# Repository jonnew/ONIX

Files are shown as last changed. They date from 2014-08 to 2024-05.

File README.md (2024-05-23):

# NOTE: This repository has been split into individual `onix-<project>` repos that are hosted on the [open-ephys github account](https://github.com/open-ephys). This repo has been archived.

[ONIX](https://open-ephys.github.io/onix-docs/index.html) is a collection
of [ONI](https://github.com/jonnew/ONI)-compatible hardware and API
for serialized, very-high channel count, closed-loop electrophysiology. It is
an evolution of the first-generation hardware and software introduced in [Open
Ephys project](http://www.open-ephys.org/) and involves many of the same
developers.  The firmware and API are general purpose -- they can be used to
acquire from and control custom headstages with arbitrary arrangements of
sensors and actuators (e.g. cameras, bioamplifier chips, LED drivers, etc.) and
are not limited to the hardware in this repository.

__Documentation__ : https://open-ephys.github.io/onix-docs/index.html

__Citing this work__: 

1. Citing the paper

  - TODO

2. Citing the repository itself

  - 

## Features
- Follows the [ONI](https://github.com/jonnew/ONI)-specification for serialization protocols, host communication
  protocols, device drivers, and host API
- Firmware and API permit acquisition and control of arbitrary arrangements of
  sensors and actuators:

    - Headstages
    - Miniscopes
    - Photometry systems
    - Etc.

- Submillisecond round-trip communication from brain, through host PC's main
  memory, and back again.
- Headstages:

    - 64-, 128-, 256-channels of electrophysiology
    - Optogenetic stimulation
    - Electrical stimulation
    - 3D-pose measurement
    - Data, user control, and power via a tiny coaxial cable
    - Wireless communication

- Low-level API implementation
- High-level API language bindings and existing integration with [Open Ephys
  GUI](http://www.open-ephys.org/gui/) and [Bonsai](http://bonsai-rx.org/).
- Quality documentation and easy routes to purchasing assembled devices.

## Software

1. API: https://github.com/jonnew/liboni
2. Bonsai package: coming soon
3. Open Ephys GUI plugin: coming soon

## Hardware

### [eib-64](eib-64/README.md)
64 Channel electrode interface board. Designed for small rodent tetrode
electrophysiology. Works with [headstage-64](./headstage-64/README.md).

### [eib-128](eib-128/README.md)
128 Channel electrode interface board. Designed for large rodent tetrode
electrophysiology. Works with [headstage-256](./headstage-256/README.md).

### [eib-256](eib-256/README.md)
256 Channel electrode interface board. Designed for large rodent tetrode
electrophysiology. Works with [headstage-256](./headstage-256/README.md).

### [headstage-64](headstage-64/README.md)
Serialized, multifunction headstage for small rodents. Supports 64 channels.
Designed to interface with [eib-64](./eib-64/README.md).

### [headstage-256](headstage-256/README.md)
Serialized, multifunction headstage for large rodents. Supports both 128 or 256
channels. Designed to interface with [eib-128](./eib-128/README.md) or
[eib-256](./eib-256/README.md)

### [fmc-host](fmc-host/README.md)
Base board for facilitating PCIe communication, via FMC compatiable and
PCIe-capable FPGA based board (e.g. [Numato Lab
Nereid](https://numato.com/product/nereid-kintex-7-pci-express-fpga-development-board).
This board plugs into the FMC connector on the base board. It provides
communication with one headstage and lots of other analog and digital IO.

### [analog-io-breakout](analog-io-breakout/README.md)
Passive breakout board for acquiring and generating analog signals through BNC,
SMA, ribbon, or straight wire connections. Plugs into fmc-host using a 26-pin
shrunk delta ribbon cable.

### [nanoz-adapter-64](./nanoz-adapter-64/README.md)
Adapter to interface eib-64 with the popular
[nanoZ](http://www.white-matter.com/nanoz/) electrode impedance tester and
plating device.

### [nanoz-adapter-128-256](./nanoz-adapter-128-256/README.md)
Multiplexed adapter to interface eib-128 and eib-256 with the popular
[nanoZ](http://www.white-matter.com/nanoz/) electrode impedance tester and
plating device.

### [test-board-64](./test-board-64)
Test board for headstage-64. Allows injecting simulated biopotentials into
headstage modules via a selectable passive attenuator. Provides LEDs and
simulated electrical loads for optical and electrical stimulation.

### [test-board-128-256](./test-board-128-256)
Test board for headstage, and headstage-256 modules. Allows injecting simulated
biopotentials into headstage modules via a selectable passive attenuator.
Provides LEDs and simulated electrical loads for optical and electrical
stimulation.

### [headstage-programmer](headstage-programmer/README.md)
JTAG breakout for the [Intel USB Blaster 2](https://www.digikey.com/short/qqw7hm)
used to program the headstages' MAX10 FPGA.

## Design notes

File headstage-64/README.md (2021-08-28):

:warning: This project has moved to a dedicated repository: https://github.com/open-ephys/onix-headstage-64
This folder should be considered archived.

# headstage-64
Serialized, multifunction headstage for small rodents. Designed to function
with [eib-64](../eib-64/README.md).

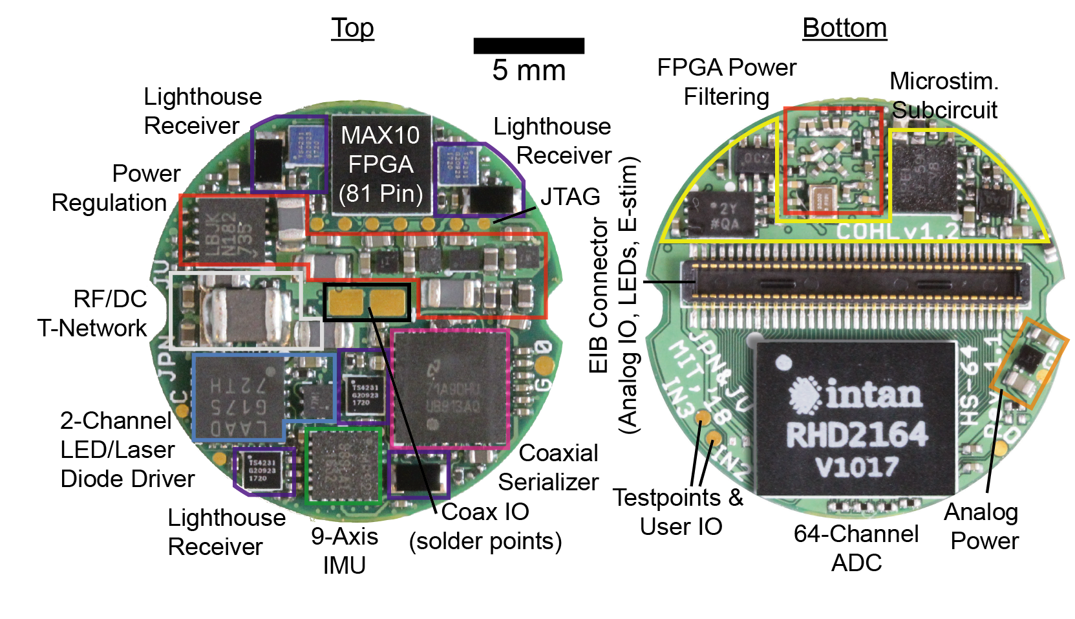
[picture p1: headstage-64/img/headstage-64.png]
headstage-64


## Electrophysiology
This heastage uses an [Intan RHD2164]() bioamplifier chip. This chip provides:
- 64 channels of ephys are pinned out through the large mezzanine connector on the
  bottom of the headstage
- 3 auxiliary channels
    - AUX 1 and 2 are pinned out on the bottom of the headstage to an unpopulated
      mezzanine connector
    - Channel 3 is tied to the electrical stimulator's current measurement circuit

## 3D Position Tracking
Headstage-64 featurs 4 TS4231 Vive lighthouse receivers for 3D position
tracking. They work with V2 lighthouses. To set up tracking,

1. Serial into each of the basestations using the USB connection on the back
   and set up a terminal conneciton using `screen /dev/ttyACM0 115200` or
   similar

2. Once connected you can hit Tab to see commands

3. Set the mode of one base staiton to 1 (mode 1) and the other to 2 (mode 2).

## 3D Orientation Tracking
TODO

## Neural Stimulators
Headstage-64 provides onboard electrical and optical stimulation. Stimulus
trains can be parameterized in a similar way to the master-8 or pulse pal.
Electical and optical stimulus trains cannot be delivered simultaneously.
If there is a conflict, electical stimuluation will take priority and optical
stimulus triggers will be ignored.

To acheive the shortest latency, electrical and optical stimulation can be triggered
using the GPIO1 serializer output. Because both stimulators share this trigger line,
it is important to only enable one of the devices (using its ENABLE register) prioir
to toggling this pin.

### Optical Stimulation

Q. Can i parallel the Cathode connections to increase max current
A. Yes.

### Electical Stimulation
The electrical stimulation cicuit is an improved Howland current pump followed by
an precision current measurement circuit. The current pump is supplied by +/-15V
rails and can supply up to +/- 2.5 mA. The output c

ISTIM = (VDAC  - 2.5)/1000.
e.g.
VDAC = 2.5   -> ISTIM = 0
VDAC = 5.0   -> ISTIM = 2.5 mA
VDAC = 0.0   -> ISTIM = -2.5mA

and

Imeas = 400 * ISTIM + 1.25V
e.g.
ISTIM = 0      -> IMEAS = 1.25V
ISTIM = 2.5mA  -> IMEAS = 2.25V
ISTIM = -2.5mA -> IMEAS = 0.25V

## Schematic
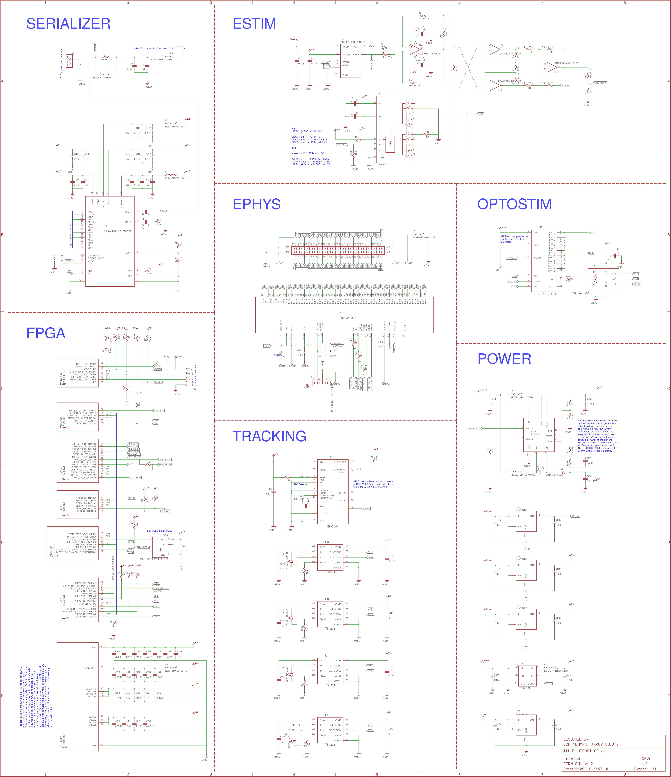
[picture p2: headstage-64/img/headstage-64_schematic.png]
headstage-64 Schematic


## Gerber Files
{% include gerber_layers.md %}

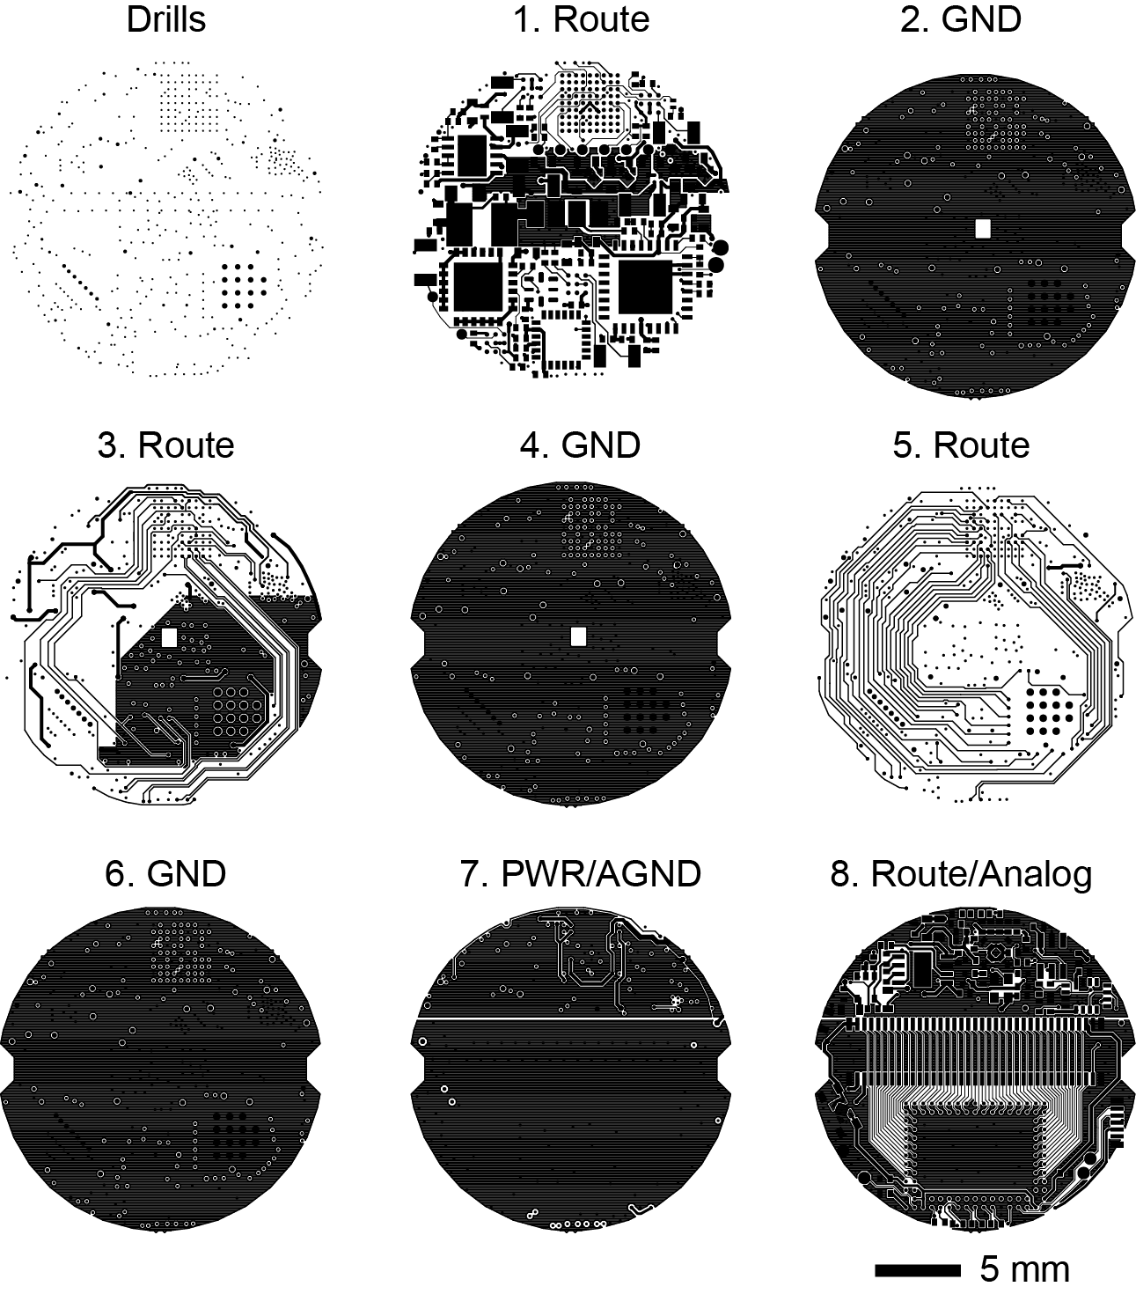
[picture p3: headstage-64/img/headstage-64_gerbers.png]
headstage-64 Gerbers


## Bill of Materials
The BOM is located on [this google
sheet](https://docs.google.com/spreadsheets/d/1F-KWcdvH_63iXjZf0cgCfDiFX6XXW3qw6rlR8DZrFpQ/edit#gid=138167638).

## FPGA Pinout
The FPGA pinout is located on [this google
sheet](https://docs.google.com/spreadsheets/d/1oJoQ89dJNL9LIiTrRnwJ_9KGiLzJ53Tju5Lfchuvsb0/edit#gid=2100166621).

## Connector Pinout
The headstage connector pinout (ADC input mapping, stimulation connections,
etc) is located on [this google
sheet](https://docs.google.com/spreadsheets/d/11wRDYOqHN5lPb03yUdfXfK0zvaDYsVetplaNK-R90Gg/edit#gid=663991061)

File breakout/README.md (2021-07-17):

:warning: This project has moved to a dedicated repository: https://github.com/open-ephys/onix-breakout
This folder should be considered archived.

# ONIX Breakout Board
This board allows bench access to the IO provided by the
[fmc-host board](../fmc-host/README.md). It features:

- 4x headstage ports, each with a power switch
- 3x, passive, high-seed clock feed throughs
- BNC, IDC (ribbon), or direct wire access to 12 analog inputs or outputs
- IDC (ribbon) or direct wire access to 8 digital outputs and 8 digital inpouts
- 6 buttons for marking experimental events
- 41 state-indication LEDs
- Full-speed, USB 2.0 access to the onboard [TinyFPGA
  BX](https://www.crowdsupply.com/tinyfpga/tinyfpga-bx) for communication,
  programming, and customization 
- HARP bus
- Rugged M6 or 1/4-20 mounting options compliant with 19" racks and optical
  tables
- Fully open-source gateware and use of fully open-source FPGA toolchain (yosys
  & nextpnr)

## Documentation
Documentation can be found
[here](https://open-ephys.github.io/onix-docs/Hardware%20Guide/Breakout%20Boards/breakout_1r4.html)

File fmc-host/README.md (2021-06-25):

:warning: This headstage has moved to a dedicated repository: https://github.com/open-ephys/onix-fmc-host.
This folder should be considered archived.

# FMC Host Board
This card serves as host interface for serialized headstages and miniscopes, as
well as general purpose analog and digital IO. This board is a VITA-57.1
compliant module that uses high pin-count FMC connector. In combination with a
base FPGA board (e.g. [Numato Lab
Nereid](https://numato.com/product/nereid-kintex-7-pci-express-fpga-development-board),
it provides host PC communication for the following:

- Two deserailizers for any multifunction headstage conforming to our
  serialization protocol
- 12x 16-bit, +/-10V analog outputs or inputs. Direction selected via analog
  switch controllable over the FMC connector. Analog inputs are separated into
  2 simultaneously sampled 6-channel banks. When analog outputs are used, they
  are are always looped back using the analog inputs.
- 3x high speed LVDS input pairs
- 2x high speed LVDS outputs pairs
- 2x high speed, arbitrary logic-level, singled-ended lock inputs
- 1x high speed single ended, 50 ohm clock output
- 4x MLVDS input or output trigger lines

Easy access to IO is provided by the [breakout board](../breakout/README.md).

pcie-host

## Gerber Files
{% include gerber_layers.md %}

## Bill of Materials
The bill of materials for this device can be found
[here](https://docs.google.com/spreadsheets/d/1F-KWcdvH_63iXjZf0cgCfDiFX6XXW3qw6rlR8DZrFpQ/edit#gid=1976092058).

## Manufacturing Requirements
In order to meet approximately correct trace impedances, the design assumes the following stackup:

1. Top Copper 0.035 mm
1. Prepreg (2313\*1) 0.1 mm
1. Inner Copper 0.0175 mm
1. Core (Copper) 0.565 mm
1. Inner Copper 0.0175 mm
1. Prepeg (2116\*1) 0.127 mm
1. Inner Copper 0.0175 mm
1. Core (Copper) 0.565 mm
1. Inner Copper 0.0175 mm
1. Prepreg (2313\*1) 0.1 mm
1. Bottom Copper 0.0175 mm

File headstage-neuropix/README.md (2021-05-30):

# ONIX headstage-neuropix1

:warning: This headstage has moved to a dedicated repository: https://github.com/open-ephys/onix-headstage-neuropix1.
This folder should be considered archived.

Serialized, multifunction headstage targeting the neuropixels 1.0 probe. This
headstage supports serialized acquisition from:

- Two neuropixels 1.0 probes
- A BNO055 9-axis IMU for real-time, 3D orientation tracking
- Three TS4231 light to digital converters for real-time, 3D position tracking
  with HTC Vive base stations
- A high performance MAX10 FPGA for real-time processing and probe data
  correction (offset removal and gain correction)

There are two versions of this headstage in this repository, one that uses the
standard IMEC-specified ZIF connector and a second that uses a larger, more
reliable one.

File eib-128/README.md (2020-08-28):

# eib-128
128-channel electrode interface board (EIB) with electrical and optical
stimulation. Designed for large animal (e.g. rat) tetrode electrophysiology.
Compatible with [headstage-256](../headstage-256/) and large shuttle-drives.

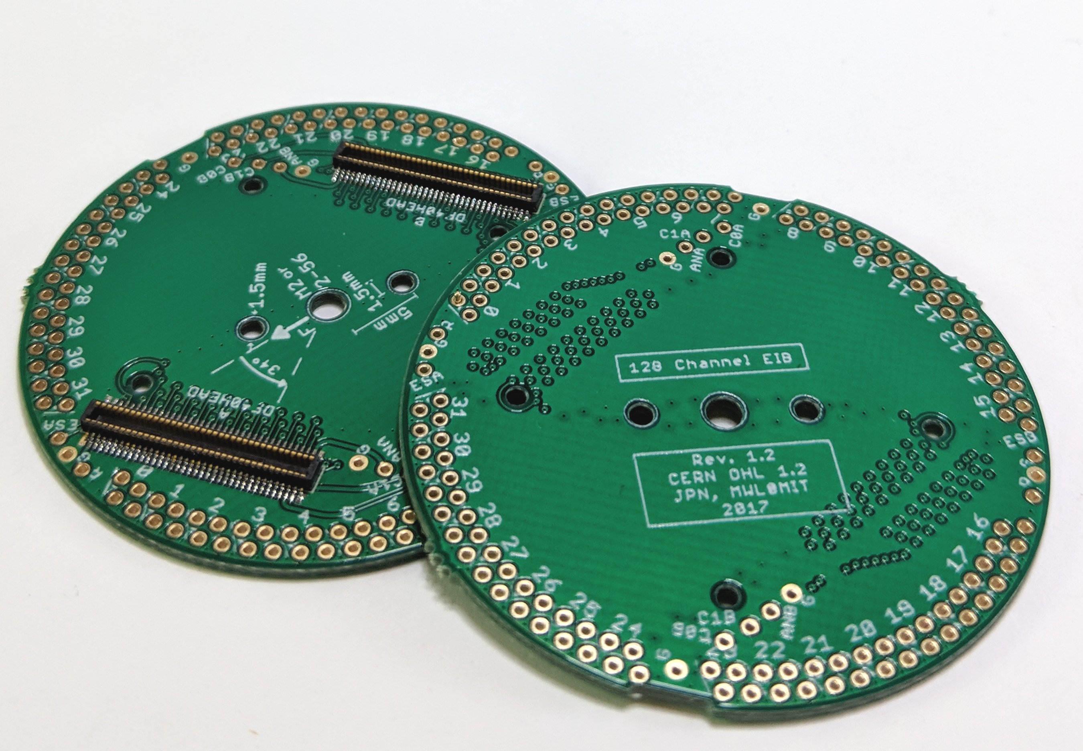
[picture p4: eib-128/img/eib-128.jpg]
eib-256


## Gerber Files
{% include gerber_layers.md %}

## Bill of Materials
The BOM is located on [this google
sheet](https://docs.google.com/spreadsheets/d/1F-KWcdvH_63iXjZf0cgCfDiFX6XXW3qw6rlR8DZrFpQ/edit#gid=1129179247).

## Pinout
The EIB pinout (ADC input mapping, stimulation connections, etc) is located on
[this google
sheet](https://docs.google.com/spreadsheets/d/11wRDYOqHN5lPb03yUdfXfK0zvaDYsVetplaNK-R90Gg/edit#gid=663991061)

## Tetrode Connectorization
This EIB uses Neuralynx ["large" gold pins](https://neuralynx.com/hardware/large-eib-pins) to attach tetrode wires. Usage instructions are provided in the [Neuralynx EIB pin Manual](https://neuralynx.com/documents/EIB%20Pins%20Manual.pdf).

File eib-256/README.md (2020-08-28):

# eib-256
256-channel electrode interface board (EIB) with electrical and optical
stimulation. Designed for large animal (e.g. rat) tetrode electrophysiology.
Compatible with [headstage-256](../headstage-256/) and large shuttle-drives.

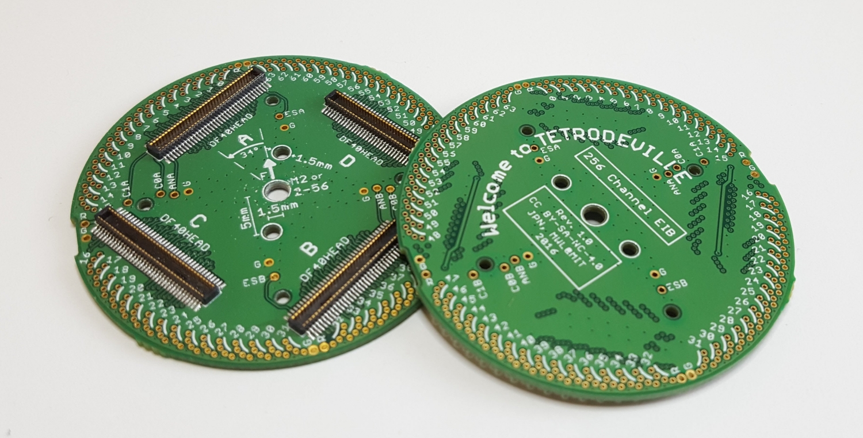
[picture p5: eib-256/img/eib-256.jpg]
eib-256


## Gerber Files
{% include gerber_layers.md %}

## Bill of Materials
The BOM is located on [this google
sheet](https://docs.google.com/spreadsheets/d/1F-KWcdvH_63iXjZf0cgCfDiFX6XXW3qw6rlR8DZrFpQ/edit#gid=1934583654).

## Pinout
The EIB pinout (ADC input mapping, stimulation connections, etc) is located on [this google sheet](https://docs.google.com/spreadsheets/d/11wRDYOqHN5lPb03yUdfXfK0zvaDYsVetplaNK-R90Gg/edit#gid=0)

## Tetrode Connectorization
This EIB uses Neuralynx ["small" gold pins](https://neuralynx.com/hardware/small-eib-pins) to attach tetrode wires. Usage instructions are provided in the [Neuralynx EIB pin Manual](https://neuralynx.com/documents/EIB%20Pins%20Manual.pdf).

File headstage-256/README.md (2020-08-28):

# headstage-256
Serialized, multifunction headstage for large rodents. Supports both 128 or 256
channels. Designed to interface with [eib-128](../eib-128/README.md) or
[eib-256](../eib-256/README.md)

headstage-256

## Schematic 
headstage-256 Schematic

## Gerber Files
{% include gerber_layers.md %}

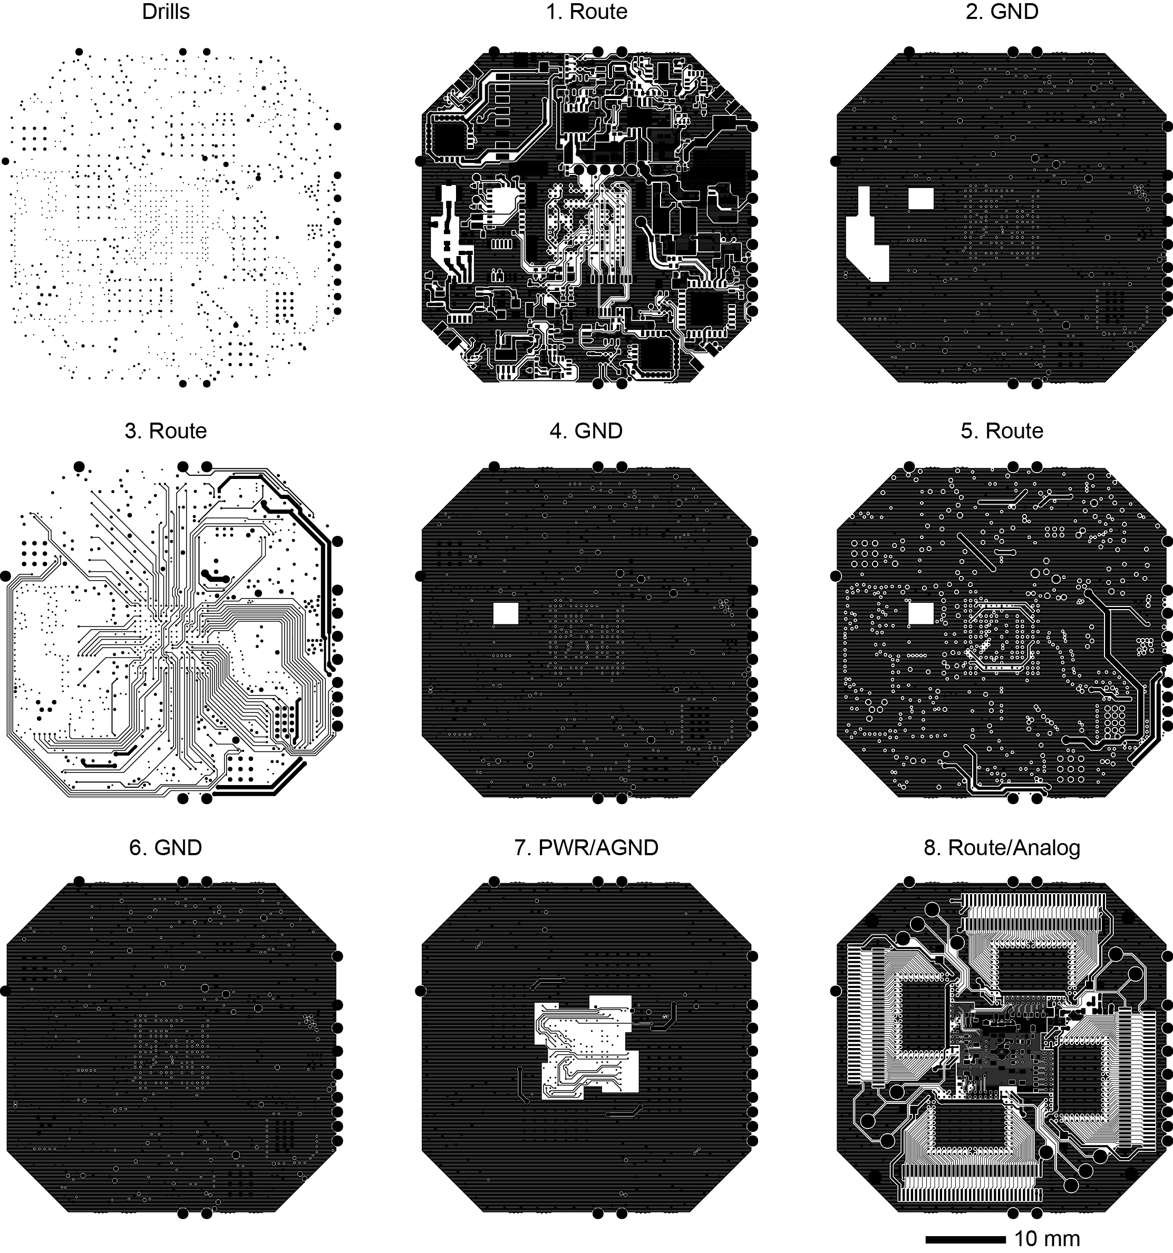
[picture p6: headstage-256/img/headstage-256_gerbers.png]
headstage-256 Gerbers


## Bill of Materials
The BOM is located on [this google
sheet](https://docs.google.com/spreadsheets/d/1F-KWcdvH_63iXjZf0cgCfDiFX6XXW3qw6rlR8DZrFpQ/edit#gid=1075887549)

## FPGA Pinout
The FPGA pinout is located on [this google
sheet](https://docs.google.com/spreadsheets/d/1oJoQ89dJNL9LIiTrRnwJ_9KGiLzJ53Tju5Lfchuvsb0/edit#gid=1588805600)

## Connector Pinout
The headstage connector pinouts (ADC input mapping, stimulation connections,
etc) ares are located on these google sheets:

- [eib-128 channel mapping](https://docs.google.com/spreadsheets/d/11wRDYOqHN5lPb03yUdfXfK0zvaDYsVetplaNK-R90Gg/edit#gid=663991061)
- [eib-256 channel mapping](https://docs.google.com/spreadsheets/d/11wRDYOqHN5lPb03yUdfXfK0zvaDYsVetplaNK-R90Gg/edit#gid=538743909)

## Expansion Boads
headstage-256 has two exposed headers that supply power and general purpose analog or digital IO to expand 
its functionality. Subdirectories with the prefix 'expansion` are boards that fit into these headers to 
supply various auxiliary functions. These include:

1. expansion-uphone: ultrasonic micrphone expansion board
2. expansion-long-range: large active area light house receiver board to expand 3D tracking range by several meters.
3. expansion-debug: pinout GPIO to large 0.1" pitch headers.

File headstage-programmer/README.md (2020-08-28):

# headstage-programmer
JTAG breakout for the [Intel USB Blaster
2](https://www.digikey.com/short/qqw7hm) used to program the headstages' MAX10
FPGA.

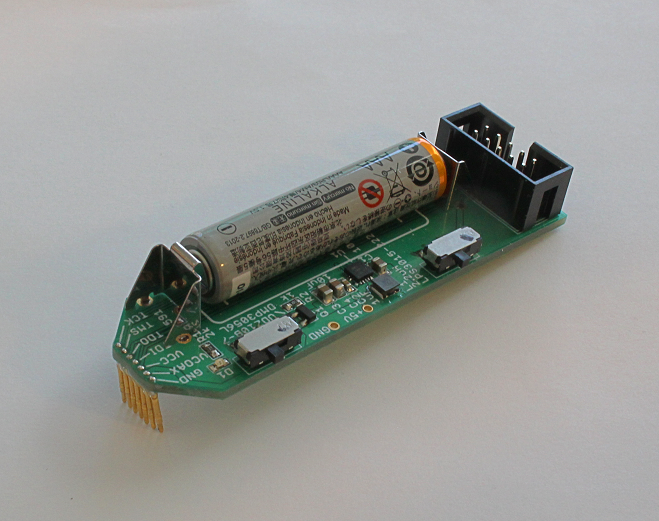
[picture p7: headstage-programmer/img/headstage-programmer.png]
headstage-programmer


## Schematic
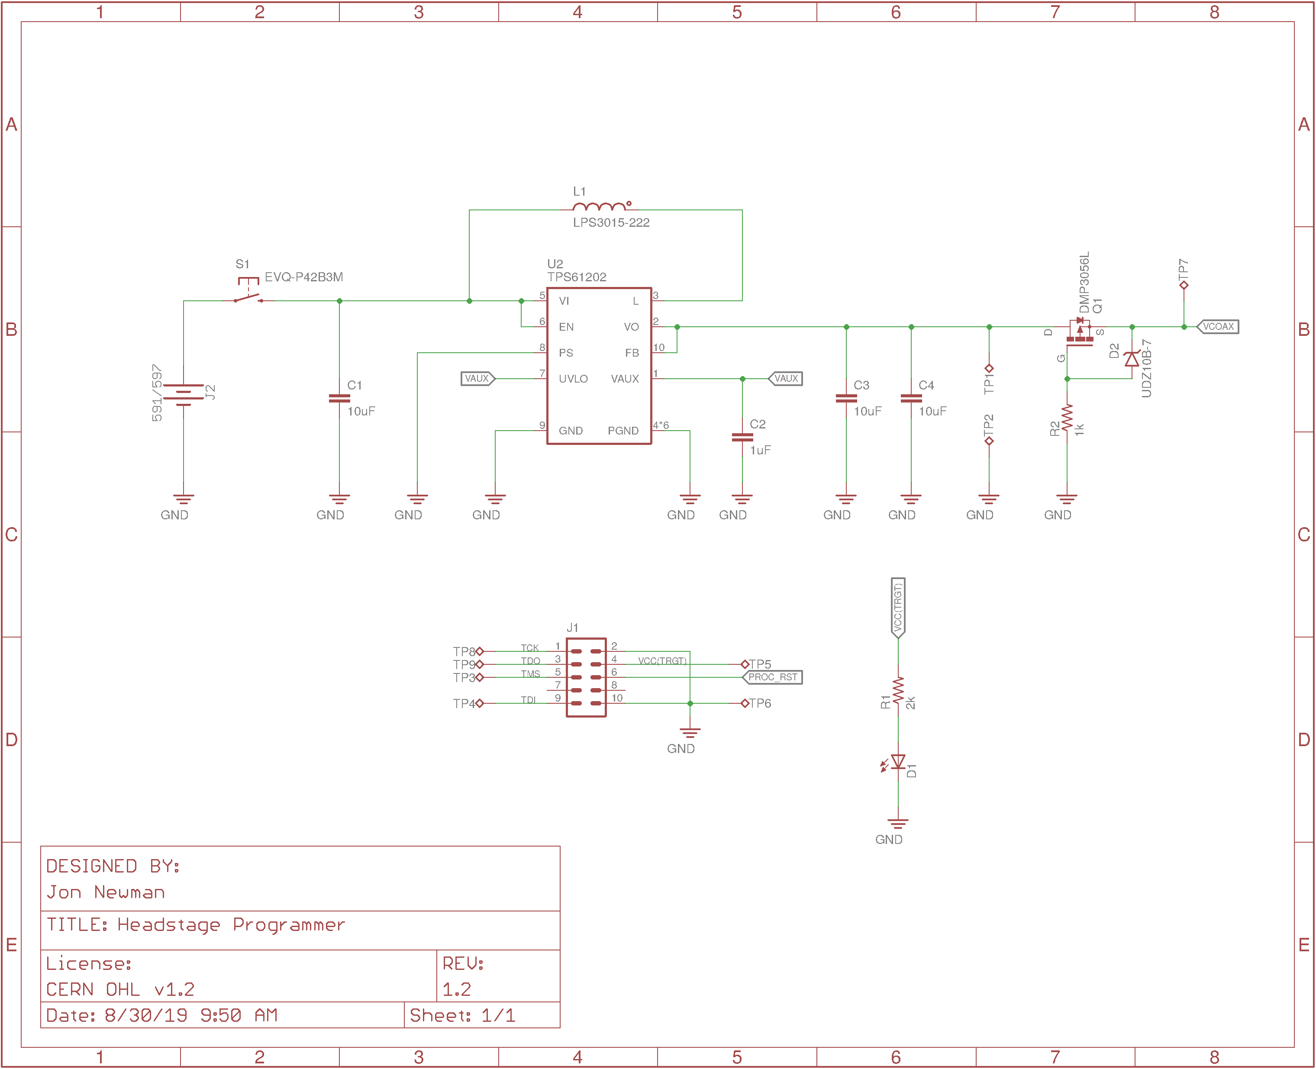
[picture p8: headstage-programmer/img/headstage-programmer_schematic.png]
headstage-programmer Schematic


## Purpose
The dense layout required by the headstages in this repository makes exposing a
FPGA programming interface challenging. We have chosen to expose a JTAG
programming interface as a linear, 50 mil pitch array of small copper ["test
points"](https://en.wikipedia.org/wiki/Test_point). This programmer adapter
routes JTAG signals through a set of small ["pogo
pins"](https://en.wikipedia.org/wiki/Pogo_pin) that can reliably make a
temporary electrical connection with the test point array. Additionally, it
contains a AAA battery and boost converter to generate power for the headstage
during programming and to illuminate a white LED on the bottom of the board
that eases pogo-pin/test-point alignment.

## Gerber Files
{% include gerber_layers.md %}

## BOM
The BOM is located on [this google
sheet](https://docs.google.com/spreadsheets/d/1F-KWcdvH_63iXjZf0cgCfDiFX6XXW3qw6rlR8DZrFpQ/edit#gid=673969549).

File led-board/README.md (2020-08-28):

# led-board
Simple board for making pig-tailed, drivable stimulation LEDs for optogenetic
manipulation.

## Gerber Files
{% include gerber_layers.md %}

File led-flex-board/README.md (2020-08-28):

### led-flex-board
Simple flexible board for making pig-tailed, driveable stimulation LEDs for
optogenetic manipulation using standard chip scale LEDs or direct-attach micro
LEDs.

## Gerber Files
{% include gerber_layers.md %}

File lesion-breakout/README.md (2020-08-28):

# Electro-lesioning breakout boards
These boards provide easy access to each tetrode on
[eib-64](../eib-64/README.md), [eib-128](../eib-128/README.md), and
[eib-256](../eib-256/README.md) for electro-lesioning or connectivity testing.

## Gerber Files
{% include gerber_layers.md %}

## Bill of Materials
The BOM is located on [this google
sheet](https://docs.google.com/spreadsheets/d/1F-KWcdvH_63iXjZf0cgCfDiFX6XXW3qw6rlR8DZrFpQ/edit#gid=1934583654).

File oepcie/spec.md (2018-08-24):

---
title: |
    Open Ephys++ Communication Protocol and API Specification \
    Version 0.0
author: Jonathan P. Newman, Wilson Lab, MIT
institution:
date: \today{}
geometry: margin=2cm
header-includes:
    - \usepackage{setspace}
    - \usepackage{lineno}
    - \linenumbers
colorlinks: true
toc: true
toc-depth: 2
secnumdepth: 2
abstract: |
    This document specifies requirements for implementing the Open Ephys++ data
    acquisition system. This specification entails two basic elements: (1)
    Communication protocols between acquisition firmware and host software and
    (2) an application programming interface (API) for utilizing this
    communication protocol. This document is incomplete and we gratefully
    welcome criticisms and amendments.
---

\newpage
# Intentions and capabilities
- Low latency (sub millisecond)
- High bandwidth (> 1000 neural data channels)
- Bidirectional
- Acquisition and control of arbitrary of hardware components using a single
  communication medium
    - Support generic mixes of hardware elements
    - Generic hardware configuration
    - Generic data input stream
    - Generic data output stream
- Support multiple acquisition systems on one computer
- Cross platform
- Low level: aimed at the creation of language bindings and
  application-specific libraries

\newpage
# FPGA/Host PC communication {#comm-protocol}
Communication between the acquisition board firmware and API shall occur
over four communication channels:

1. Signal: Read-only, short-message, asynchronous hardware events
2. Configuration: Bidirectional, register-based, synchronous configuration
   setting and getting
3. Input: Read-only, asynchronous, high-bandwidth firmware to host streaming
4. Output: Write-only, asynchronous, high-bandwidth host to firmware streaming

Required characteristics of these channels are described in the following
paragraphs.

## Signal channel (8-bit, asynchronous, read only) {#sig-chan}
The _signal_ channel provides a way for the FPGA firmware to inform host of
configuration results, which may be provided with a significant delay.
Additionally, it allows the host to read the device map supported by the FPGA
firmware. The behavior of the signal channel is equivalent to a read-only,
blocking UNIX named pipe. Signal data is framed into packets using Consistent
Overhead Byte Stuffing
([COBS](https://en.wikipedia.org/wiki/Consistent_Overhead_Byte_Stuffing)).
Within this scheme, packets are delimited using 0's and always have the
following format:

```
... | PACKET_FLAG data | ...
```

where `PACKET_FLAG` is 32-bit unsigned integer with a single unique bit
setting, ` | ` represents a packet delimiter, and `...` represents other
packets. This stream can be read and ignored  until a desired packet is
received. Reading this stream shall block if no data is available, which allows
asynchronous configuration acknowledgment. Valid `PACKET_FLAG`s are:

``` {.c}
enum signal {
    NULLSIG      = (1u << 0), // Null signal, ignored by host
    CONFIGWACK   = (1u << 1), // Configuration write-acknowledgment
    CONFIGWNACK  = (1u << 2), // Configuration no-write-acknowledgment
    CONFIGRACK   = (1u << 3), // Configuration read-acknowledgment
    CONFIGRNACK  = (1u << 4), // Configuration no-read-acknowledgment
    DEVICEMAPACK = (1u << 5), // Device map start acknowledgment
    DEVICEINST   = (1u << 6), // Device map instance
};
```

Following a hardware reset, the signal channel is used to provide the device
map to the host using the following packet sequence:

```
... | DEVICEMAPACK, uint32_t num_devices | DEVICEINST device dev_0
    | DEVICEINST device dev_1 | ... | DEVICEINST device dev_n | ...
```

Following a device register read or write (see [configuration
channel](#conf-chan)), ACK or NACK signals are pushed onto the signal stream by
the firmware. For instance, on a successful register read:

```
... | CONFIGRACK, uint32_t register value | ...
```

## Configuration channel (32-bit, synchronous, read and write) {#conf-chan}
The _configuration_ channel supports seeking to, reading, and writing a set of
configuration registers. Its behavior is equivalent to that of a normal UNIX
file. There are two classes of registers handled by the configuration channel:
the first set of registers encapsulates a generic device register programming
interface. The remaining registers are for global context control and
configuration and provide access to acquisition parameters and state control.
`SEEK` locations of each configuration register, relative to the start of the
stream, should be hard-coded into the API implementation file and used in the
background to manipulate register state.

### Device register programming interface

The device programming interface is composed of the following configuration
channel registers:

- `uint32_t config_device_id`: Device ID register. Specify a device endpoint as
  enumerated by the firmware (e.g. an Intan chip, or a IMU chip) and to which
  communication will be directed using `config_reg_addr` and
  `config_reg_value`, as described below.

- `uint32_t config_reg_addr`: The register address of configuration to be
  written

- `uint32_t config_reg_value`: configuration value to be written to or read
  from and that corresponds to `config_reg_addr` on device `config_device_id`

- `uint32_t config_rw`: A flag indicating if a read or write should be
  performed.  0 indicates read operation. A value > 0 indicates write
  operation.

- `uint32_t config_trig`: Set > 0 to trigger either register read or write
  operation depending on the state of `config_rw`. If `config_rw` is 0, a read
  is performed. In this case `config_reg_value` is updated with value stored at
  `config_reg_addr` on device at `config_device_id`. If `config_rw` is 1,
  `config_reg_value` is written to register at `config_reg_addr` on device
  `config_device_id`. The `config_trig` register is always be set low by the
  firmware following transmission even if it is not successful or does not make
  sense given the address register values.

Appropriate values of `config_reg_addr` and `config_reg_value` are
determined by:

- Looking at a device's data sheet if the device is an integrated circuit
- Examining the open ephys++ devices header file (oedevices.h) which
  contains off register addresses and descriptions for devices officially
  supported by this project (device id < 10000).

When a host requests a device register _read_, the following following actions
take place:

1. The value of `config_trig` is checked.
    - If it is 0x00, the function call proceeds.
    - Else, the function call returns with an error specifying a retrigger.
1. `dev_idx` is copied to the `config_device_id` register on the host FPGA.
1. `addr` is copied to the `config_reg_addr` register on the host FPGA.
1. The `config_rw` register on the host FPGA is set to 0x00.
1. The `config_read_trig` register on the host FPGA is set to 0x01,
triggering configuration transmission by the firmware.
1. (Firmware) A configuration read is performed by the firmware.
1. (Firmware) `config_trig` is set to 0x00 by the firmware.
1. (Firmware) `CONFIGRACK` is pushed onto the signal stream by the
firmware.
1. The signal stream is pumped until either `CONFIGRACK` or `CONFIGRNACK` is
   received indicating that the host FPGA has either:
    - Completed reading the specified device register and copied its value to
      the `config_reg_value` register.
    - Failed to read the register in which case the value of `config_reg_value`
      contains garbage.

When a host requests a device register _write_, the following following actions
take place:

1. The value of `config_trig` is checked.
    - If it is 0x00, the function call proceeds.
    - Else, the function call returns with an error specifying a retrigger.
1. `dev_idx` is copied to the `config_device_id` register on the host FPGA.
1. `addr` is copied to the `config_reg_addr` register on the host FPGA.
1. `value` is copied to the `config_reg_value` register on the host FPGA.
1. The `config_rw` register on the host FPGA is set to 0x01.
1. The `config_trig` register on the host FPGA is set to 0x01, triggering
configuration transmission by the firmware.
1. (Firmware) A configuration write is performed by the firmware.
1. (Firmware) `config_trig` is set to 0x00 by the firmware.
1. (Firmware) `CONFIGWACK` is pushed onto the signal stream by the
firmware.
1. The signal stream is pumped until either `CONFIGWACK` or `CONFIGwNACK` is
   received indicating that the host FPGA has either:
    - Successfully completed writing the specified device register
    - Failed to write the register

Following successful or unsuccessful device register read or write, the
appropriate ACK or NACK packets _must_ be passed to the [signal
channel](#sig-chan). If they are not, the register read and write calls will
block indefinitely.

### Global acquisition registers
The following global acquisition registers provide information about, and
control over, the entire acquisition system:

- `uint32_t running`: set to > 0 to run the system clock and produce data. Set
  to 0 to stop the system clock and therefore stop data flow. Results in no
  other configuration changes.

- `uint32_t reset`: set to > 0 to trigger a hardware reset and send a fresh
  device map to the host and reset hardware to its default state. Set to 0 by
  host firmware upon entering the reset state.

- `uint32_t sys_clock_hz`: A read-only register specifying the base hardware
  clock frequency in Hz. The clock counter in the read [frame](#frame) header
  is incremented at this frequency.

## Data input channel (32-bit, asynchronous, read-only)
The _data input_ channel provides high bandwidth communication from the FPGA
firmware to the host computer using direct memory access (DMA). From the host's
perspective, its behavior is equivalent to a read-only, blocking UNIX named
pipe with the exception that data can only be read on 32-bit, instead of 8-bit,
boundaries. The data input channel communicates with the host using
[frames](#frame) with a read-header ("read-frames") .Read-frames are pushed
into the data input channel at a rate dictated by the FPGA firmware. It is
incumbent on the host to read this stream fast enough to prevent buffer
overflow. At the time of this writing, a typical implementation will allocate
an input buffer that occupies a 512 MB segment of kernal RAM. Increased
bandwidth demands will necessitate the creation of a user-space buffer. This
change shall have no effect on the API.

## Data output channel (32-bit, asynchronous, write-only)
The _data output_ channel provides high bandwidth communication from the host
computer to the FPGA firmware using DMA via calls. From the host's perspective,
its behavior is equivalent to a write-only, blocking UNIX named pipe with the
exception that data can only be written on 32-bit, instead of 8-bit,
boundaries. Its performance characteristics are largely identical to the data
input channel.

\newpage

# Required API Types and Behavior {#api-spec}
In the following sections we define required API datatypes and how they are
used by the API to communicate with hardware. An implementation of this API,
[liboepcie](#api-imp), follows.

## Context
A _context_ shall hold all state required to manage single [FPGA/Host
communication system](#comm-protocol). This includes a
map of devices being acquired from, data buffering elements, etc. API calls
will typically take a context handle as the first argument and use it to
reference required state information to enable communication and/or to mutate
the context to reflect some function side effect (e.g. add device map
information):

```
int api_function(context *ctx, ...);
```

## Device
A _device_ is defined as configurable piece of hardware with its own register
address space (e.g. an integrated circuit) or something programmed within the
firmware to emulate this (e.g. an electrical stimulation sub-circuit made to
look like a Master-8). Host interaction with a device is facilitated using a
device description, which should hold the following elements:

- `device_id`: Device ID number
- `read_size`: Device data read size per frame in bytes
- `num_reads`: Number of frames that must be read to construct a full
  sample (e.g., for row reads from camera)
- `write_size`: Device data write size per frame in bytes
- `num_writes`: Number of frames that must be written to construct a full
  output sample

An array of structures holding each of these entries forms a _device map_.  A
context is responsible for managing a single device map, which keep track of
where to send and receive streaming data and configuration information during
API calls. A detailed description of each of each value comprising a device
instance is as follows:

1. `device_id`: Device identification number which is globally
   enumerated for the entire project
    - There is a single `enum` for the entire library which enumerates all
      possible devices that are controlled across `context` configurations.
      This enumeration will grow with the number of devices supported by the
      library.
    - e.g. A host board GPIO subcircuit is 0, Intan RHD2132 is 1, Intan
      RHD2164 is 2, etc.
    - Device IDs up to 9999 are reserved. Device ID 10000 and greater are free
      to use for custom hardware projects.
    - The use of device IDs less than 10000 not specified within this
      enumeration will result in OE_EDEVID errors.
    - Device numbers greater than 1000 are allowed for general purpose use and
      will not be verified by the API.
    - Incorporation into the official device enum (device IDs < 10000) can be
      achieved via pull-request to this repo.

2. `read_size`: Number of bytes of data transmitted by this device during a
    single read.
    - 0 indicates that it does not send data.

3. `num_reads`: Number of reads required to construct a full device read sample
   (e.g., number of columns when `read_size` corresponds to a single row of
   pixels from a camera sensor)

4. `write_size`: Number of bytes accepted by the device during a single write
    - 0 indicates that it does not send data.

5. `num_writes`: Number of writes required to construct a full device output
   sample.

## Frame
A _frame_ is a flat byte array containing a single sample's worth of data for a
set (one to all) of devices within a device map. Data within frames is arranged
into three memory sectors as follows:

```
[32 byte header,                              // 1. Header
 dev_0 idx, dev_1 idx, ... , dev_n idx,       // 2. Device map indices
 dev_0 data, dev_1 data, ... , dev_n data]    // 3. Data

```
Each frame memory sector is described below:

1. Header
    - Each frame starts with a 32-byte header
    - For reading (firmware to host) operations, the header contains
        - bytes 0-7: unsigned 64-bit integer holding system clock counter
        - bytes 8-9: unsigned 16-bit integer indicating number of devices that
          the frame contains data for
        - byte 10: 8-bit integer speficying fame error state. frame error. 0 =
          OK. 1 = data may be corrupt.
        - bytes 11-32: reserved

    - For writing (host to firmware) operations , the header contains
        - bytes 0-32: reserved

2. Device map indices
    - An array of unsigned 32-bit keys corresponding the device map captured by
      the host during context initialization
    - The offset, size, and type information of the _i_th data block within the
      `data` section of each frame is determined by examining the _i_th member
      of the device map.

3. Data
    - Raw data blocks from each device in the device map.
    - The ordering of device-specific blocks is the same as the device index
      within the _device map index_ portion of the frame
    - The read/write size for each device-specific block is provided in the
      device map
    - Perhaps in the future, data type casting information can be provided in
      the device map, but this is not currently required.

\newpage
# `liboepcie`: An Open Ephys ++ API Implementation {#api-imp }

## Scope and External Dependencies
`liboepcie` is a C library that implements the [Open Ephys++ API
Specification](#api-spec). It is written in C to facilitate
cross platform and cross-language use. It is composed of two mutually
exclusive file pairs:

1. oepcie.h and oepcie.c: main API implementation
1. oedevice.h and oedevices.c: officially supported device and register
   definitions. This file can be ignored for project that do not wish to
   conform to the official device specification.

`liboepcie` is a low level library used by high-level language binding and/or
software plugin developers. It is not meant to be used by neuroscientists
directly. The only external dependency aside from the C standard library is is
a hardware communication backend that fulfills the requirements of the
[FPGA/Host Communication
Specification](#comm-protocol). An example of such
a backend is [Xillybus](http://xillybus.com/), which provides proprietary FPGA
IP cores and free and open source device drivers to allow the communication
channels to be implemented using the PCIe bus. From the API's perspective,
hardware communication abstracted to IO system calls (`open`, `read`,
`write`, etc.) on file descriptors.  File descriptor semantics and behavior
are identical to either normal files (configuration channel) or named pipes
(signal, data input, and data output channels). Because of this, a drop in
replacement for the Xillybus IP Core can be used without any API changes.  The
development of a free and open-source FPGA cores that emulate the functionality
of Xillybus would be a major benefit to the systems neuroscience community.

Importantly, the low-level synchronization, resource allocation, and logic
required to use the hardware communication backend is implicit to `liboepcie`
API function calls. Orchestration of the communication backend _is not directly
managed by the library user_.

## License
[MIT](https://en.wikipedia.org/wiki/MIT_License)

## Types

### Integer types
- `oe_size_t`: Fixed width size integer type.
- `oe_dev_id_t`: Fixed width device identity integer type.
- `oe_reg_addr_t`: Fixed width device register address integer type.
- `oe_reg_value_t`: Fixed width device register value integer type.

### `oe_ctx`
[Context](#context) implementation. `oe_ctx` is an opaque handle to a context
structure which contains hardware and device state information.

```
// oepcie.h
typedef struct oe_ctx_impl *oe_ctx;
```

Context details are hidden in implementation file (oepcie.c):

``` {.c}
typedef struct stream_fid {
    char *path;
    int fid;
} stream_fid_t;

typedef struct oe_ctx_impl {

    // Communication channels
    stream_fid_t config;
    stream_fid_t read;
    stream_fid_t write;
    stream_fid_t signal;

    // Devices
    oe_size_t num_dev;
    oe_device_t* dev_map;

    // Maximum frame sizes (bytes)
    oe_size_t max_read_frame_size;
    oe_size_t write_frame_size;

    // Data buffer
    uint8_t *buffer;
    uint8_t *buff_read_pos;
    uint8_t *buff_end_pos;

    // Acqusition state
    enum run_state {
        CTXNULL = 0,
        UNINITIALIZED,
        IDLE,
        RUNNING
    } run_state;

} oe_ctx_impl_t;
```

Each context manages a single device map. Following a hardware reset, which is
triggered either by a call to `oe_init_ctx` or to `oe_set_ctx` using the
`OE_RESET` option, the context `run_state` is set to UNINTIALIZED and the device map is
pushed onto the signal stream by the FPGA as
[COBS](https://en.wikipedia.org/wiki/Consistent_Overhead_Byte_Stuffing) encode
packets. On the signal stream, the device map is organized as follows,

... | DEVICEMAPACK, uint32_t num_devices | DEVICEINST oe_device_t dev_0
    | DEVICEINST oe_device_t dev_1 | ... | DEVICEINST oe_device_t dev_n | ...

where | represents '0' packet delimiters. During a call to `oe_init_ctx`, the
device map is decoded from the signal stream. It can then be examined using
calls to `oe_get_opt` using the `OE_DEVICEMAP` option. After the map is
received, the context `run_state` becomes IDLE. A call to `oe_set_ctx` with the
`OE_RUNNING` option can then be used to start acquisition by transitioning the
context `run_state` to `RUNNING`.

### `oe_device_t`
[Device](#device) implementation. An `oe_device_t` describes one of potentially
many pieces of hardware within a context. Examples include Intan chips, IMUs,
optical stimulator's, camera sensors, etc. Each valid device type has a unique
ID which is enumerated in the auxiliary `oedevices.h` file or some use-specific
header. A map of available devices is read from hardware and stored in the
current context via a call to [`oe_init_ctx`](#oe_init_ctx).  This map can be
examined via calls to [`oe_get_opt`](#oe_get_opt).

``` {.c}
typedef struct {
    oe_dev_id_t id;         // Device ID number
    oe_size_t read_size;    // Device data read size per frame in bytes
    oe_size_t num_reads;    // Number of read frames to construct a full sample
    oe_size_t write_size;   // Device data write size per frame in bytes
    oe_size_t num_writes;   // Number of written frames comprising a full sample
} oe_device_t;
```

Officially supported device IDs and configuration register definitions are
provided in oedevices.h as a set of enumerations. A portion of the official
device ID enumeration is defined as follows:

``` {.c}
typedef enum device_id {
    OE_IMMEDIATEIO = 0,
    OE_RHD2132,
    OE_RHD2164,
    OE_MPU9250,
    OE_ESTIM,
    ...
    OE_MAXDEVICEID = 9999
} oe_device_id_t

```

An example of a device register (for the `OE_ESTIM` device ID) enumeration is:

``` {.c}
enum oe_estim_regs {
    OE_ESTIM_NULLPARM    = 0,  // No command
    OE_ESTIM_BIPHASIC    = 1,  // Biphasic pulse (0 = monophasic, 1 = biphasic;
    OE_ESTIM_CURRENT1    = 2,  // Phase 1 current, (0 to 255 = -1.5 mA to +1.5mA)
    OE_ESTIM_CURRENT2    = 3,  // Phase 2 voltage, (0 to 255 = -1.5 mA to +1.5mA)
    OE_ESTIM_PULSEDUR1   = 4,  // Phase 1 duration, 10 microsecond steps
    OE_ESTIM_IPI         = 5,  // Inter-phase interval, 10 microsecond steps
    OE_ESTIM_PULSEDUR2   = 6,  // Phase 2 duration, 10 microsecond steps
    OE_ESTIM_PULSEPERIOD = 7,  // Inter-pulse interval, 10 microsecond steps
    OE_ESTIM_BURSTCOUNT  = 8,  // Burst duration, number of pulses in burst
    OE_ESTIM_IBI         = 9,  // Inter-burst interval, microseconds
    OE_ESTIM_TRAINCOUNT  = 10, // Pulse train duration, number of bursts in train
    OE_ESTIM_TRAINDELAY  = 11, // Pulse train delay, microseconds
    OE_ESTIM_TRIGGER     = 12, // Trigger stimulation (1 = deliver)
    OE_ESTIM_POWERON     = 13, // Control estim sub-circuit power (0 = off, 1 = on)
    OE_ESTIM_ENABLE      = 14, // Control null switch (0 = stim output shorted to ground, 1 = enabled)
    OE_ESTIM_RESTCURR    = 15, // Current between pulse phases, (0 to 255 = -1.5 mA to +1.5mA)
	OE_ESTIM_RESET		 = 16, // Reset all parameters to default
};
```

These registers may be familiar to those who have used a Master-8 or
[pulse-pal](https://sites.google.com/site/pulsepalwiki/) stimulus sequencer.

### `oe_frame_t`
[Frame](#frame) implementation. Frames are produced by calls `oe_read_frame`
and provided to calls to `oe_write_frame`.

``` {.c}
typedef struct oe_frame {
    uint64_t clock;         // Base clock counter
    uint16_t num_dev;       // Number of devices in frame
    uint8_t corrupt;        // Is this frame corrupt?
    oe_size_t *dev_idxs;    // Array of device indices in frame
	oe_size_t dev_idxs_sz;  // Size in bytes of dev_idxs buffer
	oe_size_t *dev_offs;    // Device data offsets within data block
	oe_size_t dev_offs_sz;  // Size in bytes of dev_idxs buffer
    uint8_t *data;          // Multi-device raw data block
	oe_size_t data_sz;      // Size in bytes of data buffer

} oe_frame_t;
```

### `oe_opt_t`
Context option enumeration. See the description of `oe_set_opt` and
`oe_get_opt` for valid values.

### `oe_error_t`
Error code enumeration.

``` {.c}
typedef enum oe_error {
    OE_ESUCCESS         =  0,  // Success
    OE_EPATHINVALID     = -1,  // Invalid stream path, fail on open
    OE_EREINITCTX       = -2,  // Double initialization attempt
    OE_EDEVID           = -3,  // Invalid device ID on init or reg op
    OE_EREADFAILURE     = -4,  // Failure to read from a stream/register
    OE_EWRITEFAILURE    = -5,  // Failure to write to a stream/register
    OE_ENULLCTX         = -6,  // Attempt to call function w null ctx
    OE_ESEEKFAILURE     = -7,  // Failure to seek on stream
    OE_EINVALSTATE      = -8,  // Invalid operation for the current context run state
    OE_EDEVIDX          = -9,  // Invalid device index
    OE_EINVALOPT        = -10, // Invalid context option
    OE_EINVALARG        = -11, // Invalid function arguments
    OE_ECANTSETOPT      = -12, // Option cannot be set in current context state
    OE_ECOBSPACK        = -13, // Invalid COBS packet
    OE_ERETRIG          = -14, // Attempt to trigger an already triggered operation
    OE_EBUFFERSIZE      = -15, // Supplied buffer is too small
    OE_EBADDEVMAP       = -16, // Badly formated device map supplied by firmware
    OE_EBADALLOC        = -17, // Bad dynamic memory allocation
    OE_ECLOSEFAIL       = -18, // File descriptor close failure, check errno
    OE_EDATATYPE        = -19, // Invalid underlying data types
    OE_EREADONLY        = -20, // Attempted write to read only object (register, context option, etc)
    OE_ERUNSTATESYNC    = -21, // Software and hardware run state out of sync
    OE_EINVALRAWTYPE    = -22, // Invalid raw data type
    OE_EUNIMPL          = -23, // Specified, but unimplemented, feature
} oe_error_t;
```

## oe_create_ctx
Create a hardware context. A context is an opaque handle to a structure which
contains hardware and device state information, configuration capabilities, and
data format information. It can be modified via calls to `oe_set_opt`. Its
state can be examined by `oe_get_opt`.

``` {.c}
oe_ctx oe_create_ctx()
```

### Returns `oe_ctx`
An opaque handle to the newly created context if successful. Otherwise it shall
return NULL and set errno to `EAGAIN`.

### Description
On success a context struct is allocated and created, and its handle is passed
to the user. The context holds all state used by the library function calls for
refection and hardware communication. It holds paths to FIFOs and configuration
communication channels and knowledge of the hardware's parameters and run state
. It is configured through calls to `oe_set_opt`. It can be examined through
calls to `oe_get_opt`.

## oe_init_ctx
Initialize a context, opening all file streams etc.

``` {.c}
int oe_init_ctx(oe_ctx ctx)
```

### Arguments
- `ctx` context

### Returns `int`
- 0: success
- Less than 0: `oe_error_t`

### Description
Upon a call to `oe_init_ctx`, the following actions take place

1. All required data streams are opened.
2. A device map is read from the firmware. It can be examined via calls t
   `oe_get_opt`.
3. The data transmission packet size is calculated and stored. It can be
   examined via calls t `oe_get_opt`.

Following a successful call to `oe_init_ctx`, the hardware's acquisition
parameters and run state can be manipulated using calls to `oe_get_opt`.

## oe_destroy_ctx
Terminate a context and free bound resources.

``` {.c}
int oe_destroy_ctx(oe_ctx ctx)
```

### Arguments
- `ctx` context

### Returns `int`
- 0: success
- Less than 0: `oe_error_t`

### Description
During context destruction, all resources allocated by `oe_create_ctx` are
freed. This function can be called from any context run state. When called, an
interrupt signal (TODO: Which?) is raised and any blocking operations will
return immediately. Attached resources (e.g. file descriptors and allocated
memory) are closed and their resources freed.

## oe_get_opt
Get context options.

``` {.c}
int oe_get_opt(const oe_ctx ctx, int option, void* value, size_t *size);
```

### Arguments
- `ctx` context to read from
- `option` option to read
- `value` buffer to store value of `option`
- `size` pointer to the size of `value` (including terminating null character,
  if applicable) in bytes

### Returns `int`
- 0: success
- Less than 0: `oe_error_t`

### Description
The `oe_get_opt` function sets the option specified by the `option` argument
to the value pointed to by the `value` argument for the context pointed to by
the `ctx` argument. The `size` provides a pointer to the size of the option
value in bytes. Upon successful completion `oe_get_opt` shall modify the value
pointed to by `size` to indicate the actual size of the option value stored in
the buffer.

Following a successful call to `oe_init_ctx`, the following socket options
can be read:

#### `OE_CONFIGSTREAMPATH`\*
Obtain path specifying config data stream.

| | |
|---|---|
| option value type | `char *` |
| option description  | A character string specifying the configuration stream path |
| default value | /dev/xillybus_oe_config_32, \\\\.\\xillybus_oe_config_32 (Windows) |

#### `OE_READSTREAMPATH`\*
Obtain path specifying input data stream.

| | |
|---|---|
| option value type | `char *` |
| option description  | A character string specifying the input stream path |
| default value | /dev/xillybus_oe_input_32 \\\\.\\xillybus_oe_input_32 (Windows) |

#### `OE_WRITESTREAMPATH`\*
Obtain path specifying input data stream.

| | |
|---|---|
| option value type | `char *` |
| option description  | A character string specifying the output stream path |
| default value | /dev/xillybus_oe_output_32, \\\\.\\xillybus_oe_output_32 (Windows) |

#### `OE_SIGNALSTREAMPATH`\*
Obtain path specifying hardware signal data stream

| | |
|---|---|
| option value type | `char *` |
| option description  | A character string specifying the signal stream path |
| default value | /dev/xillybus_oe_signal_8, \\\\.\\xillybus_oe_signal_8 (Windows) |

#### `OE_DEVICEMAP`
The device map.

| | |
|---|---|
| option value type	  | `oe_device_t *` |
| option description  | Pointer to a pre-allocated array of `oe_device_t` structs |
| default value	 | N/A |

#### `OE_NUMDEVICES`
The number of devices in the device map.

| | |
|---|---|
| option value type | `oe_reg_val_t` |
| option description  | The number of devices supported by the firmware |
| default value | N/A |

#### `OE_MAXREADFRAMESIZE`
The maximal size of a frame produced by a call to `oe_read_frame` in bytes.
This number is the size of the frame produced by every device within the device
map that generates read data.

| | |
|---|---|
| option value type | `oe_reg_val_t` |
| option description  | Maximal read frame size in bytes |
| default value | N/A |

#### `OE_WRITEFRAMESIZE`
The maximal size of a frame accepted by a call to `oe_write_frame` in bytes.
This number is the size of the frame provided to `oe_write_frame` to update
all output devices synchronously.

| | |
|---|---|
| option value type | `oe_reg_val_t` |
| option description  | Maximal write frame size in bytes |
| default value | N/A |

#### `OE_RUNNING`
Hardware acquisition run state. Any value greater than 0 indicates that acquisition is
running.

| | |
|---|---|
| option value type | `oe_reg_val_t` |
| option description  | Any value greater than 0 will start acquisition |
| default value | False |

#### `OE_SYSCLKHZ`
System clock frequency in Hz. The PCIe bus is operated at this rate. Read-frame clock values 
are incremented at this rate.

| | |
|---|---|
| option value type | `oe_reg_val_t` |
| option description  | System clock frequency in Hz |
| default value | N/A |

#### `OE_ACQCLKHZ`
Acquisition clock frequency in Hz. Reads from devices are synchronized to this clock. 
Clock values within frame data are incremented at this rate.

| | |
|---|---|
| option value type | `oe_reg_val_t` |
| option description  | Acquisition clock frequency in Hz |
| default value | 42000000 |

## oe_set_opt
Set context options.

``` {.c}
int oe_set_opt(oe_ctx ctx, int option, const void* value, size_t size);
```

### Arguments
- `ctx` context
- `option` option to set
- `value` value to set `option` to
- `size` length of `value` in bytes

### Returns `int`
- 0: success
- Less than 0: `oe_error_t`

### Description
The `oe_set_opt` function sets the option specified by the `option` argument to
the value pointed to by the `value` argument within `ctx`. The `size` indicates
the size of the `value` in bytes.

The following context options can be set:

#### `OE_CONFIGSTREAMPATH`\*
Set path specifying configuration data stream.

| | |
|---|---|
| option value type | `char *` |
| option description  | A character string specifying the configuration stream path |
| default value | /dev/xillybus_oe_config_32, \\\\.\\xillybus_oe_config_32 (Windows) |

#### `OE_READSTREAMPATH`\*
Set path specifying input data stream.

| | |
|---|---|
| option value type | `char *` |
| option description  | A character string specifying the input stream path |
| default value | /dev/xillybus_oe_input_32, \\\\.\\xillybus_oe_input_32 (Windows) |

#### `OE_WRITESTREAMPATH`\*
Set path specifying input data stream.

| | |
|---|---|
| option value type | `char *` |
| option description  | A character string specifying the output stream path |
| default value | /dev/xillybus_oe_output_32, \\\\.\\xillybus_oe_output_32 (Windows) |

#### `OE_SIGNALSTREAMPATH`\*
Set path specifying hardware signal data stream

| | |
|---|---|
| option value type | `char *` |
| option description  | A character string specifying the signal stream path |
| default value | /dev/xillybus_oe_signal_8, \\\\.\\xillybus_oe_signal_8 (Windows) |

#### `OE_RUNNING`\*\*
Set/clear master clock gate. Any value greater than 0 will start acquisition.
Writing 0 to this option will stop acquisition, but will not reset context
options or the sample counter.

| | |
|---|---|
| option value type 	 | `oe_reg_val_t` |
| option description 	 | Any value greater than 0 will start acquisition |
| default value 	 | 0 |

#### `OE_RESET`\*\*
Trigger global hardware reset. Any value great than 0 will trigger a hardware
reset. In this case, acquisition is stopped and all global hardware state (e.g.
sample counters, etc) is defaulted.

| | |
|---|---|
| option value type 	 | `oe_reg_val_t` |
| option description 	 | Any value greater than 0 will trigger a reset |
| default value 	 | Untriggered |

\* Invalid following a successful call to `oe_init_ctx`. Before this, will
return with error code `OE_EINVALSTATE`.

\*\* Invalid until a successful call to `oe_init_ctx`. After this, will
return with error code `OE_EINVALSTATE`.

## oe_read_reg
Read a configuration register on a specific device.

``` {.c}
int oe_read_reg(const oe_ctx ctx, size_t dev_idx, oe_reg_addr_t addr, oe_reg_val_t *value);
```

### Arguments
- `ctx` context
- `dev_idx` physical index number
- `addr` The address of register to write to
- `value` pointer to an int that will store the value of the register at `addr` on `dev_idx`

### Returns `int`
- 0: success
- Less than 0: `oe_error_t`

### Description
`oe_read_reg` is used to read the value of configuration registers from devices
within the current device map. This can be used to verify the success of calls
to `oe_read_reg` or to obtain state information about devices managed by the
current context.

## oe_write_reg
Set a configuration register on a specific device.

``` {.c}
int oe_write_reg(const oe_ctx ctx, size_t dev_idx, oe_reg_addr_t addr, oe_reg_val_t value);
```

### Arguments
- `ctx` context
- `dev_idx` the device index to read from
- `addr` register address within the device specified by `dev_idx` to write
  to
- `value` value with which to set the register at `addr` on the device
  specified by `dev_idx`

### Returns `int`
- 0: success
- Less than 0: `oe_error_t`

### Description
`oe_write_reg` is used to write the value of configuration registers from
devices within the current device map. This can be used to set configuraiton
registers for devices managed by the current context. For example, this is used
to perform configuration of ADCs that exist in a device map. Note that
successful return from this function does not guarantee that the register has
been properly set. Confirmation of the register value can be made using a call
to `oe_read_reg`.

## oe_read_frame
Read high-bandwidth input data stream.

``` {.c}
int oe_read_frame(const oe_ctx ctx, oe_frame_t **frame)
```

### Arguments
- `ctx` context
- `frame` Pointer to a `oe_frame_t` pointer

### Returns `int`
- 0: success
- Less than 0: `oe_error_t`

### Description
`oe_read_frame` allocates host memory and populates it with an `oe_frame_t`
struct corresponding to a single [frame](#frame), with a read header, from the
data input channel. This call will block until either enough data to construct
a frame is available on the data input stream or
[`oe_destroy_ctx`](#oe_destroy_ctx) is called. It is the user's repsonisbility
to free the resources allocated by this call by passing the resulting frame
pointer to [`oe_destroy_frame`](#oe_destroy_frame).

## oe_write_frame
Write a frame to the output data channel.

``` {.c}
int oe_write_frame(const oe_ctx ctx, oe_frame_t *frame)
```

### Arguments
- `ctx` context
- `frame` pointer to an `oe_frame_t`

### Returns `int`
- 0: success
- Less than 0: `oe_error_t`

### Description
`oe_write_frame` writes a pre-allocated and populated `stuct` corresponding to
a single [frame](#frame), with a write header, into the asynchronous data
output channel from host memory. If the frame specifies that devices without
write capabilities should be written to, this function will return
`OE_EWRITEFAILURE`.

## oe_destroy_frame
Free heap-allocated frame.

```{.c}
void oe_destroy_frame(oe_frame_t *frame);
```

### Arguments
- `frame` pointer to an `oe_frame_t`

### Returns `void`
There is no return value.

### Description
`oe_destroy_frame` frees a heap-allocated frame. It is generally used to clean
up the resources allocated by [`oe_read_frame`](#oe_read_frame).

## oe_version
Report the oepcie library version.

``` {.c}
void oe_version(int major, int minor, int patch)
```

### Arguments
- `major` major library version
- `minor` minor library version
- `patch` patch number

### Returns `void`
There is no return value.

### Description
This library uses [semantic versioning](www.semver.org). Briefly, the major
revision is for incompatible API changes. Minor version is for backwards
compatible changes. The patch number is for backwards-compatible bug fixes.

## oe_error_st
Convert an [error number](#oe_error_t) into a human readable string.

``` {.c}
const char *oe_error_str(int err)
```

### arguments
- `err` error code

### returns `const char *`
Pointer to an error message string

## oe_device_str
Convert a [device ID](#oe_device_t) into human readable string. _Note_: This is
an extension function available in oedevices.h.

``` {.c}
const char *oe_device(ind dev_id)
```

### Arguments
- `dev_id` device id

### Returns `const char *`
Pointer to a device id string

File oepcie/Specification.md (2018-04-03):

# `liboepcie` Design Specification

## License
[MIT](https://en.wikipedia.org/wiki/MIT_License)

## Purpose
Configure hardware and read and write streaming data from and to a host
applications.

## Design Requirements
- Low latency (sub millisecond)
- High bandwidth (> 1000 neural data channels)
- Support for different hardware components on a single PCIe bus
    - Support generic mixes of hardware elements
    - Generic configuration channels
    - Generic data input stream
    - Generic data output stream
- Usable by different host applications
- Support multiple PCIe devices on one PC
- Cross platform

## Language
The implementation is in C to facilitate cross platform and cross-language use.

## Scope and External Dependencies
- This is a low level library used by high-level language binding and/or
  application plugin developers. It is not meant to be used by neuroscientists
  directly.

- The only external dependency aside from the c standard library is
  [Xillybus](http://xillybus.com/), which will be used for PCIe communication.
  Because xillybus provides abstracts this functionality to the level of file
  IO, a drop in replacement without its commercial restrictions is possible if
  open-ephys ever gathers the funds to do so.

- The public programming interface, supported device ID enumeration, and public
  type declarations should be limited to a single header file.

## Types and Definitions

### Context
A _context_ (`oe_ctx`) holds all required state for a devices associated with
one PCIe bus in the following hierarchy:

``` {.c}
typedef struct stream_fid {
    char *path;
    int fid;
} stream_fid_t;

typedef struct oe_ctx_impl {
    // Communication channels
    stream_fid_t config;
    stream_fid_t data;
    stream_fid_t signal;

    // Devices
    oe_size_t num_dev;
    oe_device_t* dev_map;

    // Frame sizes (bytes)
    oe_size_t max_read_frame_size;
    oe_size_t write_frame_size;

    // Acqusition state
    enum run_state {
        CTXNULL = 0,
        UNINITIALIZED,
        IDLE,
        RUNNING
    } run_state;

} oe_ctx_impl_t;
```

State details is hidden in implementation file (.c). A pointer to opaque
type (handle) is exposed publicly in header (.h):

```
// .h
typedef struct oe_ctx_impl *oe_ctx;
```

API calls will typically take a context handle as the first argument and use it
to reference required state information to enable communication and/or to
mutate the context to reflect some function side effect (e.g. add device map
information):

```
int oe_api_function(oe_ctx ctx, ...);
```

### Device
A _device_ (`oe_device_t`) is defined as configurable piece of hardware with
its own register address space (e.g. an integrated circuit) or something
programmed within the firmware to emulate this (e.g. a MUX or microcontroller
implemented within an FPGA). Host interaction with a device is facilitated
using a description, which is provided by a `struct` as follows:

``` {.c}
typedef struct oe_device {
    device_id_t id;
    oe_size_t   read_size;
    oe_size_t   num_reads;
    oe_size_t   write_size;
    oe_size_t   num_writes;   // Number of frames that must be written to construct a full output sample
} oe_device_t;
```

The definition of each member of the `oe_device_t` structure is provided below:

1. `enum config_device_id`: Device identification number which is globally
   enumerated for the entire project
    - e.g. Immediate IO (`OE_IMMEDIATEIO`) from the host board is 0
    - e.g. Intan RHD2032 (`OE_RHD2132`) is 1, Intan RHD2064 (`OE_RHUD21641`) is
      2, etc.
    - This enumeration grows with the number of devices supported by the
      library. There is a single `enum` for the entire library which
      enumerates all possible devices that are controlled across `context`
      configurations.
    - A `context` is only responsible for controlling a subset of all
      supported devices. This subset is referred to a _device map_.

    ```
    typedef enum device_id {
        OE_IMMEDIATEIO = 0,
        OE_RHD2132,
        OE_RHD2164,
        OE_MPU9250,
        ...
    } oe_device_id_t
    ```

2. `oe_size_t read_size`: bytes of each transmitted data frame from this device.
    - 0 indicates that it does not send data.

3. `oe_size_t num_reads`: Number of frames that must be read to construct a full sample (e.g., for row reads from camera.

4. `oe_size_t write_size`: bytes within the output frame transmitted data packet to this device.
    - 0 indicates that it does not send data.

5. `oe_size_t num_writes`: number of frames that must be written to construct a full output sample.

Following a hardware reset, which is triggered either by a call to
`oe_init_ctx` or to `oe_set_ctx` using the `` option, the device map is pushed
onto the signal stream by the FPGA as
[COBS](https://en.wikipedia.org/wiki/Consistent_Overhead_Byte_Stuffing) encoded
packets. On the signal stream, the device map is organized as follows,

... | DEVICEMAPACK, uint32_t num_devices | DEVICEINST oe_device_t dev_0
    | DEVICEINST oe_device_t dev_1 | ... | DEVICEINST oe_device_t dev_n | ...

where | represents '0' packet delimiters. During a call to `oe_init_ctx`, the
device map is decoded from the signal stream. It can then be examined using
calls to `oe_get_opt` using the `OE_DEVICEMAP` option.

### Frame
A _frame_ is a flat byte array containing a single sample's worth of data for a
set (one to all) of devices within a device map. _Read-frames_ are produced by
calls `oe_read_frame` and _write_frames_ are provided to calls to
`oe_write_frame`. Data within both read- and write-frames is arranged into four
sections as follows:

```
[32 byte header,                              // 1. header
 dev_0 idx, dev_1 idx, ... , dev_n idx,       // 2. device map indicies
 dev_0 data, dev_1 data, ... , dev_n data,    // 3. data
 padding ]                                    // 4. padding

```

Each frame section is described below:

1. header
    - Each frame starts with a 32-byte header
    - For read-frames (`oe_read_frame`) header contains
        - bytes 0-7: `uint64_t` system clock counter
        - bytes 8-9: `uin16_t` indicating number of devices that the frame contains
          data for
        - byte 10: `int8_t` frame error. 0 = OK. 1 = data may be corrupt.
        - bytes 11-32: reserved

    - For write-frames (`oe_write_frame`) header contains
        - bytes 0-32: reserved

2. device map indices
    - An array of `uint32_t` indicies into the device map captured by the host
      during a call to `oe_init_ctx`.
    - The offset, size, and type information of the _i_th data block within the
      `data` section of each frame is determined by examining the _i_th member
      of the device map.

3. data
    - Raw data blocks from each device in the device map.
    - The ordering of device-specific blocks is the same as the device index
      within the `device map index` portion of the frame
    - The read/write size for each device-specific block is provided in the
      device map
    - Data block type information is provided in device specific manual file,
      in this repository (TODO)
    - Perhaps in the future, data type casting information can be provided in
      the device map, but this is not currently implemented

3. padding
    - The read and write frame may require padding 0's at the end of the frame
      in order to make the frame size a multiple of 32-bits, which is the width
      of the FIFO that is used. This allows frames to fall on the FIFO's
      natural data boundaries for effecient reading and writing.

### FPGA/Host Communication
FPGA/host communication occurs over four distinct channels. Each channel's
device file descriptors are handled automatically a context. Direct
communication over these channels is implicit to API calls and is not directly
managed by the programmer. The library interacts with each channels using
standard UNIX-like file system calls (`open`, `close`, `read`, `write`, etc.).
Their semantics and behavior are identical to either normal files
(configuration channel) or named pipes (signal, data input, and data ouput
channels).

#### Signal channel (8-bit, asynchronous, read only)
The _signal_ channel provides a way for the firmware to inform host of
configuration results. Additionally, it allows the host to read the device map
supported by the FPGA firmware. The behavior of the signal channel is
equivalent to a read-only, blocking UNIX named pipe. Signal data is framed into
packets using Consistent Overhead Byte Stuffing
([COBS](https://en.wikipedia.org/wiki/Consistent_Overhead_Byte_Stuffing)).
Within this scheme, packets are delimited using 0's and always have the
following format:

```
[PACKET-FLAG, data...]
```

where PACKET-FLAG is 32-bit unsigned integer with a single unique bit settting.
Valid PACKET-FLAGS are:

``` {.c}
typedef enum oe_signal {
    NULLSIG             = (1u << 0),
    CONFIGWACK          = (1u << 1), // Configuration write-acknowledgement
    CONFIGWNACK         = (1u << 2), // Configuration no-write-acknowledgement
    CONFIGRACK          = (1u << 3), // Configuration read-acknowledgement
    CONFIGRNACK         = (1u << 4), // Configuration no-read-acknowledgement
    DEVICEMAPACK        = (1u << 5), // Device map start acnknowledgement
    DEVICEINST          = (1u << 6), // Device map instance
} oe_signal_t;
```

Following a hardware reset, the signal channel is used to provide the device
map and frame information to the host using the following packet sequence:

```
... | DEVICEMAPACK, uint32_t num_devices | DEVICEINST oe_device_t dev_0
    | DEVICEINST oe_device_t dev_1 | ... | DEVICEINST oe_device_t dev_n| ...
```

Following a device register read or write, ACK or NACK signals are pushed onto
the signal stream by the firmware. e.g. on a successful register read:

```
... | CONFIGRACK, uint32_t register value | ...
```

#### Configuration channel (32-bit, synchronous, read and write)
The _configuration_ channel supports seeking to, reading, and writing a set of
configuration registers. Its behavior is equivalent to that of a normal UNIX
file. There are two types of registers handled by the configuration channel:
the first set of registers encapsulates a generic device programming interface.
The remaining registers are for global context control and configuration and
provide access to acquisition parameters and state control.

1. Device register programming interface:

- `uint32_t config_device_id`: Device ID register. Specify a device endpoint as
  enumerated by the firmware (e.g. an Intan chip, or a IMU chip)  and to which
  communication will be directed using `config_reg_addr` and
  `config_reg_value`.

- `uint32_t config_reg_addr`: register address of configuration to be written

- `uint32_t config_reg_value`: configuration value to be written to or read
  from and that corresponds to `config_reg_addr` on device `config_device_id`

- `uint32_t config_rw`: bit indicating if a read or write should be performed.
  0 indicates read operation. >0 indicates write operation.

- `uint32_t config_trig`: set >0 to trigger either register read or write
  operation depending on the state of `config_rw`. If `config_rw` is 0, a read
  is performed. In this case `config_reg_value` is updated with value stored at
  `config_reg_addr` on device at `config_device_id`. If the specified register
  is not readable, `config_reg_value` is populated with a magic number
  (`OE_REGMAGIC`).  If `config_rw`is 1, `config_reg_value` is written to
  register at `config_reg_addr` on device `config_device_id`. The `config_trig`
  register is always be set low by the firmware following transmission even
  if it is not successful or does not make sense given the address register
  values.

2. Global acqusition registers

- `uint32_t running`: set to > 0 to run the system clock and produce data. Set
  to 0 to stop the system clock and therefore stop data flow. Results in no
  other configuration changes.

- `uint32_t reset`: set to > 0 to trigger a hardware reset and send a fresh
  device map to the host and reset hardware to its default state. Set to 0 by
  host firmware upon entering the reset state.

- `uint32_t sys_clock_hz`: A read-only register specifying the base hardware
  clock frequency in Hz.

- _Note:_ Appropriate values of `config_reg_addr` and `config_reg_value` are
  determined by:
    - Looking at a device's data sheet if the device is an integrated circuit
    - Looking at the verilog source code comments if the device exists as a
      module that is implemented within the FPGA (e.g a MUX) or as a verilog
      module that abstracts a PCB or sub-circuit (e.g. a digital IO port).

- _Note:_ `SEEK` locations of each configuration register, relative to the
  start of the stream, are provided by the `oe_config_reg` enum.

- _Note:_ Upon a call to `oe_write_reg`, the following actions take place:

    1. The value of `config_trig` is checked.
        - If it is 0x00, the function call proceeds.
        - Else, the function call returns with OE_ERETRIG.
    1. `dev_idx` is copied to the `config_device_id` register on the host FPGA.
    1. `addr` is copied to the `config_reg_addr` register on the host FPGA.
    1. `value` is copied to the `config_reg_value` register on the host FPGA.
    1. The `config_rw` register on the host FPGA is set to 0x01.
    1. The `config_trig` register on the host FPGA is set to 0x01, triggering
    configuration transmission by the firmware.
    1. (Firmware) A configuration write is performed by the firmware.
    1. (Firmware) `config_trig` is set to 0x00 by the firmware.
    1. (Firmware) `OE_CONFIGWACK` is pushed onto the signal stream by the
    firmware.
    1. The signal stream is pumped until `OE_CONFIGWACK` is received indicating
    that the host FPGA has attempted to write to the specified device register.

- _Note:_ Upon a call to `oe_write_reg`, the following actions take place:

    1. The value of `config_trig` is checked.
        - If it is 0x00, the function call proceeds.
        - Else, the function call returns with OE_ERETRIG.
    1. `dev_idx` is copied to the `config_device_id` register on the host FPGA.
    1. `addr` is copied to the `config_reg_addr` register on the host FPGA.
    1. The `config_rw` register on the host FPGA is set to 0x00.
    1. The `config_read_trig` register on the host FPGA is set to 0x01,
    triggering configuration transmission by the firmware.
    1. (Firmware) A configuration read is performed by the firmware.
    1. (Firmware) `config_trig` is set to 0x00 by the firmware.
    1. (Firmware) `OE_CONFIGRACK` is pushed onto the signal stream by the
    firmware.
    1. The signal stream is pumped until `OE_CONFIGRACK` is received indicating
    that the host FPGA has completed reading the specified device register and
    copied its value to the `config_reg_value` register.

- _Note:_ Following successful or unsuccessful device register read or write,
  the COBS encoded ACK or NACK packets must be passed to the signal stream.

#### Data input channel (32-bit, asynchronous, read-only)
The _data input_ channel provides high bandwidth communication from the FPGA
firmware to the host computer using direct memory access (DMA) via calls to
`oe_read_frame`. From the host's perspective, its behavior is equivalent to a
read-only, blocking UNIX named pipe with the exception that data can only be
read on 32-bit, instead of 8-bit, boundaries.  Read-frames are pushed into the
data input channel at a rate dicated by the FPGA firmware. It is incumbent on
the host to call `oe_read_frame` fast enought to prevent buffer overflow. At
the time of this writing, the data input buffer occupies a 512 MB segment of
kernal RAM. Increased bandwidth demands will nessestate the creation of a
user-space buffer. This change will have no effect on the API.

#### Data output channel (32-bit, asynchronous, write-only)
The _data output_ channel provides high bandwidth communication from the host
computer to the FPGA firmware using DMA via calls to `oe_write_frame`. From
the host's perspective, its behavior is equivalent to a write-only, blocking
UNIX named pipe with the exception that data can only be read on 32-bit,
instead of 8-bit, boundaries. Its performance characteristics are largely
identical to the data input channel.

# `liboepcie` API Specification

## Types

### Integer types
- `oe_size_t`: Fixed width size integer type.
- `oe_dev_id_t`: Fixed width device identity integer type.
- `oe_reg_addr_t`: Fixed width device register address integer type.
- `oe_reg_value_t`: Fixed width device register value integer type.

### `oe_ctx`
Opaque handle to a structure which contains hardware and device state
information. There is generally one context per process using the library.

### `oe_opt_t`
Context option enumeration. See `oe_set_opt` and `oe_get_opt` for valid values.

### `oe_device_id_t`
Device identity enumeration. Provides agreed-upon, liboepcie-specific IDs for
all devices supported by the firmware.

``` {.c}
typedef enum oe_device_id {
    OE_IMMEDIATEIO = 0,
    OE_RHD2032,
    OE_RHD2064,
    OE_MPU9250,
} oe_device_id_t;
```

### `oe_device_t`
`oe_device_t` describes one of potentially many pieces of hardware within a
context. Examples include Intan chips, IMU, stimulators, immediate IO circuit,
auxiliary ADC, etc. Each valid device type has a unqique ID which is enumerated
in `oe_device_id_t`. A map of available devices is stored in the current
context via `oe_init_ctx`.  This map can be examined via calls to `oe_get_opt`.

``` {.c}
typedef struct oe_device {
    oe_dev_id_t id;
    oe_size_t read_offset;
    oe_size_t read_size;
    oe_size_t write_offset;
    oe_size_t write_size;
} oe_device_t;
```

### `oe_error_t`
Error code enumeration.

``` {.c}
typedef enum oe_error {
    OE_ESUCCESS         =  0,  // Success
    OE_EPATHINVALID     = -1,  // Invalid stream path, fail on open
    OE_EREINITCTX       = -2,  // Double initialization attempt
    OE_EDEVID           = -3,  // Invalid device ID on init or reg op
    OE_EREADFAILURE     = -4,  // Failure to read from a stream/register
    OE_EWRITEFAILURE    = -5,  // Failure to write to a stream/register
    OE_ENULLCTX         = -6,  // Attempt to call function w null ctx
    OE_ESEEKFAILURE     = -7,  // Failure to seek on stream
    OE_EINVALSTATE      = -8,  // Invalid operation for the current context run state
    OE_EDEVIDX          = -9,  // Invalid device index
    OE_EINVALOPT        = -10, // Invalid context option
    OE_EINVALARG        = -11, // Invalid function arguments
    OE_ECANTSETOPT      = -12, // Option cannot be set in current context state
    OE_ECOBSPACK        = -13, // Invalid COBS packet
    OE_ERETRIG          = -14, // Attempt to trigger an already triggered operation
    OE_EBUFFERSIZE      = -15, // Supplied buffer is too small
    OE_EBADDEVMAP       = -16, // Badly formated device map supplied by firmware
    OE_EBADALLOC        = -17, // Bad dynamic memory allocation
    OE_ECLOSEFAIL       = -18, // File descriptor close failure, check errno
    OE_EDATATYPE        = -19, // Invalid underlying data types
    OE_EREADONLY        = -20, // Attempted write to read only object (register, context option, etc)
    OE_ERUNSTATESYNC    = -21, // Software and hardware run state out of sync
} oe_error_t;
```

## oe_create_ctx
Create a hardware context. A context is an opaque handle to a structure which
contains hardware and device state information, configuration capabilities, and
data format information. It can be modified via calls to `oe_set_opt`. Its
state can be examined by `oe_get_opt`.

``` {.c}
oe_ctx oe_create_ctx();
```

### Returns `oe_ctx`
An opaque handle to the newly created context if successful. Otherwise it shall
return NULL and set errno to `EAGAIN`.

### Description
On success a context struct is allocated and created, and its handle is passed
to the user. The context holds all state used by the library function calls for
refection and hardware communication. It holds paths to FIFOs and configuration
communication channels and knowledge of the hardware's parameters and run state
. It is configured through calls to `oe_set_opt`. It can be examined through
calls to `oe_get_opt`.

## oe_destroy_ctx
Terminate a context and free bound resources.

``` {.c}
int oe_destroy_ctx(oe_ctx ctx)
```

### Arguments
- `ctx` context

### Returns `int`
- 0: success
- Less than 0: `oe_error_t`

### Description
During context destruction, all resources allocated by `oe_create_ctx` are
freed. This function can be called from any context run state. When called, an
interrupt signal (TOD0: Which?) is raised and any blocking operations will
return immediately. Attached resources (e.g. file descriptors and allocated
memory) are closed and their resources freed.

## oe_init_ctx
Initialize a context, opening all file streams etc.

``` {.c}
int oe_init_ctx(oe_ctx ctx)
```

### Arguments
- `ctx` context

### Returns `int`
- 0: success
- Less than 0: `oe_error_t`

### Description
Upon a call to `oe_init_ctx`, the following actions take place

1. All required data streams are opened.
2. A device map is read from the firmware. It can be examined via calls t
   `oe_get_opt`.
3. The data transmission packet size is calculated and stored. It can be
   examined via calls t `oe_get_opt`.

Following a successful call to `oe_init_ctx`, the hardware's acqusition
parameters and run state can be manipulated using calls to `oe_get_opt`.

## oe_get_opt
Get context options. NB: This follows the pattern of
[zmq_getsockopt()](http://api.zeromq.org/4-1:zmq-getsockopt).

``` {.c}
int oe_get_opt(const oe_ctx ctx, int option, void* value, size_t *size);
```

### Arguments
- `ctx` context to read from
- `option` option to read
- `value` buffer to store value of `option`
- `size` pointer to the size of `value` (including terminating null character,
  if applicable) in bytes

### Returns `int`
- 0: success
- Less than 0: `oe_error_t`

### Description
The `oe_get_opt`() function shall set the option specified by the `option`
argument to the value pointed to by the `value` argument for the context
pointed to by the `ctx` argument. The `size` provides a pointer to the size of
the option value in bytes. Upon successful completion `oe_get_opt` shall modify
the value pointed to by `size` to indicate the actual size of the option value
stored in the buffer.

Following a succesful call to `oe_init_ctx`, the following socket options can be read:

#### `OE_CONFIGSTREAMPATH`
URI specifying config data stream.

| | | |
|-|-|-|
| option value type | char * |
| option value unit | N/A |
| default value | file:///dev/xillybus_oe_config_32 |

#### `OE_READSTREAMPATH`
URI specifying input data stream.

| | | |
|-|-|-|
| option value type | char * |
| option value unit | N/A |
| default value | file:///dev/xillybus_oe_input_32 |

#### `OE_SIGNALSTREAMPATH`
URI specifying hardware signal data stream

| | | |
|-|-|-|
| option value type 	 | char * |
| option value unit 	 | N/A |
| default value 	 | file:///dev/xillybus_oe_signal_32 |

#### `OE_DEVICEMAP`
Obtain the device map

| | | |
|-|-|-|
| option value type 	 | oe_device_t * |
| option value unit 	 | Pointer to a pre-allocated array of `oe_device_t` structs |
| default value 	 | N/A |

#### `OE_NUMDEVICES`
Number of devices in the device map

| | | |
|-|-|-|
| option value type 	 | oe_reg_val_t |
| option value unit 	 | N/A |
| default value 	 | N/A |

#### `OE_READFRAMESIZE`
Size of a read frame (sample) in bytes

| | | |
|-|-|-|
| option value type 	 | oe_reg_val_t |
| option value unit 	 | N/A |
| default value 	 | N/A |

#### `OE_WRITEFRAMESIZE`
Size of a write frame (sample) in bytes

| | | |
|-|-|-|
| option value type 	 | oe_reg_val_t |
| option value unit 	 | N/A |
| default value 	 | N/A |

#### `OE_RUNNING`
Hardware run state

| | | |
|-|-|-|
| option value type 	 | oe_reg_val_t |
| option value unit 	 | True or False (i.e. 0 or > 0) |
| default value 	 | False |

#### `OE_SYSCLKHZ`
System clock frequency

| | | |
|-|-|-|
| option value type 	 | oe_reg_val_t |
| option value unit 	 | Hz |
| default value 	 | 100e6 |

#### `OE_FSCLKHZ`
Sample clock frequency

| | | |
|-|-|-|
| option value type 	 | oe_reg_val_t |
| option value unit 	 | Hz |
| default value 	 | 30e3 |

#### `OE_FSCLKM`
Sample clock frequency multiplier

| | | |
|-|-|-|
| option value type 	 | oe_reg_val_t |
| option value unit 	 | N/A |
| default value 	 | 3 |

#### `OE_FSCLKD`
Sample clock frequency divider

| | | |
|-|-|-|
| option value type 	 | oe_reg_val_t |
| option value unit 	 | N/A |
| default value 	 | 10000 |

## oe_set_opt
Set context options. NB: This follows the pattern of
[zmq_setsockopt()](http://api.zeromq.org/4-1:zmq-setsockopt).

``` {.c}
int oe_set_opt(oe_ctx ctx, const oe_opt_t option, const void* value, size_t size);
```
### Arguments
- `ctx` context
- `option` option to set
- `value` value to set `option` to
- `size` length of `value` in bytes

### Returns `int`
- 0: success
- Less than 0: `oe_error_t`

### Description
The `oe_set_opt` function shall set the option specified by the `option`
argument to the value pointed to by the `value` argument within `ctx`. The
`size` indicates the size of the `value` in bytes.

The following socket options can be set:

#### `OE_CONFIGSTREAMPATH`\*
Set URI specifying config data stream.

| | | |
|-|-|-|
| option value type | char * |
| option value unit | N/A |
| default value | file:///dev/xillybus_oe_config_32 |

#### `OE_READSTREAMPATH`\*
Set URI specifying input data stream.

| | | |
|-|-|-|
| option value type | char * |
| option value unit | N/A |
| default value | file:///dev/xillybus_oe_input_32 |

#### `OE_SIGNALSTREAMPATH`\*
Set URI specifying hardware signal data stream

| | | |
|-|-|-|
| option value type 	 | char * |
| option value unit 	 | N/A |
| default value 	 | file:///dev/xillybus_oe_signal_32 |

#### `OE_RUNNING`\*\*
Set/clear master clock gate. Any value greater than 0 will start acqusition.
Writing 0 to this option will stop acqusition, but will not reset context
options or the sample counter.

| | | |
|-|-|-|
| option value type 	 | oe_reg_val_t |
| option value unit 	 | True or false (i.e. 0 or not 0) |
| default value 	 | False |

#### `OE_RESET`\*\*
Trigger global hardware reset. Any value great than 0 will trigger a hardware
reset. In this case, acquisition is stopped and all global hardware parameters
(clock multipliers, sample counters, etc) are defaulted.

| | | |
|-|-|-|
| option value type 	 | oe_reg_val_t |
| option value unit 	 | Trigger (i.e. any value greater than 0) |
| default value 	 | Untriggered |

#### `OE_FSCLM`\*\*
Set sample clock multiplier. Used to derive the sample clock frequency from the
system clock. The sample clock frequency = M * system clock frequency / D.

| | | |
|-|-|-|
| option value type 	 | oe_reg_val_t |
| option value unit 	 | Sample clock ratio numerator |
| default value 	 | 3 |

#### `OE_FSCLD`\*\*
Set sample clock divider. Used to derive the sample clock frequency from the
system clock. The sample clock frequency = M * system clock frequency / D.

| | | |
|-|-|-|
| option value type 	 | oe_reg_val_t |
| option value unit 	 | Sample clock ratio denominator |
| default value 	 | 10000 |

\* Invalid following a successful call to `oe_init_ctx()`. In this case, will
return with error code `OE_EINVALSTATE`.

\*\* Invalid until a succesful call to `oe_init_ctx()`. In this case, will
return with error code `OE_EINVALSTATE`.

## oe_read_reg
Read a configuration register on a specific device.

``` {.c}
int oe_read_reg(const oe_ctx ctx, const oe_dev_idx_t dev_idx, const oe_reg_addr_t addr, oe_reg_val_t *value)
```

### Arguments
- `ctx` context
- `dev_idx` physical index number
- `addr` The address of register to write to
- `value` pointer to an int that will store the value of the register at `addr` on `dev_idx`

### Returns `int`
- 0: success
- Less than 0: `oe_error_t`

### Description
`oe_read_reg` is used to read the value of configuration registers from devices
within the current device map. This can be used to verify the success of calls
to `oe_read_reg` or to obtain state information about devices managed by the
current context.

## oe_write_reg
Set a configuration register on a specific device.

``` {.c}
int oe_write_reg(const oe_ctx ctx, const oe_dev_idx_t dev_idx, const oe_reg_addr_t addr, const oe_reg_val_t value)
```

### Arguments
- `ctx` context
- `dev_idx` the device index to read from
- `addr` register address within the device specified by `dev_idx` to write
  to
- `value` value with which to set the register at `addr` on the device
  specified by `dev_idx`

### Returns `int`
- 0: success
- Less than 0: `oe_error_t`

### Description
`oe_write_reg` is used to write the value of configuration registers from
devices within the current device map. This can be used to set configuraiton
registers for devices managed by the current context. For example, this is used
to perform configuration of ADCs that exist in a device map. Note that
successful return from this function does not guarantee that the register has
been properly set. Confirmation of the register value can be made using a call
to `oe_read_reg`.

## oe_read
Read high-bandwidth input data stream.

``` {.c}
int oe_read_frame(const oe_ctx ctx, oe_frame_t **frame)
```

### Arguments
- `ctx` context
- `frame` Pointer to a `oe_rframe_t` pointer

### Returns `int`
- 0: success
- Less than 0: `oe_error_t`

### Description
`oe_read_frame` allocates and populates a `struct` corresponding to a single
[read-frame](#frame) from the data input channel into host memory.

``` {.c}
// Read frame type
typedef struct oe_rframe {
    uint64_t sample_no;   // Sample no.
    uint16_t num_dev;     // Number of devices in frame
    uint8_t corrupt;      // Is this frame corrupt?
    oe_size_t *dev_idxs;  // Array of device indicies in frame
    size_t *dev_offs;     // Device data offsets within data block
    uint8_t *data;        // Multi-device raw data block

} oe_rframe_t;
```

## oe_write_frame
NB: Not implemented in first version
Write a frame to the output data channel.

``` {.c}
int oe_write_frame(const oe_ctx ctx, oe_frame_t *frame)
```

### Arguments
- `ctx` context
- `frame` an [output frame]()

### Returns `int`
- 0: success
- Less than 0: `oe_error_t`

### Description
`oe_write_frame` writes a pre-allocated and populated `stuct` corresponding to
a single [write-frame](#frame) into the asynchronous data output channel from
host memory.

## oe_version
Report the oepcie library version.

``` {.c}
void oe_version(int major, int minor, int patch)
```

### Arguments
- `major` major library version
- `minor` minor library version
- `patch` patch number

### Returns `void`
There is no return value.

### Description
This library uses [semantic versioning](www.semver.org). Briefly, the major
revision is for incompatible API changes. Minor version is for backwards
compatible changes. The patch number is for backwards-compatible bug fixes.

## oe_error_str
convert an error number from `oe_error_t` into a human readable string.

``` {.c}
const char *oe_error_str(oe_error_t err)
```

### arguments
- `err` error code

### returns `const char *`
Pointer to an error message string

## oe_device_str
Convert an number from `oe_device_id_t` into human readable string.

``` {.c}
const char *oe_device(oe_device_id_t dev_id)
```

### Arguments
- `dev_id` device id

### Returns `const char *`
Pointer to a device id string

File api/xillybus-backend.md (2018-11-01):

# `liboepcie` Xillybus Backend Guide

`liboepcie` is agnostic to implementation of the "communication backend" so
long it fulfils the interface requirements detailed in the [oepcie
specification](../spec/spec.pdf). This is because, ultimately, all
communication is handled using low-level system IO system calls (`read`,
`write`, `lseek`, etc.) that operate on file descriptors. For instance, both
the `signal` and the `read` communication channels can be implemented using
UNIX named pipes and the configuration channel can be implemented using a
normal file.  In fact, this is exactly how `liboepcie` is
[tested](../api/liboepcie)

[Xillybus](http://xillybus.com/) is a company that provides closed-source (but
monetarily-free for academic use) FPGA IP cores as well as free and open-source
device drivers that abstract PCIe communication to the level of system IO
calls. For this reason, Xillybus IP Cores and drivers can be used as a high
performance PCIe-based backend by `liboepcie`. A custom, completely open-source
solution is in the works, but it is currently not available. The following
steps show how to generate IP cores and obtain device drivers in order to use a
Xillybus PCIe backend with `liboepcie`.  Windows and Linux hosts are supported.

## Generating HDL IP Cores
1. Make a [Xillybus account](http://xillybus.com/ipfactory/signup)
1. Visit the [Xillybus IP Core Factory](http://xillybus.com/ipfactory/)
1. Fill out the following information in the IP Core Factory form
    - IP Core's Name: oepcie
    - Target device family: Xilinx Kintex 7
    - Intial template: Empty
    - Operating system: Windows and Linux OR Linux OR Windows depending on your requirements

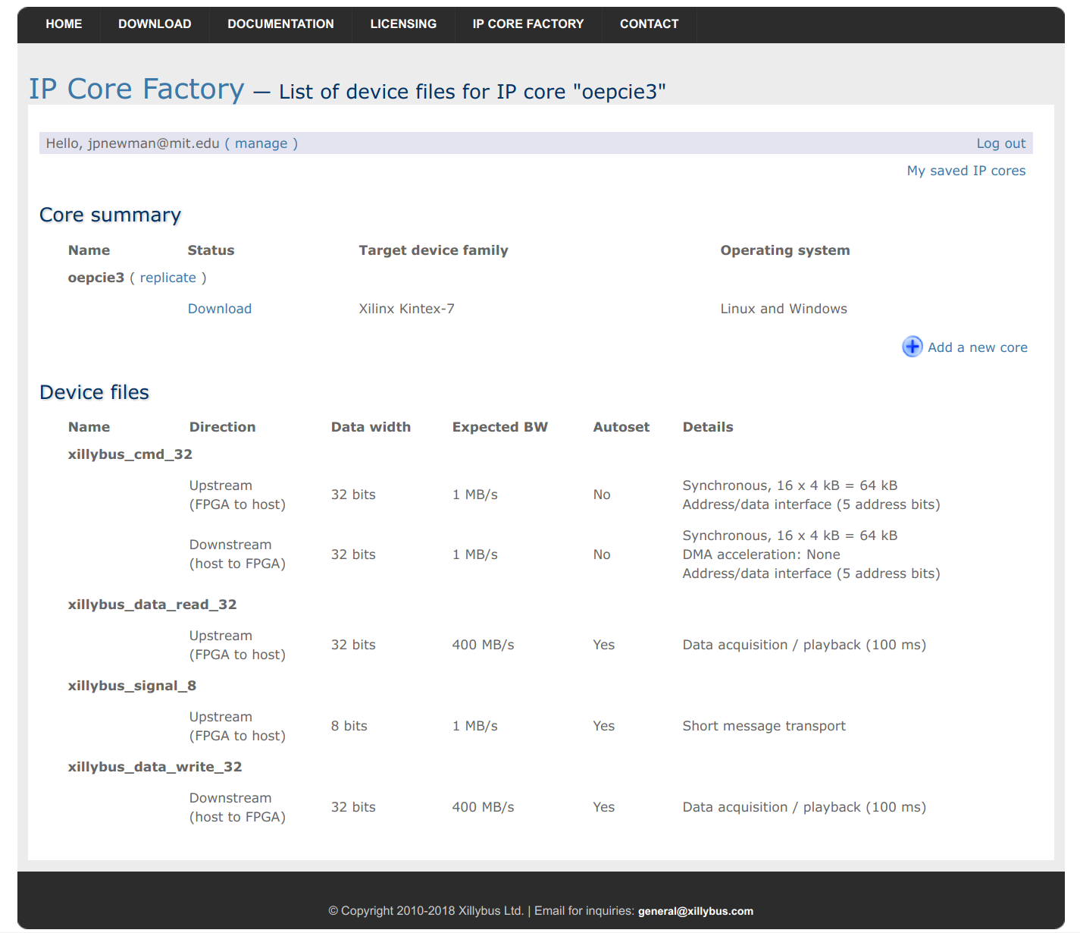
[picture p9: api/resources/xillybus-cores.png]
xillybus_cmd_32 options
	 

1. After the core has been generated, create 3 device files for the core with
   the following settings
    - `xillybus_cmd_32`

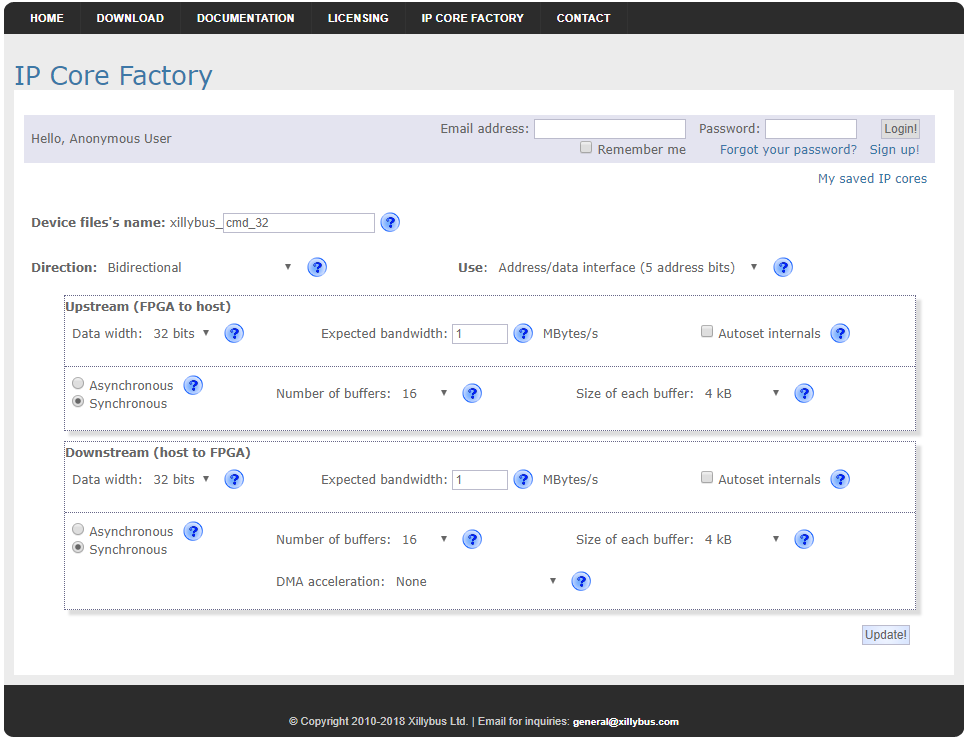
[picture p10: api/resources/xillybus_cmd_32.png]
xillybus_cmd_32 options
    

    - `xillybus_signal_8`

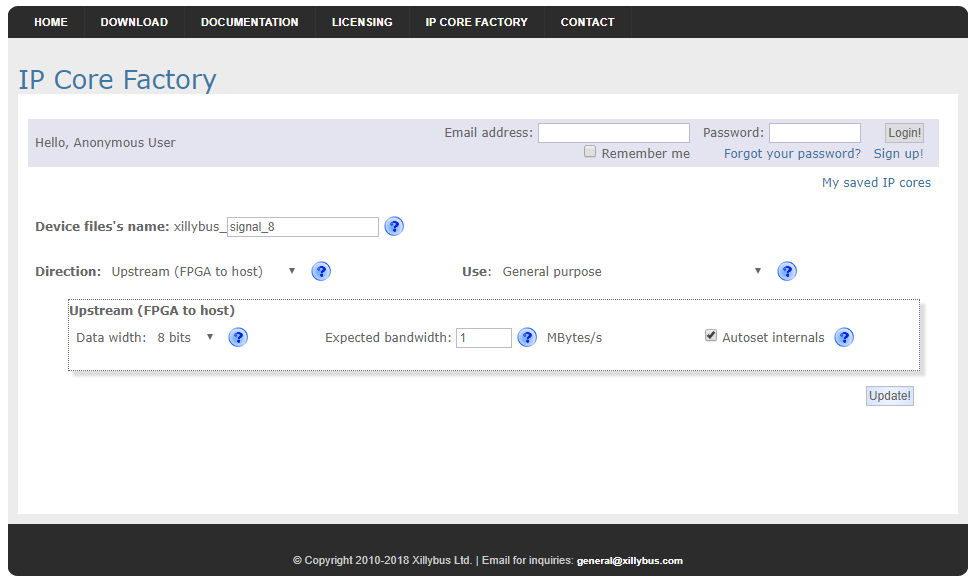
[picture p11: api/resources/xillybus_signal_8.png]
xillybus_signal_8 options
    

    - `xillybus_data_read_32`

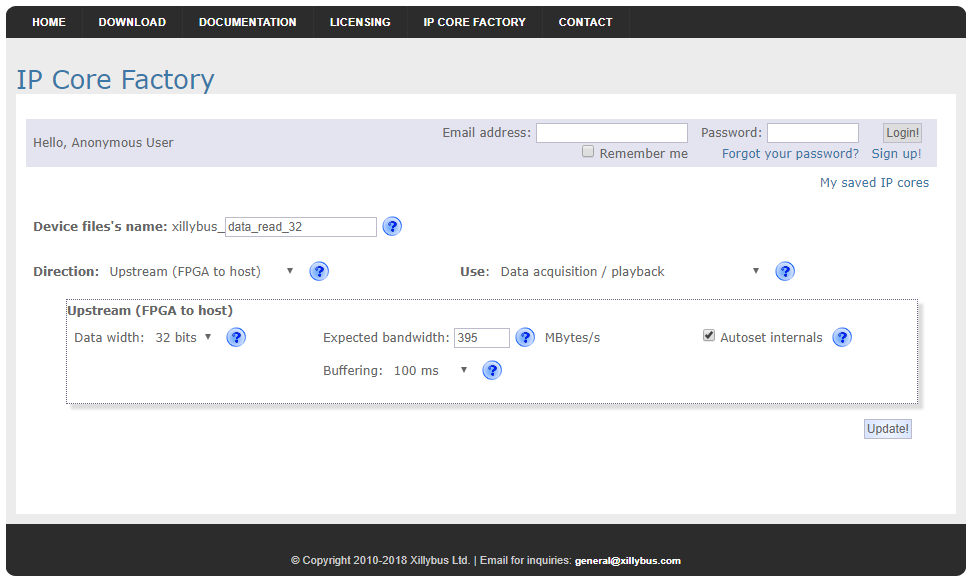
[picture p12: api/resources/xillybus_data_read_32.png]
xillybus_data_read_32 options
    

    - `xillybus_data_write_32`

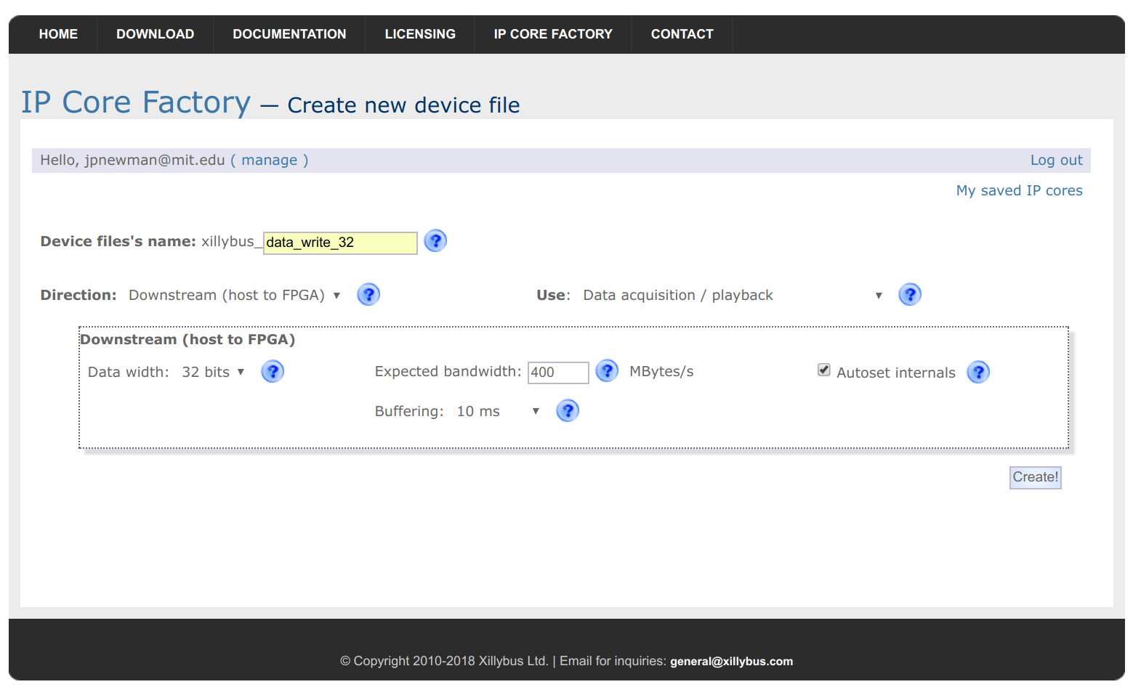
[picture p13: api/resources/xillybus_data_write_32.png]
xillybus_data_write_32 options
    
1. Generate the core for use in your host firmware.

## Obtaining Host Device Driver
### Linux
If you are using fairly recent Linux kernel, the driver is included
automatically. Otherwise, have a look at [Getting started with Xillybus on a
Linux
host](http://xillybus.com/downloads/doc/xillybus_getting_started_linux.pdf) for
manual installation instructions. The driver can be downloaded
[here](http://xillybus.com/downloads/xillybus.tar.gz).

### Windows
The Xillybus device driver will need to be manually associated with the PCIe
device. Installation instructions can be found in the [Getting started with
Xillybus on a Windows
host](http://xillybus.com/downloads/doc/xillybus_getting_started_windows.pdf).
The driver can downloaded
[here](http://xillybus.com/downloads/xillybus-windriver-1.2.0.0.zip).

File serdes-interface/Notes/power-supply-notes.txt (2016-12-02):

Max current draw of each intan chip is 16 mA. There are a max of 4 chips. So with a 2X safety factor to deal with other components:

2 * (4 * 16) =~ 130 mA

If we are dropping from a 12V supply, the dropout voltage will be

12V - 3.5V = 8.5V

So, thermal power dissipation is

P_therm = 8.5V * 0.13A = 1.1 W.

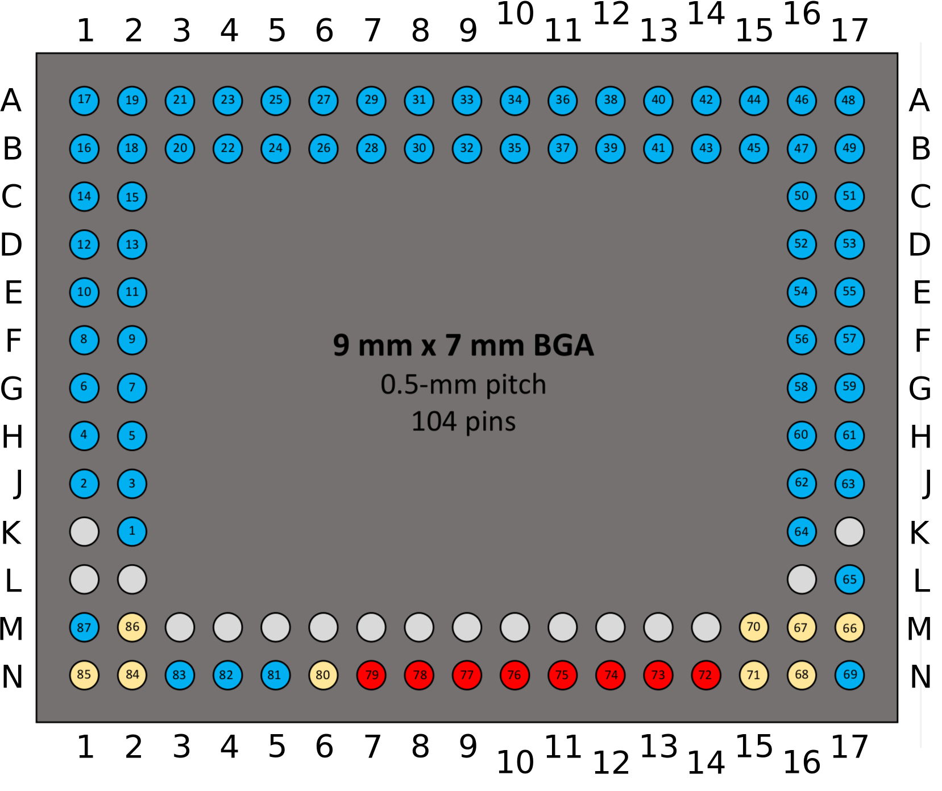
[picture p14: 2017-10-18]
headstage-64/datasheets/rhd2164_bga-pinout.png

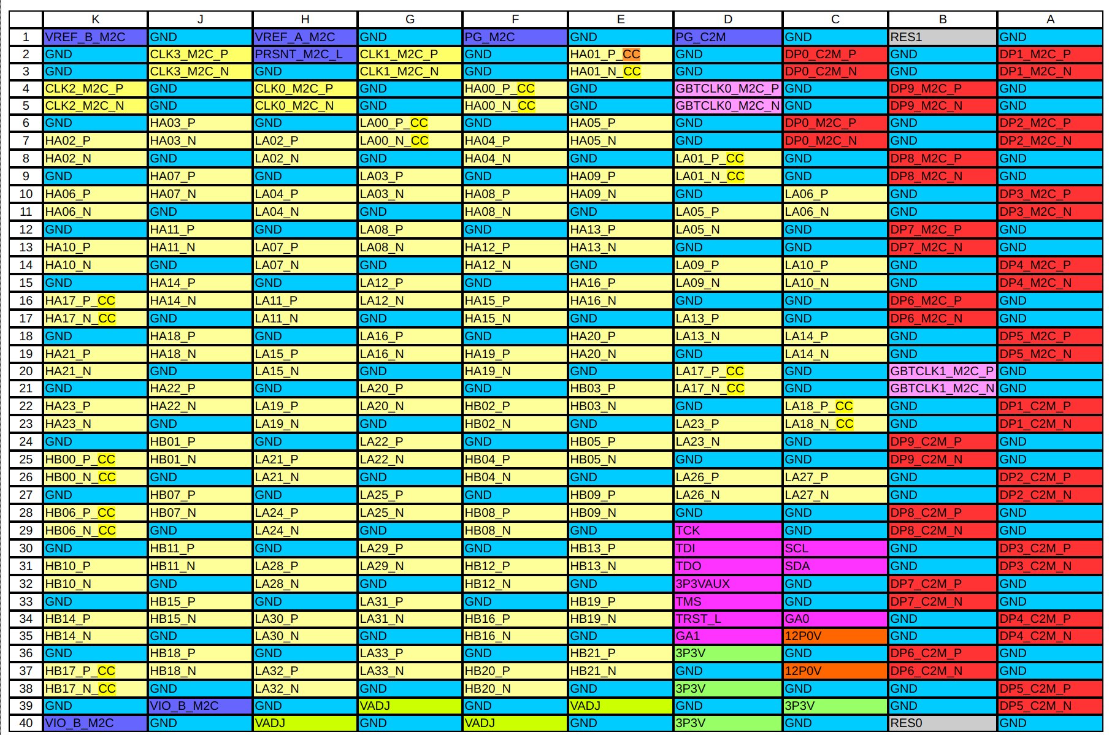
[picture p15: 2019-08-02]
fmc-host/resources/fmc-hpc-pinout.jpg

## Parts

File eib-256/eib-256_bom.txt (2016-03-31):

Manu.	Qty	Part Number
Hirose 	4 	DF40C-70DP-0.4V(51)

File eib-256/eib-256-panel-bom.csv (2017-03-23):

Part/Designator | Manufacture Part Number/Seeed SKU | Quantity
A,B,C,D | DF40C-70DP-0.4V(51) | 36

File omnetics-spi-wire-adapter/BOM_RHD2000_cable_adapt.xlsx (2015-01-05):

Bill of Materials |  | RHD2000 Cable Adapter |  | Intan Technologies, LLC
Part | Value | Device | Package | Digi-Key part number | Notes
S1 | PZN-12-AA | polarized nano connector | polarized 12-pin | Omnetics A79623-001

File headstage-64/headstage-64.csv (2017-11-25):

Qty | Value | Device | Package | Parts | Description | PARTNO | PARTNP | TP_SIGNAL_NAME
3 |  | PHOTODIODE_0805T | 0805T | D1, D2, D3
1 |  | PINHD-2X35+4_DF40-70HEAD | DF40-70HEAD | U$1
5 |  | TPB0.4MM | B0.4MM | TP3, TP4, TP5, TP6, TP12 | Test pad
3 |  | TPTP06R | TP06R | TP7, TP9, TP11 | Test pad
8 | 0.1uF | C_0201T | 0201T | C36, C48, C56, C58, C60, C61, C64, C67 | Capacitor
1 | 0.1uF | C_0201T | 0201T | C10 | Capacitor |  | CL03A104KA3NNNC
6 | 0.1uF | C_0201T | 0201T | C2, C4, C6, C12, C13, C70 | Capacitor | C0603X5R1C104K030BC
1 | 0.1uF | C_0201T | 0201T | C51 | Capacitor | C1005X7R1H104K050BB
5 | 0.1uF | C_0201T | 0201T | C7, C8, C11, C20, C21 | Capacitor | CL03A104KA3NNNC
1 | 0.1uF | C_0402T | 0402T | C26 | Capacitor | C0603X5R1C104K030BC
2 | 0.22uF | C_0402T | 0402T | C17, C18 | Capacitor | UMK105BJ224KV-F
3 | 0.47uF | C_0201T | 0201T | C40, C45, C72 | Capacitor | GRM033R60J474KE90D
4 | 100 | R_0201T | 0201T | R26, R27, R28, R29 | Resistor
1 | 100k | R_0201T | 0201T | R20 | Resistor
1 | 10M08DC | 10M08DC_VBGA | VBGA81-4X4 | U11
13 | 10k | R_0201T | 0201T | R4, R5, R17, R18, R19, R23, R30, R31, R32, R34, R35, R36, R38 | Resistor
9 | 10nF | C_0201T | 0201T | C27, C38, C43, C47, C49, C50, C57, C62, C65 | Capacitor
1 | 10nF | C_0201T | 0201T | C30 | Capacitor | CL03A105MP3ZSNH
1 | 10nF | C_0201T | 0201T | C66 | Capacitor | CL03B103KP3NNNC
1 | 10pF | C_0201T | 0201T | C19 | Capacitor
3 | 10uF | C_0402T | 0402T | C22, C24, C42 | Capacitor | CL05A106MQ5NUNC
4 | 15k | R_0201T | 0201T | R1, R2, R3, R37 | Resistor
2 | 1M | R_0201T | 0201T | R9, R11 | Resistor
3 | 1k | R_0201T | 0201T | R14, R15, R33 | Resistor
7 | 1uF | C_0201T | 0201T | C1, C3, C5, C46, C55, C68, C74 | Capacitor | CL03A105MP3ZSNH
7 | 1uF | C_0402T | 0402T | C14, C15, C16, C23, C54, C69, C75 | Capacitor | CL05A105KO5NNNC
1 | 2.2nF | C_0201T | 0201T | C35 | Capacitor
1 | 220 | R_0201T | 0201T | R7 | Resistor
4 | 22nF | C_0201T | 0201T | C33, C39, C44, C71 | Capacitor
1 | 22uF | C_0402T | 0402T | C53 | Capacitor | CL05A226MQ5QUNC
1 | 22uF | C_0402T | 0402T | C41 | Capacitor | CL05A226MQ6ZUN8
2 | 2k | R_0201T | 0201T | R24, R25 | Resistor
2 | 4.7k | R_0201T | 0201T | R21, R22 | Resistor
4 | 4.7nF | C_0201T | 0201T | C29, C31, C32, C37 | Capacitor
1 | 4.7uF | C_0402T | 0402T | C25 | Capacitor | CL05A475MO5NUNC
2 | 4.7uF | C_0402T | 0402T | C59, C63 | Capacitor | GRM155R61A475MEAAD
1 | 470pF | C_0201T | 0201T | C9 | Capacitor
2 | 47nF | C_0201T | 0201T | C28, C34 | Capacitor
1 | 47nF | C_0201T | 0201T | C52 | Capacitor | C1005X7R1H473K050BB
1 | 49.9 | R_0201T | 0201T | R16 | Resistor
1 | 5.49k | R_0201T | 0201T | R6 | Resistor
1 | 50 | R_0201T | 0201T | R13 | Resistor
1 | 600 | R_0201T | 0201T | R8 | Resistor
1 | 83.3k | R_0201T | 0201T | R10 | Resistor
1 | 90.9k | R_0201T | 0201T | R12 | Resistor
1 | ADG1401 | ADG140X_LFCSP | LFCSP8-2X3 | U8 |  | ADG1401BCPZ
3 | BLM15PX601SN1D | L_0402T | 0402T | L5, L6, L7 | Inductor | BLM15PX601SN1D
1 | BLM18KG601SN1D | L_0603T | 0603T | L12 | Inductor
1 | CAT4016_QFN | CAT4016_QFN | QFN24-4X4 | U3 |  | CAT4016HV6-GT2
1 | CBC3225T101MR | L_1210T | 1210T | L4 | Inductor
1 | CIG21L4R7MNE | L_0805T | 0805T | L3 | Inductor
1 | DAC5311 | DAC5311 | SC70 | U13
1 | DS90UB913A_WQFN | DS90UB913A_WQFN | WQFN32-5X5 | U19
1 | GND_LINK_0201 | GND_LINK_0201 | 0201_LINK | J3
1 | HEADSTAGE64_EDGE-MOUNT | HEADSTAGE64_EDGE-MOUNT | HEADSTAGE64-EDGE-MOUNT_PADS | J1
1 | HEADSTAGE64_EDGE-MOUNT_CASTELLATED | HEADSTAGE64_EDGE-MOUNT_CASTELLATED | HEADSTAGE64-EDGE-MOUNT_CASTELLATED | J2
1 | INA826 | INSTRUMENTAMP_PWSON | PWSON-N8-3X3 | U15 |  | INA826AIDRGR
1 | LT3463 | LT3463 | DFN103X3 | U12
2 | MLZ2012M100WT000 | L_0805T | 0805T | L1, L2 | Inductor
1 | MPU9250_QFN_NO-PAD | MPU9250_QFN_NO-PAD | QFN24-3X3_NO-PAD | U2
1 | OPA170 | OPAMP_PDSO | PDSO-N5 | U4 |  | OPA170AIDBVR
1 | RHD2164_COB3 | RHD2164_COB3 | RHD2164_COB3 | U7 | Intan Technologies RHD2164 chip
1 | TLV70712 | TLV707 | X2SON | U17
1 | TLV70718 | TLV707 | X2SON | U10
1 | TLV70725 | TLV707 | X2SON | U9
1 | TLV70733 | TLV707 | X2SON | U18
1 | TPL0501_UQFN | TPL0501_UQFN | UQFN | U25 |  | TPL0501-100RSER
4 | TS4231 | TS4231 | WLCSP3X3 | U1, U5, U6, U14
2 | VCC | TPB0.3MM | B0.3MM | TP8, TP10 | Test pad
1 | VCC | TPB0.4MM | B0.4MM | TP1 | Test pad
1 | VSKY05401006 | S-DIODE_0402T | 0402T | D4 | Schottky Diode
1 | X.FL-R-SMT-1 | COAX_XFL | X_FL_R_SMT_1(02) | X1 | COAX CONNECTOR
2 | XZVGR155W | LED_0201T | LED-0201T | D5, D6 | Surface mount LED
1 | gnd | TPB0.4MM | B0.4MM | TP2 | Test pad

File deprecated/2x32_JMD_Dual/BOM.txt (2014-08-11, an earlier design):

HEADSTAGE and SPI-INTERFACE:
https://docs.google.com/spreadsheets/d/1sSIfUUQQ63w412H609otfNJevaj0tG3jFlzK6JuryBI/edit?usp=sharing

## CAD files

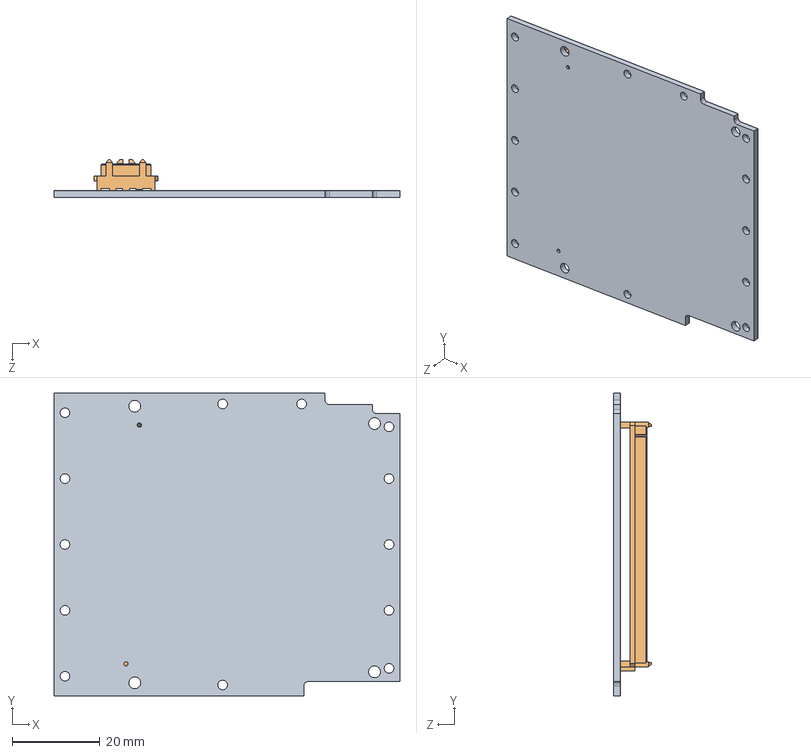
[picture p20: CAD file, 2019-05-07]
fmc-host/pcie_case/refs/WaveTherm-OC-PCB-FMC.SLDASM
78.8 x 69.0 x 8.71 mm
WaveTherm-OC-PCB-FMC_OC-PCB-FMC
WaveTherm-OC-PCB-FMC_SAMTEC_ASP-134488-01

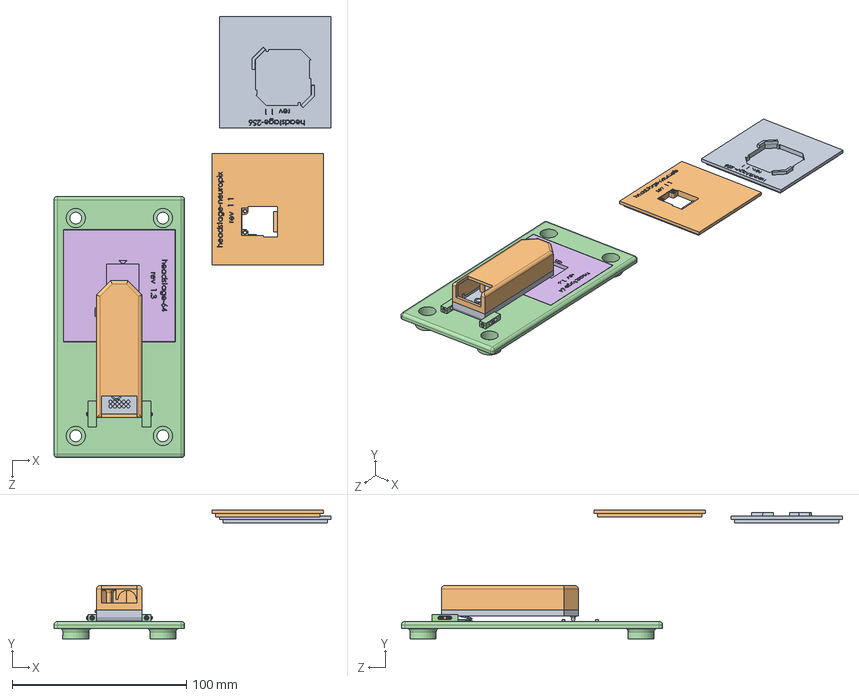
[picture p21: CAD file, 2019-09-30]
headstage-programmer/mechanical/headstage-programmer-jig.SLDASM
159.0 x 73.8 x 253.3 mm
pcb-housing-base
pcb-housing-top
button-cap
jig-base
91595A151_ALLOY STEEL DOWEL PIN
headstage-64-holder
92605A047_NONMARRING FLAT POINT SET SCREW x 4
1692K130_TYPE 302 SS CONICAL COMPRESSION SPRING
headstage-256-holder
headstage-neuropix-holder

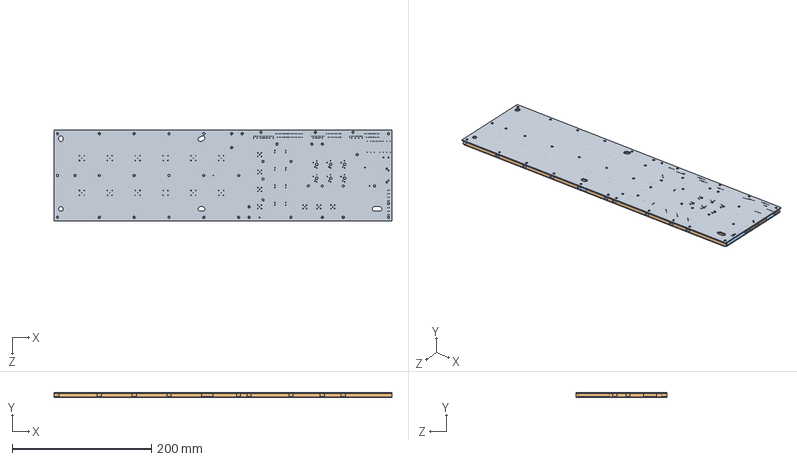
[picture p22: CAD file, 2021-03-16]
breakout/case/breakout_assembly_bottom_only_lasercut.SLDASM
485.0 x 7.10 x 130.0 mm
breakout_case_pcb_3
pcb_spacer_lasercut
pcb_bottom_waterjet

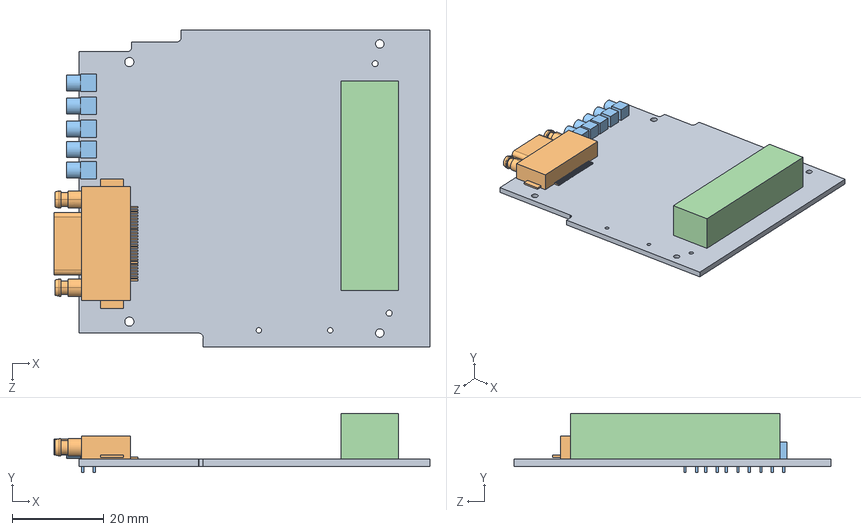
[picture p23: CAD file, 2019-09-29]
fmc-host/revisions/rev-1.4/pcie_bracket/fnc_host_with_connectors.SLDASM
81.9 x 12.9 x 69.0 mm
fmc_pcb
cameralink_12226-8250-00FR
mmcx_through_hole x 5
FMC_10mm_stackheight_spacer

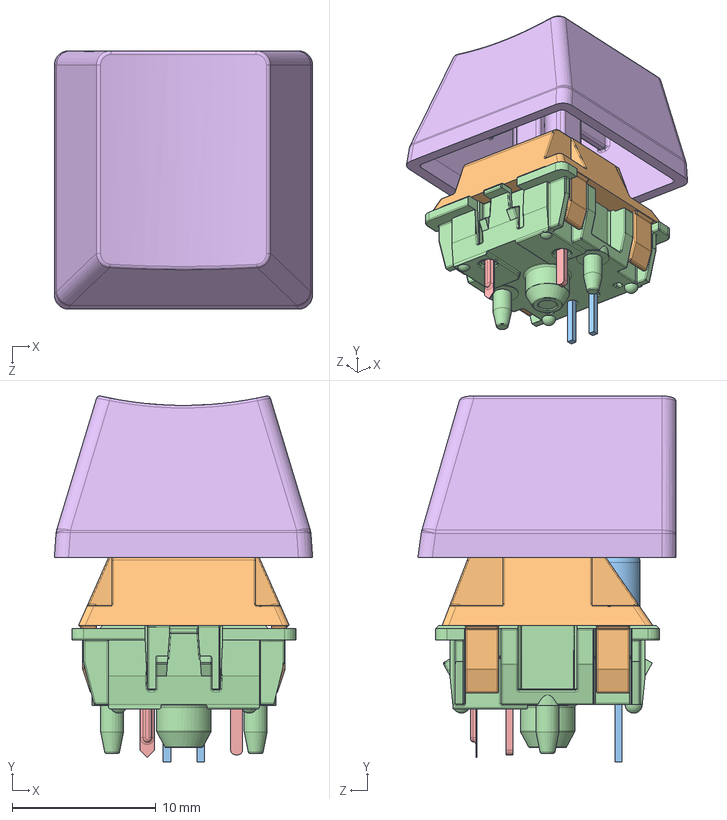
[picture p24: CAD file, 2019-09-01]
breakout/case/components/cherryMX/MX 按键.SLDASM
18.0 x 25.5 x 18.0 mm
MX 轴 按键
MX 轴 轴体
MX轴 无帽LED
MX轴 轴体 底部
针脚
MX 轴标准键帽

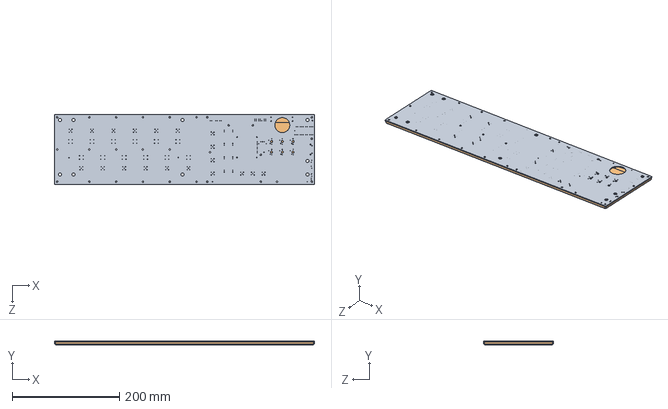
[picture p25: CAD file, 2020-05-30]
breakout/case/breakout_assembly_bottom_only.SLDASM
485.0 x 6.60 x 130.0 mm

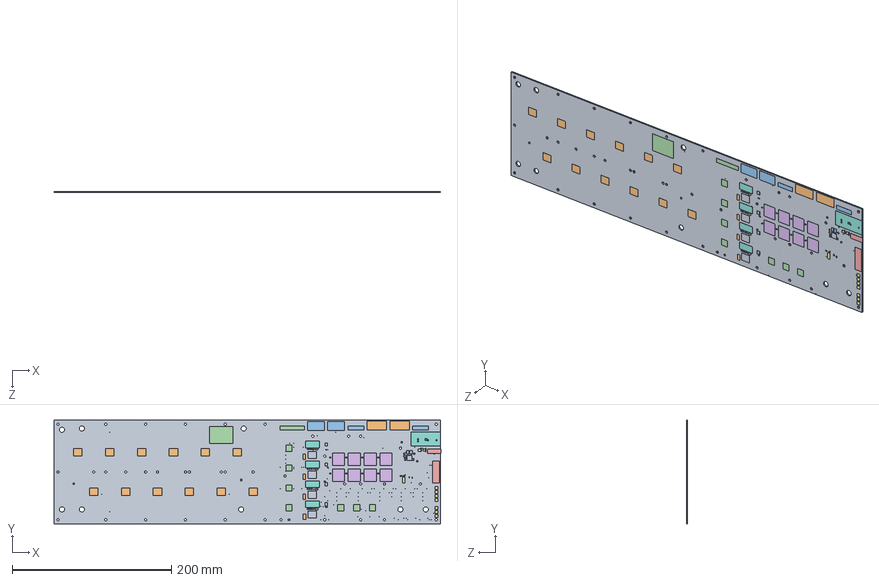
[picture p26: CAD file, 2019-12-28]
breakout/case/breakout_pcb.SLDASM
485.9 x 130.0 x 1.79 mm
Board.step
0731010360.step x 12
1789472.step x 2
SMA_JACK_142-0701-201.step x 7
TESTPOINT_2MM.step x 4
FIN1032MTCX.step
SN65LVDS9638DGN.step x 2
1k.step x 43
LTM4622A.step
10uF.step x 5
47uF.step x 2
TP19R.step x 3
SJ1-3514-SMT-TR.step
SI8610.step
MMCX-THRU.step x 7
7101J1V3BE2.step x 4
G6K-2F-RF.step x 4
P6SMB18CA.step x 16
SI1012R.step x 4
OE-LOGO_28X20.step
12226-8250-00FR.step
CHERRY-MX.step x 8
TCA9555.step
TINY-FPGA-BX.step
LED3MM.step x 4
1888276.step x 2
69168-116HLF.step x 2
69168-124HLF.step

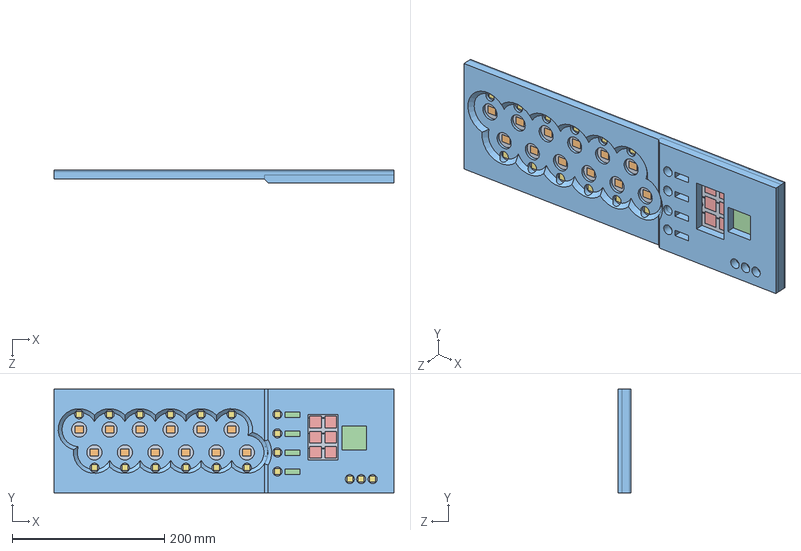
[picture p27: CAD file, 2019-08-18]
breakout/case/analog-io-breakout_assembly.SLDASM
446.0 x 136.0 x 16.6 mm
Board.step
0731010360.step x 12
FE10-2.step
MMCX-J-P-X-RA-SM1.step x 7
SCREW2.step x 2
SCREW8.step x 2
SMA_JACK_142-0701-201.step x 19
TESTPOINT_2MM.step
DIODE-ESD-BIDIRECTIONALDO-214AA.step x 12
TEENSY_3.1_BASIC.step
1503_02.step
ADAFRUIT_1_5_OLED.step
CHERRY-MX.step x 6
12226-8250-00FR.step
1k.step x 34
SJ_2_0201.step x 2
LTC2875_DFN.step
FIN1032MTCX.step
SN65LVDS9638DGN.step x 2
ROCKER_SWITCH.step x 4
G6KU-2F-RF-TR09DC5.step x 4
LTM4622A.step
10uF.step
47uF.step x 2
B1,27.step x 2
TCA9555.step
breakout_case_top_shell

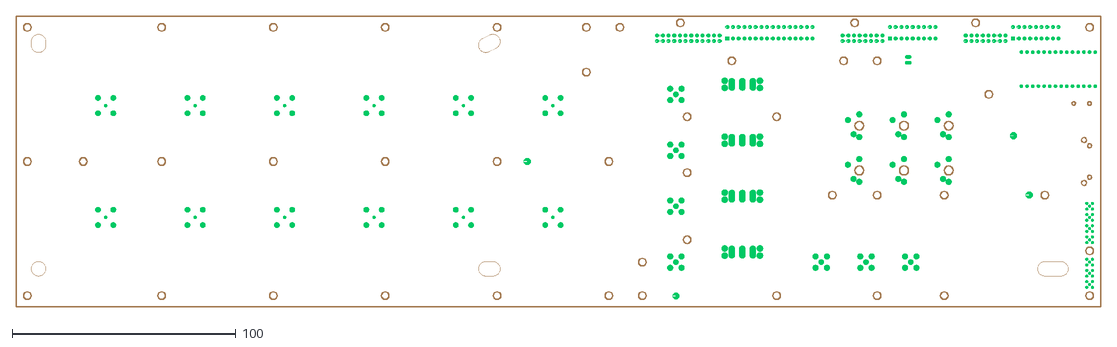
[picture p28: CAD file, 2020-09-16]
breakout/breakout.dxf
485.0 x 130.0

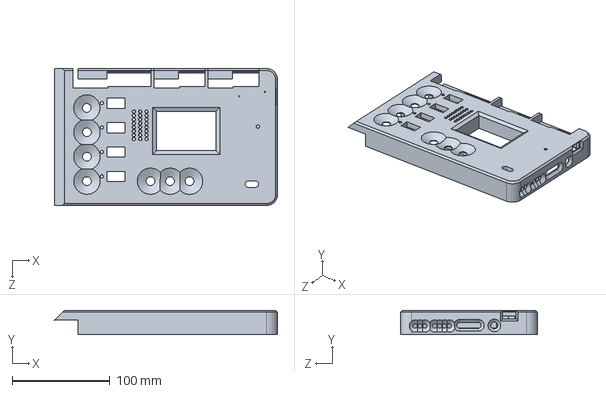
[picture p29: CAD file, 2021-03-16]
breakout/case/Body4.sldprt
228.0 x 25.0 x 140.0 mm

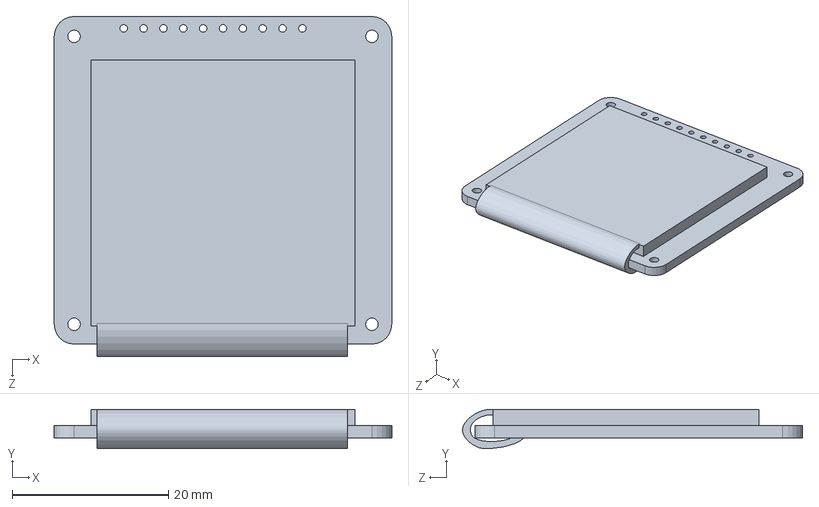
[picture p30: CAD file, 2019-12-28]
breakout/case/components/1_5_inch_screen/oled_module.SLDPRT
43.2 x 5.05 x 43.5 mm

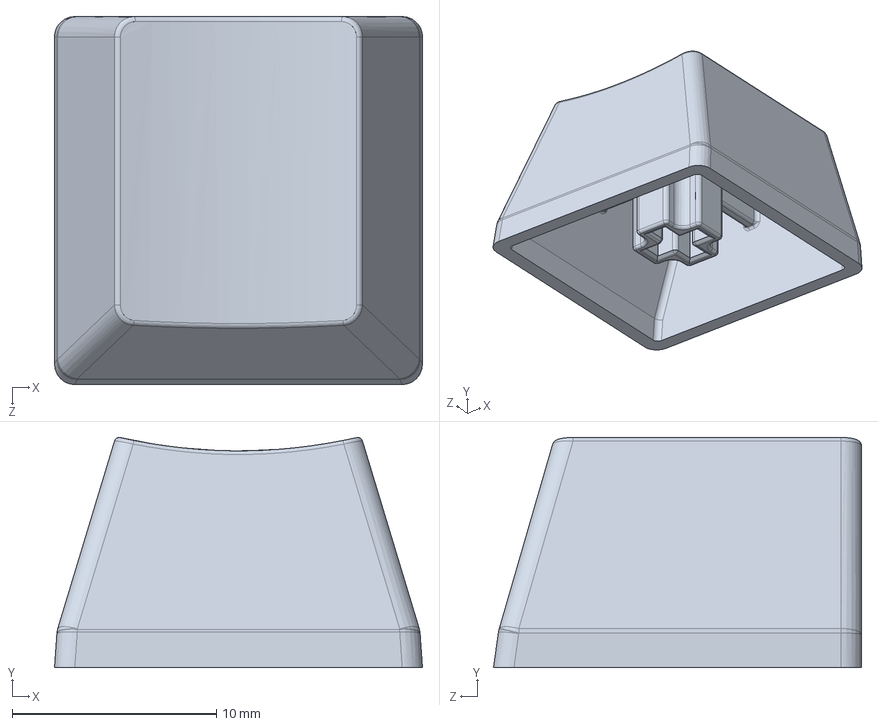
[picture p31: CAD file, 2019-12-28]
breakout/case/components/cherryMX/MX 轴标准键帽.SLDPRT
18.0 x 11.3 x 18.0 mm

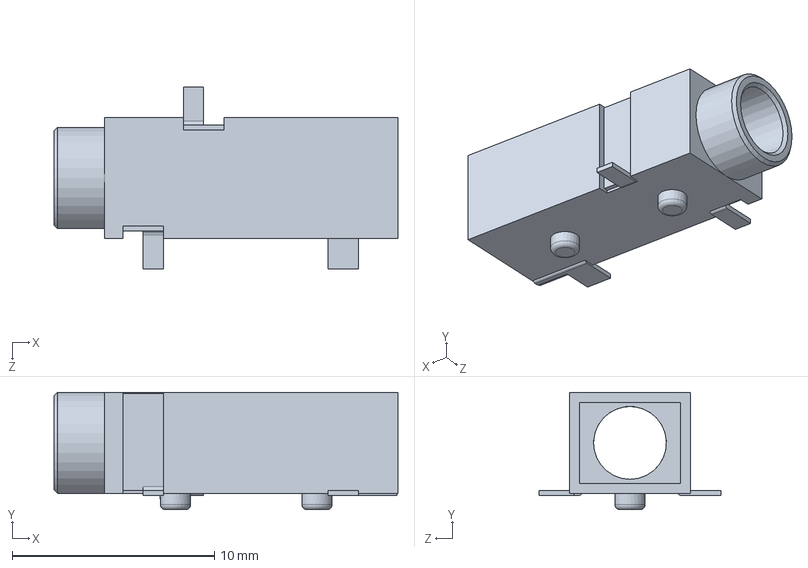
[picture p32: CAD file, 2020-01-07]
breakout/case/components/CUI_DEVICES_SJ-3523-SMT-TR.sldprt
17.0 x 5.80 x 9.00 mm

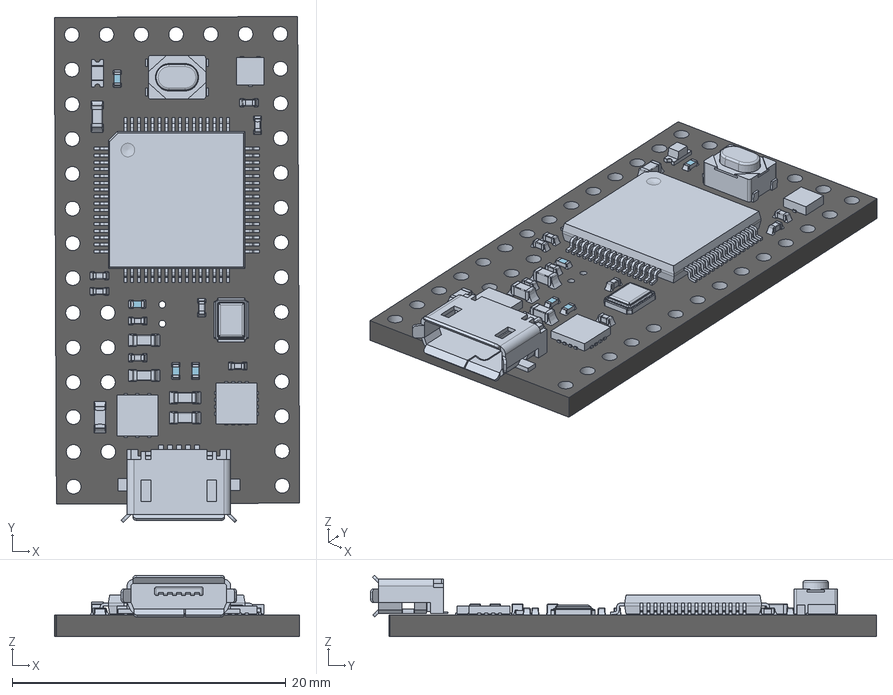
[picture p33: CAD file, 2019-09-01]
breakout/case/components/teensy/Teensy_3_1.stp
17.9 x 37.0 x 4.49 mm
board
micro_usb_plastic (1)
micro_usb_shell (1)
lead
package (1)
lead (3) x 64
package
lead (1)
cap0402 v2 x 6
lead (2)
diode_0402 v1 x 4
cap0603_03 v3 x 5
cap0402 v2 (1) x 2
smt_led_0805 v2
resistor_0603 v3

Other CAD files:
breakout/case/components/switch_7101J1V3BE2/7101J1V3BE2.sldasm
breakout/case/components/switch_7101J1V3BE2/1_4.sldprt
breakout/case/label/onix_logo_bw.dxf
doc/size_comparison/rhd64.SLDPRT
breakout/case/Body3.sldprt
breakout/case/Draw2.DXF
breakout/case/Draw2.SLDDRW
breakout/case/LPA-C011302S-2_lightpipe.SLDPRT
breakout/case/Part157.SLDPRT
breakout/case/WP154A4SEJ3VBDZGW-CA_rgb-led.SLDPRT
breakout/case/analog-io-breakout.step
breakout/case/breakout_case_bottom_shell.SLDPRT
breakout/case/breakout_case_bottom_shell.STL
breakout/case/breakout_case_pcb.SLDPRT
breakout/case/breakout_case_pcb_2.SLDPRT
breakout/case/breakout_case_pcb_3.SLDPRT
breakout/case/breakout_case_top_shell.SLDPRT
breakout/case/breakout_case_top_shell.STL
breakout/case/breakout_case_top_shell_draft.SLDPRT
breakout/case/components/1_5_inch_screen/Adafruit_1.5_128x128_RGB_OLED.dxf
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

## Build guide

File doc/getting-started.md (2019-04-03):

# Getting started with Open Ephys++ headstages
To use the headstages in this project in your own lab, you will need the
following components:

1. Microdrive 
1. EIB 
1. Headstage 
1. Coaxial cable\*
1. Commutator (optional)
1. FMC host board
1. Numato Nereid PCIe carrier board
1. Acquisition Software
1. Plating board (optional; 1 per lab is standard)
1. Test board 

\* Choice depends on animal size

"Starter packs" containing all the equipment you will need to get started will
soon be available though the [Open Ephys Store](http://www.open-ephys.org/store/).

Lets step through each of these and detail where to get them and how to
assemble them together to create the full system. In general, our designs focus
on chronically implanted, independently adjustable arrays of electrodes (called
microdrives). Some good starting places for learning about how to assemble
these devices are enumerated below:

1. [HD Shuttle Drive]() Details our most Our most recent drive design. It is
packed with detail on the assembly process
1. [Tetrode Fabrication with Twister3]() Our open-source tetrode twisting
   machine which greatly improves tetrode making speed and reliability compared
   to other methods.
1. [Tetrode Fabrication](https://www.ncbi.nlm.nih.gov/pmc/articles/PMC2794082/) Dated but contains relevant info.
1. [Old-school Drive Fabriation](https://www.ncbi.nlm.nih.gov/pmc/articles/PMC2793172/) Dated but contains relevant info.
1. TODO 

### Microdrive
The [HD-Shuttle Drives](TODO), which works with the headstages in this project, can
be purchased directly from the open ephys store. See [the paper](TODO) for assembly
instructions. 

### Electrode interface boards (EIBs)
EIBs can be purchased directly from the open ephys store. Variants are
available for both the first generation open-ephys system and the hardware in
this project. These are generally used for pinning out tetrodes. Custom EIBs
with conforming form factors can be made for a variety of probes (e.g. silicon
probes). If you want to make a new EIB for our headstages, please get in
contact using an issue on this repository se we can plan it out together.

### Headstages
[headstage-64](../headstage-64) purchased directly from the open ephys store.
It's FPGA is pre-flashed to acquire from all avaialble sensors.

### Coaxial Cable
TODO

### Commutator
TODO

### Host Acquisition Board

#### Board installation
1. Press the FMC host cared into the FMC connector on the Nereid carrier board.
1. Insert the four screws that hold the FMC host board into place on the Nereid
   carrier board (2 around FMC connector and two on front bezzel.
1. Shut down your computer and flip the switch to off on the ATX power supply.
1. Insert the Numato Nereid board/FMC host tinto an availabl PCIe slot.
1. Insert an 6-pin available ATX conenctor into the white receptible on the
   Nereid carrier board.
1. Turn your computer, on. The fan on the Nereid board should be active.
1. If your the board has not been pre-flashed, it will not be recognized when
   you reboot your computer. This is normal.

#### Programming the host board
If you have a pre-flashed and press-assembled host board, then skip to step XX.

TODO: can i program without download cable
TODO: Is there a standalone programming tool?

1. Install Vivado Webpack
1. Download the bit files here:
1. TODO: copy nereid instructions
1. Reboot your comptuer

#### Install device drivers (Windows only)
1. When your reboot, you should see unknown device in device manager (
1. TODO: copy xillybus guide
1. Reboot your computer
1. Now you should see the device show up as so:

####

### Host Software
There are currently two options for acquiring data

1. [Bonsai]()
2. [Open Ephys GUI]()

#### Using Bonsai
TODO

#### Using Open Ephys GUI
TODO

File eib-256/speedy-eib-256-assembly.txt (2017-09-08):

Speedy circuits
Assembly instructions for eib-256-panel-assembly

## Bill of Materials
Assembly requires only one part:

    - Part number: Hirose DF40C-70DP-0.4V(51)
    - This is a 70 pin header
    - This is placed 4x per board
    - There are 12 boards per panel, so each panel requires 48 parts.

## Part placement
With respect to the center of each circular PCB, the _center_ locations of each
header, with A, B, C, D labels in silkscreen layer, are as follows:

    - A: -4.773 mm, 12.528 mm @ 34 deg
    - B: 4.773 mm, -12.528 mm @ 214 deg
    - C: -12.528 mm, -4.773 mm,  @ 124 deg
    - D: 12.528 mm, 4.773 mm, @ 304 deg

Each PCB in the panel is spaced on 50 mm grid, and this can be used to obtain
the positions of all the headers.

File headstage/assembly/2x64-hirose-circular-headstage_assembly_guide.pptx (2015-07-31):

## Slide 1

RHD2164 Headstage 1 Board

FR406 material, 0.036” thick, ENIG (immersion gold) plating (2 μm)
No through-hole components; only SMDs

0.550”

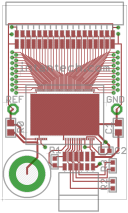
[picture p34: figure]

0.863”

actual size

0.1” hole in corner

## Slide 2

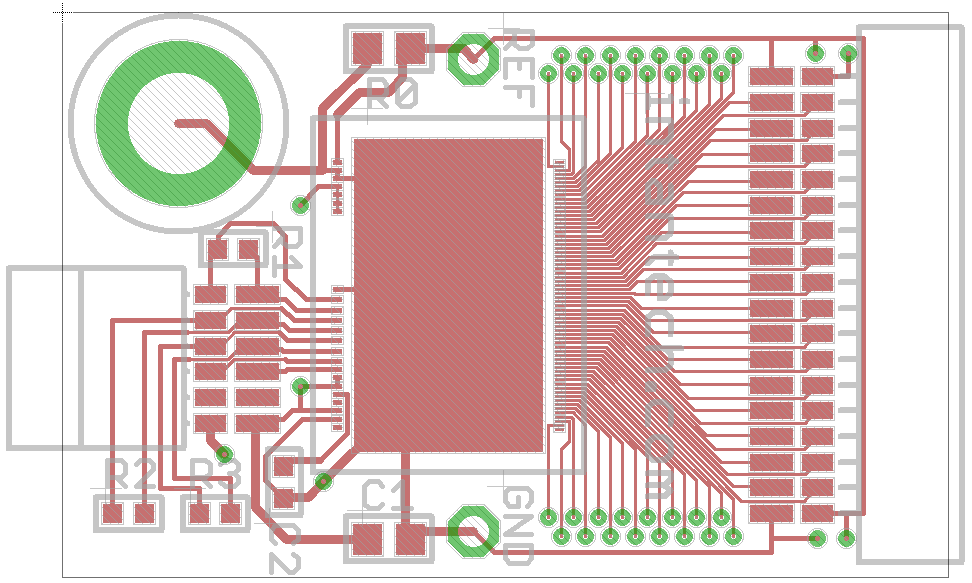
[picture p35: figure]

Top Components (9 total)

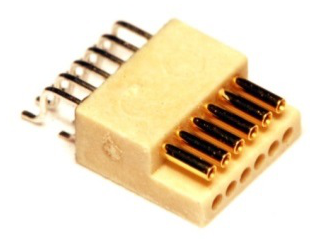
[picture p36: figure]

Omnetics A79623 connector

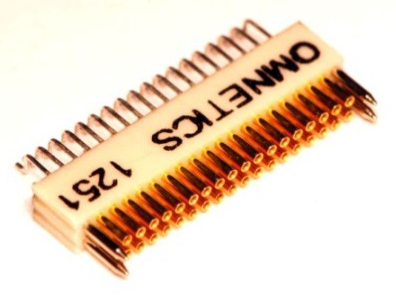
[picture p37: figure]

R1: 100 Ω (0201)

R0: 0 Ω (0402)

Omnetics A79025 connector

1 pad not bonded

RHD2164 bare die
(7.3 mm x 4.2 mm, 0.20 mm thick)
85 total bondwires

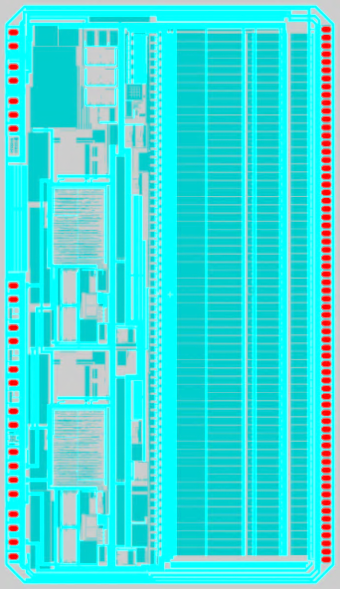
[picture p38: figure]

3 pads not bonded

R2: 100 Ω (0201)

R3: 100 Ω (0201)

C2: 0.01 μF (0201)

C1: 0.1 μF (0402)

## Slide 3

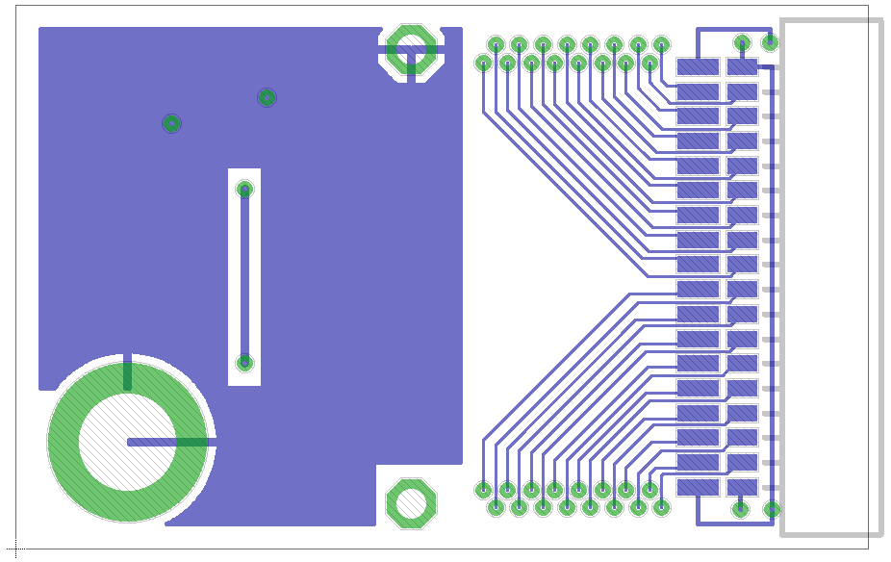
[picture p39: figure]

Bottom Components (1 total)

Omnetics A79025 connector

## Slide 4

Intan Technologies RHD2164 Bare Die

Approximately 7.3 mm

Gray = approximate outline of die (may vary from die to die due to variations in sawing)

Yellow Cross = center of design (may not coincide precisely with center of die due to variations in sawing)

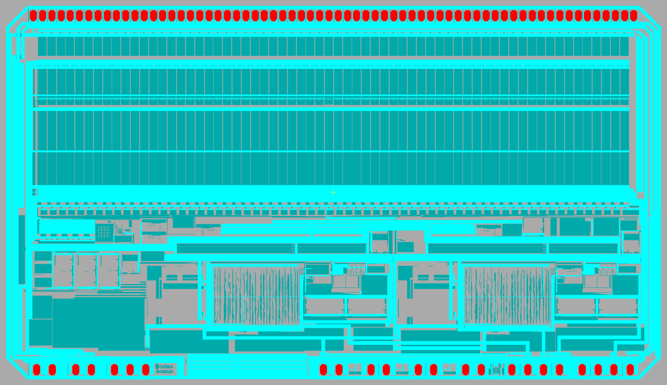
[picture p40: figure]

Approximately 4.2 mm

Blue, Green = top metal layers (highly visible)

Red = glass openings for bond pads

Each die is 0.20 mm (8 mils) thick

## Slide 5

Bond Pad Dimensions

Bond pad metal: AlCu (99.5% aluminum, 0.5% copper)

72.0 μm

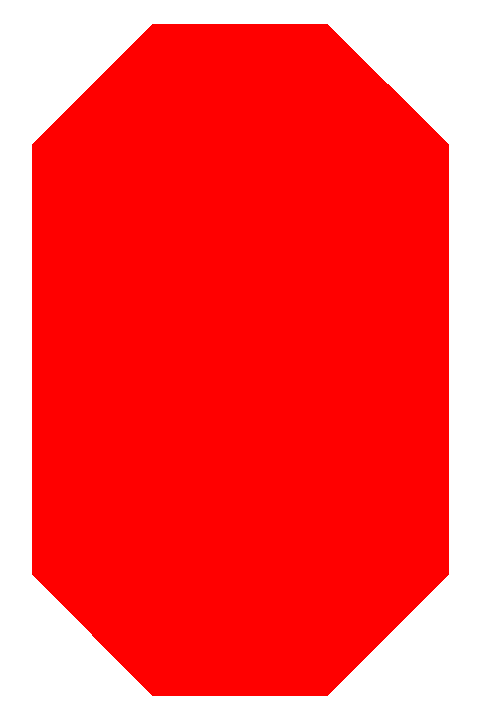
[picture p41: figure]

116.0 μm

74.2 μm

Minimum bond pad pitch (center to center) on RHD2164: 101.6 μm (4.000 mil)

30.2 μm

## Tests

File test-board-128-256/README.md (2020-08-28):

# test-board-128-256
Test board for [headstage-256](../headstage-256). Allows injecting simulated
biopotentials into headstage modules via a selectable passive attenuator.
Provides LEDs and simulated electrical loads for optical and electrical
stimulation.

test-board-128-256

## Gerber Files
{% include gerber_layers.md %}

## Bill of Materials
The BOM is located on [this google
sheet](https://docs.google.com/spreadsheets/d/1F-KWcdvH_63iXjZf0cgCfDiFX6XXW3qw6rlR8DZrFpQ/edit#gid=1193719109)

## Pinout
The EIB pinout (ADC input mapping, stimulation connections, etc) is located on
[this google
sheet](https://docs.google.com/spreadsheets/d/11wRDYOqHN5lPb03yUdfXfK0zvaDYsVetplaNK-R90Gg/edit#gid=663991061)

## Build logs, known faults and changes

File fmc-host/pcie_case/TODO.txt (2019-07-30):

1. Built in mechanical backing for the MMCX connectors so ppl dont rip them out

2. 10 pin header slot on top of case for MLVDS ribbon cable.

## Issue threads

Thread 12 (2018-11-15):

Congratulation

samuelgarcia, 2018-11-15:
What you have done before was super great.
Here, this is totally amazing.
Thank a lot.

At some point, if you need help to make a python layer over the C library I can help.

best,

Samuel

jonnew, 2018-11-15:
Hi Thank you! For sure a python binding would be fantastic. If you want to give it a go, I'm happy to review PRs. Is there any software in particular that you want to target with a Python binding?

samuelgarcia, 2018-11-16:
I have in mind [pyacq](https://github.com/pyacq/pyacq), [idephyx](https://github.com/pyacq/idephyx) and [tridesclous](https://tridesclous.readthedocs.io/en/latest/). My tools to make distributed spike sorting. (GPU based at some levels)

My first step will be to bind directly the openephys USB board in python and integrate it in pyacq.
I already write something about it on the mailing list.
For this, I will need to bind the C++ code from intan and opalkelly.

For for this new openephys++, if I anderstand corectly you release a C library.
So the python binding would be a lot easier and more efficient..

jonnew, 2018-11-26:
Sorry for the delay. Yes, the library is located in [api](https://github.com/jonnew/open-ephys-pcie/tree/master/api) folder. There are already two bindings in there, C++ and C#. PRs for pythong bindings for python are welcome. You can look at how I did the C++ and C# bindings for some inspiration.

samuelgarcia, 2020-05-21:
Is it possible to open back this issue.
I plan finally to make a python binding for it.

jonnew, 2020-05-21:
Yep, most def. Lemme know if you have questions!

samuelgarcia, 2020-05-21:
I will have a look at the API when a skeleton of the dummy device will be started.
It will be more easy for me.
In 12 month if nothing happen you can close the PR again :)

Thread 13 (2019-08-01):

Rust bindings for liboepcie

imalsogreg, 2019-08-01:
An interface to this beloved language is sorely needed! (feel free to assign to me)

jonnew, 2019-08-28:
Greg, I'm so sorry for taking so long to respond to this generous issue. There is currently no acquisition software written in rust, that I'm aware of. However, if we had this binding it might inspire that to change.   So, I would love to have this so long as it does not become a maintenance issue.I also would love to learn the language better so maybe you could help me with that via this effort. So, PR away -- I'm excited :).

jonnew, 2020-04-20:
I'm closing this until there is a re-invigoration!

Closed 2020-04-20.

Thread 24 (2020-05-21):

Create dummy oni driver

aacuevas, 2020-05-21:
Having the ability to test the API without hardware would be useful for testing.

Using the driver interface it is possible to create a dummy driver that exposes fictional hardware with a fixed set of devices and streams to the API.

samuelgarcia, 2020-05-21:
Ideally a simple read in loop binary file that represent multi channel signal with timed small chunk would perfect.

This driver would have the following  config params:
  * the binary file path
  * the sample rate
  * the dtype
  * channel count
  * buffer size
The timing would depend on sample rate and buffer size.

jonnew, 2020-05-21:
The old code I was using to do this back when we were using Xillybus is [here](https://github.com/jonnew/open-ephys-pcie/blob/c6f697f10bcd9a60b35fd9be5fcd2020ccb786b3/api/liboni/liboni-test/firm_xilly.c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). This emulates all the signal, config, and high bandwidth read channels. It needs to be updates to work with the newer API. To do this, I would recommend turning this code into a driver as Aaron suggests.

samuelgarcia, 2020-05-21:
Yes I saw it. It confusing why it is named xilly or riffa.
Why don't you put this inside driver folder.
Is it the way to go ?

jonnew, 2020-05-21:
Yes, it is. Its not there because it predates the concept of a driver in this API.

jonnew, 2020-10-18:
This was completed over in the liboni repo: https://github.com/jonnew/liboni/commit/43445c99342cd45fb0b8e41a54e0dc8040af2dcb

samuelgarcia, 2020-10-19:
Good news. Thank you.

Closed 2020-10-18.

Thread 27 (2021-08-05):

Minor copy/paste issue in the pin mapping

ablot, 2021-08-05:
Line 57  of the [pin mapping](https://docs.google.com/spreadsheets/d/11wRDYOqHN5lPb03yUdfXfK0zvaDYsVetplaNK-R90Gg/edit#gid=0), the nanoZ channel is replaced by some random text ("The EIB pinout (ephys input mapping, stimulation connections, etc) is located on this google sheet").

I assume it should actually be nanoZ pin 57.

ablot, 2021-08-09:
There might be more issues with this file.

DF40 pin 37 is labelled as TT4B but seems to be connected to ground

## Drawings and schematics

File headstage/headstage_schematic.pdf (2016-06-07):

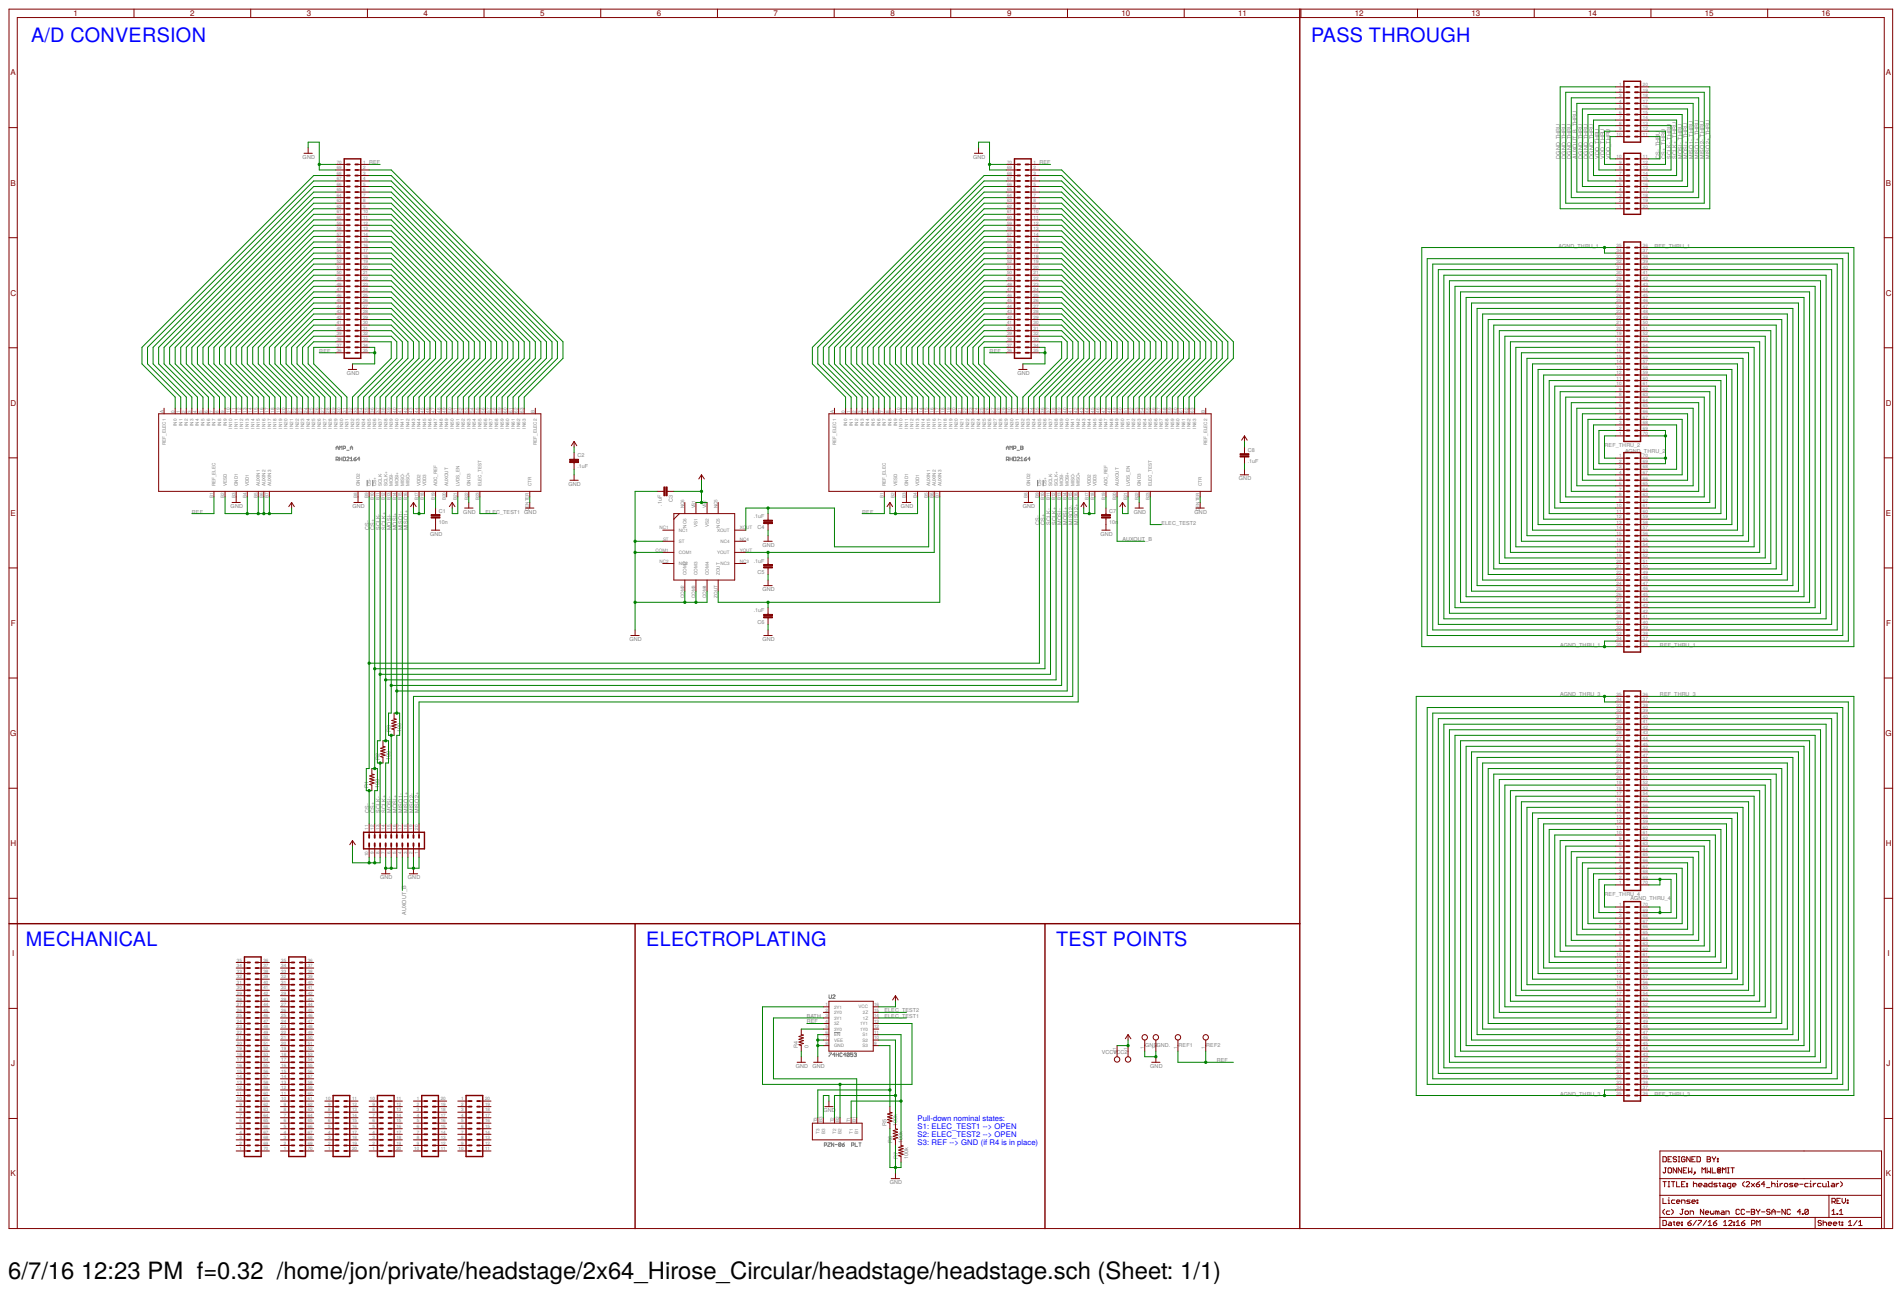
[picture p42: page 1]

2 | 19
3 5 4 | 18 16 17

CS- B9 CS+ B10 SCLK- B11 SCLK+ B12 MOSI- B13 VDD3 B18

NC6 NC6 ST ST VS1 VS1 VS2 VS2 XOUT XOUT YOUT YOUT

32 33 34 AGND_THRU_1 | 39 38 37

33 34 | 38 37
32 31 30 | 39 40 41

2 1 AGND_THRU_4 | 69 70

Pull-down nominal states: S1: ELEC_TEST1 --> OPEN
S2: ELEC_TEST2 --> OPEN
S3: REF --> GND (if R4 is in place)

6/7/16 12:23 PM f=0.32 /home/jon/private/headstage/2x64_Hirose_Circular/headstage/headstage.sch (Sheet: 1/1)

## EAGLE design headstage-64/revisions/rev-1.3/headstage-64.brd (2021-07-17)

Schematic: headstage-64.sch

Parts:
C1: 0.1uF; 0201T; PARTNP CL03A104KA3NNNC
C2, C3, C5, C6, C18, C27, C32, C33, C35: 0.1uF; 0201T; PARTNO C0603X5R1C104K030BC
C4, C8, C9: 0.1uF; 0201T; PARTNO CL03A104KA3NNNC
C7: 4.7uF; 0402T; PARTNO CL05A475MO5NUNC
C10, C14, C15, C21, C22, C45, C51, C59, C66, C71: 10nF; 0201T
C11, C13, C16, C20, C23, C30, C31, C48: 0.1uF; 0201T
C12, C17: 4.7uF; 0402T; PARTNO GRM155R61A475MEAAD
C19, C28, C34, C36, C49: 1uF; 0201T; PARTNO CL03A105MP3ZSNH
C24: 22uF; 0402T; PARTNO CL05A226MQ5QUNC
C25: 0.1uF; 0201T; PARTNO C1005X7R1H104K050BB
C26: 47nF; 0201T; PARTNO C1005X7R1H473K050BB
C29: 10nF; 0201T; PARTNO GRM033R71E103KE14D
C37, C39, C41, C55, C69: 10uF; 0402T; PARTNO CL05A105KO5NNNC
C38, C40, C54, C56: 10uF; 0402T; PARTNO CL05A106MQ5NUNC
C42, C64: 0.22uF; 0402T; PARTNO UMK105BJ224KV-F
C43: 2.2nF; 0201T
C44, C50, C58, C65: 4.7nF; 0201T
C46, C52, C60, C67: 22nF; 0201T
C47, C61: 47nF; 0201T
C53, C62, C68: 0.47uF; 0201T; PARTNO GRM033R60J474KE90D
C57: 10pF; 0201T
C63, C72: 1uF; 0402T; PARTNO CL05A105KO5NNNC
C70: 4.7uF; 0402T; PARTNO CL05A105KO5NNNC
C73: 22uF; 0402T; PARTNO CL05A226MQ6ZUN8
D1, D2, D3: SESD0402X1UN-0020-090; 0402T-DFN
D4, D5, D6, D8: VEMD1160X01; 0805PT
D7: XZVGR155W; LED-0201T
D9: VSKY05401006; CLP1006-2L
J1, J3, J6: COAX_XFL; X_FL_R_SMT_1(02)
J2, J4, J7: PINHD-1X4HEADSTAGE64-DAUGHTER-CARD-CASTELLATED; HEADSTAGE64-DAUGHER-CARD-CASTELLATED
J5: PINHD-1X4HEADSTAGE64_DAUGHTER-CARD; HEADSTAGE-64-DAUGHTER-CARD
J8: DF40C-70DP-0.4V(51); DF40-70HEAD-LESS-SILK
J9: PINHD-1X5_HALF_CONNETOR; DF40-10HEAD_HALF
L1, L3, L5: CIG21L4R7MNE; 0805T
L2: BLM18KG601SN1D; 0603T
L4: CBC3225T101MR; 1210T
L6, L7, L8, L10: BLM15PX601SN1D; 0402T; PARTNO BLM15PX601SN1D
L9, L11: MLZ2012M100WT000; 0805T
L12: LQM21PN1R0NGRD; 0805T
R1: 9k, 0.1%; 0201T
R2: 1k, 0.1%; 0201T
R3, R9, R10, R20, R21, R43: 1k; 0201T
R4, R5, R6, R7, R8, R11, R14, R16, R17, R18, R19: 10k, 0.1%; 0201T
R12, R31, R34, R35, R47: 100; 0201T
R13: 2.86k; 0201T
R15: 590; 0201T
R22, R23, R27, R28, R32, R33, R38, R39, R40, R49, R53, R54, R55, R56, R57: 10k; 0201T
R24, R26, R36, R42: 15k; 0201T
R25: 49.9; 0201T
R29: 0; 0201T
R30: 100k; 0201T
R37: 2k; 0201T
R41, R44, R51, R52: 4.7k; 0201T
R45, R50: 1M; 0201T
R46: 90.9k; 0201T
R48: 83.3k; 0201T
TP1, TP2, TP5, TP6: VCC; TP07R
TP3, TP4: TPTP09R; TP09R
TP7, TP8, TP9, TP10, TP11, TP12, TP13: TPTP06R; TP06R
TP14: gnd; TP06R
TP15: VCC; TP06R
U1: ADA4062-4ACPZ-R7; CP_16_27-L
U2: AD5681RBCPZ-1RL7; CP_8_10-L
U3: CAT4016_QFN; QFN24-4X4; PARTNO CAT4016HV6-GT2
U4: TPL0501_UQFN; UQFN; PARTNO TPL0501-100RSER
U5: DG509B; MQFN16-1.8X2.6
U6, U8, U11, U12: TS4231; WLCSP3X3
U7: RHD2064_BGA; BGA104_0.5MM
U9: DS90UB913A_WQFN; WQFN32-5X5
U10: BNO055; LGA-28-3.8X5.2
U13, U15: TLV70733; X2SON
U14: 10M08DC; VBGA81-4X4
U16: LT3463; DFN103X3
U17: TLV70725; X2SON
U18: TPS62621; XBGA6_1.2X0.8
U19: ASCO-50.000MHZ-EK-T3; ASCO
U20: TLV70712; X2SON

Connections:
!IMU_BL: R28.2, U10.4 (!BOOT_LOAD)
!IMU_RESET: R32.1, U10.11 (!RESET)
$N324: C50.1, C51.1, C52.1, C53.1, C54.1, L10.2, U14.A8 (VCCD_PLL2)
+1V2: C43.1, C44.1, C45.1, C46.1, C47.1, C48.1, C49.1, C73.1, L10.1, U14.B2 (VCC), U14.B9 (VCC), U14.H2 (VCC), U14.H8 (VCC), U20.1 (OUT)
+1V8: C13.1, C14.1, C15.1, C16.1, C17.1, C70.1, L6.1, L8.1, L12.1, R27.1, U9.11 (VDDT), U9.28 (VDDD), U18.C1 (FB)
+2V5: C56.1, C65.1, C66.1, C67.1, C68.1, C72.1, U14.B1 (VCCA3), U14.B8 (VCCA2), U14.J1 (VCCA1), U14.J9 (VCCA4), U17.1 (OUT), U20.3 (EN), U20.4 (IN)
+3V3: C3.1, C5.1, C18.1, C20.1, C21.1, C27.1, C31.1, C32.1, C35.1, C40.1, C58.1, C59.1, C60.1, C61.1, C62.1, C71.1, R22.1, R28.1, R32.2, R33.1, R37.1, R38.1, R39.1, R40.1, R41.2, R44.1, R51.2, R52.1, R53.1, R54.1, R55.1, R56.1, TP14.TP, U2.2 (VLOGIC), U4.7 (VDD), U6.C3 (DVDD), U8.C3 (DVDD), U9.25 (VDDIO), U10.3 (VDD), U10.28 (VDDIO), U11.C3 (DVDD), U12.C3 (DVDD), U14.D5 (VCCIO8), U14.E4 (VCCIO1_2), U14.E6 (VCCIO5_6), U14.F5 (VCCIO3), U15.1 (OUT), U19.1 (EN), U19.4 (VCC)
+3V3_AN: C30.2, C38.1, J9.4 (5), U7.M15 (VDD), U7.M16 (LVDS_EN), U7.N2 (VDD), U7.N15 (VDD), U13.1 (OUT)
+15V0: C1.1, C8.1, C42.1, R45.2, U1.3 (V+), U5.12 (V+), U16.1 (VOUT1)
-15V0: C4.1, C9.1, C57.2, C64.1, D9.A, R50.1, U1.10 (V-), U1.PAD (V-), U5.1 (V-)
AGND: C29.2, C30.1, C37.2, C38.2, J8.70, J8.M1, J8.M2, J8.M4, J9.M1 (1), J9.M2 (6), L7.2, R29.1, TP1.TP, U7.M2 (VESD), U7.M17 (GND), U7.N1 (GND), U7.N6 (GND), U13.2 (GND), U13.PAD (GND)
AUXIN2: J9.2 (3), TP6.TP, U7.N4 (AUXIN2)
AUXIN3: J9.1 (2), TP5.TP, U7.N3 (AUXIN1)
CONFIG_SEL: R57.1, U14.C6 (CONFIG_SEL/C6)
CONF_DONE: R56.2, U14.A2 (DIFFIO_RX_T24N/CONF_DONE/A2)
DAC_CS: U2.5 (!SYNC), U14.A5 (DIFFIO_RX_T18N/A5)
DATA1: U6.C1 (D/CFGDATA), U14.C7 (DIFFIO_RX_R33P/PLL_R_CLKOUTP/C7)
DATA2: U8.C1 (D/CFGDATA), U14.C3 (DIFFIO_RX_T26N/C3)
DATA3: U11.C1 (D/CFGDATA), U14.A7 (DIFFIO_RX_T16P/A7)
DATA4: U12.C1 (D/CFGDATA), U14.B6 (DIFFIO_RX_T16N/DEV_CLRN/B6)
DIN0: U9.19 (DIN0), U14.J6 (DIFFIO_TX_RX_B12P/J6)
DIN1: U9.20 (DIN1), U14.G6 (DIFFIO_TX_RX_B14N/G6)
DIN2: U9.21 (DIN2), U14.H7 (DIFFIO_TX_RX_B14P/H7)
DIN3: U9.22 (DIN3), U14.J7 (DIFFIO_TX_RX_B16N/J7)
DIN4: U9.23 (DIN4), U14.G8 (DIFFIO_RX_R7P/G8)
DIN5: U9.24 (DIN5), U14.G9 (DIFFIO_RX_R7N/G9)
DIN6: U9.26 (DIN6), U14.F7 (DIFFIO_RX_R1N/F7)
DIN7: U9.27 (DIN7), U14.E7 (DIFFIO_RX_R14N/CLK2N/E7)
DIN8: U9.29 (DIN8), U14.E8 (DIFFIO_RX_R14P/CLK2P/E8)
DIN9: U9.30 (DIN9), U14.C8 (DIFFIO_RX_R27P/C8)
DIN10: U9.31 (DIN10), U14.C5 (CRC_ERROR/C5)
DIN11: U9.32 (DIN11), U14.C4 (DIFFIO_RX_T26P/C4)
E0: J8.2, U7.K2 (IN0)
E1: J8.68, U7.J1 (IN1)
E2: J8.3, U7.J2 (IN2)
E3: J8.67, U7.H1 (IN3)
E4: J8.4, U7.H2 (IN4)
E5: J8.66, U7.G1 (IN5)
E6: J8.5, U7.G2 (IN6)
E7: J8.65, U7.F1 (IN7)
E8: J8.6, U7.F2 (IN8)
E9: J8.64, U7.E1 (IN9)
E10: J8.7, U7.E2 (IN10)
E11: J8.63, U7.D1 (IN11)
E12: J8.8, U7.D2 (IN12)
E13: J8.62, U7.C1 (IN13)
E14: J8.9, U7.C2 (IN14)
E15: J8.61, U7.B1 (IN15)
E16: J8.10, U7.A1 (IN16)
E17: J8.60, U7.B2 (IN17)
E18: J8.11, U7.A2 (IN18)
E19: J8.59, U7.B3 (IN19)
E20: J8.12, U7.A3 (IN20)
E21: J8.58, U7.B4 (IN21)
E22: J8.13, U7.A4 (IN22)
E23: J8.57, U7.B5 (IN23)
E24: J8.14, U7.A5 (IN24)
E25: J8.56, U7.B6 (IN25)
E26: J8.15, U7.A6 (IN26)
E27: J8.55, U7.B7 (IN27)
E28: J8.16, U7.A7 (IN28)
E29: J8.54, U7.B8 (IN29)
E30: J8.17, U7.A8 (IN30)
E31: J8.53, U7.B9 (IN31)
E32: J8.18, U7.A9 (IN32)
E33: J8.52, U7.A10 (IN33)
E34: J8.19, U7.B10 (IN34)
E35: J8.51, U7.A11 (IN35)
E36: J8.20, U7.B11 (IN36)
E37: J8.50, U7.A12 (IN37)
E38: J8.21, U7.B12 (IN38)
E39: J8.49, U7.A13 (IN39)
E40: J8.22, U7.B13 (IN40)
E41: J8.48, U7.A14 (IN41)
E42: J8.23, U7.B14 (IN42)
E43: J8.47, U7.A15 (IN43)
E44: J8.24, U7.B15 (IN44)
E45: J8.46, U7.A16 (IN45)
E46: J8.25, U7.B16 (IN46)
E47: J8.45, U7.A17 (IN47)
E48: J8.26, U7.B17 (IN48)
E49: J8.44, U7.C16 (IN49)
E50: J8.27, U7.C17 (IN50)
E51: J8.43, U7.D16 (IN51)
E52: J8.28, U7.D17 (IN52)
E53: J8.42, U7.E16 (IN53)
E54: J8.29, U7.E17 (IN54)
E55: J8.41, U7.F16 (IN55)
E56: J8.30, U7.F17 (IN56)
E57: J8.40, U7.G16 (IN57)
E58: J8.31, U7.G17 (IN58)
E59: J8.39, U7.H16 (IN59)
E60: J8.32, U7.H17 (IN60)
E61: J8.38, U7.J16 (IN61)
E62: J8.33, U7.J17 (IN62)
E63: J8.37, U7.K16 (IN63)
ENV1: U6.C2 (E/CFGCLK), U14.B5 (DIFFIO_RX_T19N/B5)
ENV2: U8.C2 (E/CFGCLK), U14.C2 (DIFFIO_RX_L1N/C2)
ENV3: U11.C2 (E/CFGCLK), U14.D9 (DIFFIO_RX_R16N/CLK3N/D9)
ENV4: U12.C2 (E/CFGCLK), U14.B7 (DIFFIO_RX_R33N/PLL_R_CLKOUTN/B7)
ESTIM_POW_EN: R49.1, U14.A6 (DIFFIO_RX_T18P/DEV_OEA6), U16.8 (!SHDN2), U16.9 (!SHDN1)
GND: C1.2, C2.2, C3.2, C4.2, C5.2, C6.2, C7.2, C8.2, C9.2, C10.2, C11.2, C12.2, C13.2, C14.2, C15.2, C16.2, C17.2, C18.2, C19.2, C20.2, C21.2, C22.2, C23.2, C24.2, C27.2, C28.2, C31.2, C32.2, C33.1, C34.2, C35.2, C36.2, C39.2, C40.2, C41.2, C42.2, C43.2, C44.2, C45.2, C46.2, C47.2, C48.2, C49.2, C50.2, C51.2, C52.2, C53.2, C54.2, C55.2, C56.2, C58.2, C59.2, C60.2, C61.2, C62.2, C64.2, C65.2, C66.2, C67.2, C68.2, C69.2, C70.2, C71.2, C72.2, C73.2, J5.2, J5.4, L7.1, R19.1, R21.1, R23.2, R24.1, R25.1, R26.1, R30.2, R36.1, R42.1, R43.2, R46.1, R49.2, R57.2, TP3.TP, TP15.TP, U2.3 (GND), U2.PAD (GND), U3.1 (GND), U3.PAD (GND), U4.4 (GND), U4.8 (LA), U5.2 (X0), U5.13 (GND), U5.14 (B), U6.B2 (AVSS), U6.B3 (AVSS2), U8.B2 (AVSS), U8.B3 (AVSS2), U9.6 (ID), U9.7 (RES), U9.PAD (GND), U10.2 (GND), U10.5 (PS1), U10.6 (PS0), U10.15 (GNDIO), U10.16 (GNDIO), U10.17 (COM3/ADDR), U10.18 (COM2), U10.25 (GNDIO), U11.B2 (AVSS), U11.B3 (AVSS2), U12.B2 (AVSS), U12.B3 (AVSS2), U14.A1 (GND), U14.A9 (GND), U14.B4 (GND), U14.D1 (GND), U14.D7 (GND), U14.E5 (GND), U14.E9 (GND), U14.F4 (GND), U14.F6 (GND), U14.H1 (GND), U14.H5 (GND), U14.H9 (GND), U15.2 (GND), U15.PAD (GND), U16.PAD (GND), U17.2 (GND), U17.PAD (GND), U18.C2 (GND), U19.2 (GND), U20.2 (GND), U20.PAD (GND)
GND1: D2.A, J3.P$2 (2), J3.P$3 (2), J3.P$4 (2), J4.2, J4.4
GND2: D1.A, J1.P$2 (2), J1.P$3 (2), J1.P$4 (2), J2.2, J2.4
GND3: D3.A, J6.P$2 (2), J6.P$3 (2), J6.P$4 (2), J7.2, J7.4
GPIO0: J9.3 (4), TP4.TP, U9.15 (GPIO0), U14.A3
GPIO1: U9.16 (GPIO1), U14.H6 (DIFFIO_TX_RX_B12N/H6)
HSYNC: U9.1 (HSYNC), U14.F2 (DIFFIO_RX_L18P/CLK0P/F2)
IMU_INT: U10.14 (INT)
IMU_SCL: R41.1, U10.19 (COM1/SCL/RX), U14.E3
IMU_SDA: R51.1, U10.20 (COM0/SDA/TX), U14.F9 (DIFFIO_RX_R10N/F9)
ISTIM: J8.1, U5.6 (X), U5.10 (Y1)
ISTIM_MONO: R14.1, R19.2, U7.N5 (AUXIN3)
ISTIM_PRE: R12.1, U1.9 (+IN), U5.7 (Y)
JTAGEN: R38.2, U14.D2 (JTAGEN/D2)
LED-1: J8.34, U3.5 (LED1), U3.6 (LED2), U3.7 (LED3), U3.8 (LED4), U3.9 (LED5), U3.10 (LED6), U3.11 (LED7), U3.12 (LED8)
LED-2: J8.35, U3.13 (LED9), U3.14 (LED10), U3.15 (LED11), U3.16 (LED12), U3.17 (LED13), U3.18 (LED14), U3.19 (LED15), U3.20 (LED16)
LED_BLANK: R53.2, U3.21 (BLANK), U14.C9 (DIFFIO_RX_R27N/C9)
LED_LATCH: U3.4 (LATCH), U14.J8 (DIFFIO_TX_RX_B16P/J8)
MIDFILT: J5.1, L4.1, R10.1
MOSI: U2.6 (DIN), U3.2 (SIN), U4.2 (DIN), U14.A4 (DIFFIO_RX_T19P/A4)
unnamed: R15.2, U4.6 (WA)
unnamed: C63.1, L11.1, U16.4 (SW2)
unnamed: C57.1, R48.1, R50.2, U16.6 (FB2)
unnamed: D4.C, U6.A3 (IIN-)
unnamed: D4.A, U6.A2 (IIN+)
unnamed: R24.2, U6.B1 (RBIAS)
unnamed: C19.1, U6.A1 (AVDD)
unnamed: L9.1, U16.2 (SW1)
unnamed: D5.C, U8.A3 (IIN-)
unnamed: D5.A, U8.A2 (IIN+)
unnamed: R26.2, U8.B1 (RBIAS)
unnamed: C28.1, U8.A1 (AVDD)
unnamed: C6.1, C7.1, L2.1, L4.2, R10.2
unnamed: R15.1, U3.23 (RSET)
unnamed: D6.C, U11.A3 (IIN-)
unnamed: D6.A, U11.A2 (IIN+)
unnamed: R36.2, U11.B1 (RBIAS)
unnamed: C34.1, U11.A1 (AVDD)
unnamed: C63.2, D9.C, U16.5 (D2)
unnamed: R1.2, R2.2, R12.2, U1.4 (+IN)
unnamed: R21.2, U5.11 (Y0)
unnamed: R45.1, R46.2, U16.10 (FB1)
unnamed: J4.1, L3.2, R9.2
unnamed: D8.C, TP7.TP, U12.A3 (IIN-)
unnamed: R48.2, U16.7 (VREF)
unnamed: C25.2, U9.13 (DOUT+)
unnamed: D7.2 (A), R37.2
unnamed: R33.2, U9.9 (PDB)
unnamed: C26.2, U9.12 (DOUT-)
unnamed: C26.1, R25.2
unnamed: R27.2, R30.1, U9.8 (MODE)
unnamed: C10.1, C11.1, C12.1, L6.2, U9.10 (VDDPLL)
unnamed: C22.1, C23.1, C24.1, L8.2, U9.14 (VDDCML)
unnamed: C29.1, U7.N17 (ADC_REF)
unnamed: U14.D8 (DIFFIO_RX_R16P/CLK3P/D8), U19.3 (OUT)
unnamed: D8.A, TP8.TP, U12.A2 (IIN+)
unnamed: TP2.TP, U7.N16 (AUXOUT)
unnamed: R42.2, U12.B1 (RBIAS)
unnamed: C36.1, U12.A1 (AVDD)
unnamed: R22.2, U5.16 (EN)
unnamed: R54.2, U14.D6 (NCONFIG/D6)
unnamed: L12.2, U18.B1 (SW)
unnamed: J2.1, L1.2, R3.2
unnamed: J7.1, L5.2, R20.2
unnamed: R1.1, R4.2, U1.2 (+IN)
unnamed: R5.2, R11.1, U1.1 (-IN)
unnamed: R2.1, R11.2, U1.15 (OUT)
unnamed: R16.1, R17.2, U1.6 (OUT)
unnamed: R13.1, R16.2, U1.5 (-IN)
unnamed: R8.1, R13.2, U1.8 (-IN)
unnamed: R6.2, R8.2, U1.7 (OUT)
unnamed: R7.1, R14.2, U1.14 (OUT)
unnamed: R6.1, R7.2, U1.12 (-IN)
unnamed: R17.1, R18.2, U1.11 (+IN)
unnamed: C33.2, U10.9 (CAP)
NSTATUS: R55.2, U14.B3 (DIFFIO_RX_T24P/NSTATUS/B3)
PCLK: U9.3 (PCLK1), U14.G2 (DIFFIO_RX_L20N/CLK1N/G2)
POT_CS: U4.3 (!CS), U14.G7 (DIFFIO_RX_R1P/G7)
REF: J8.69, R29.2, U7.M1 (REF_ELEC)
RHD_CLK_N: R34.1, U7.N9 (SCLK-), U14.G5 (DIFFIO_TX_RX_B3P/G5)
RHD_CLK_P: R34.2, U7.N10 (SCLK+), U14.G4 (DIFFIO_TX_RX_B3N/G4)
RHD_CS_N: R31.1, U7.N7 (!CS!-), U14.J2 (DIFFIO_TX_RX_B1P/J2)
RHD_CS_P: R31.2, U7.N8 (!CS!+), U14.H3 (DIFFIO_TX_RX_B1N/H3)
RHD_MISO_N: R47.1, U7.N13 (MISO-), U14.J5 (DIFFIO_TX_RX_B9P/J5)
RHD_MISO_P: R47.2, U7.N14 (MISO+), U14.J4 (DIFFIO_TX_RX_B9N/J4)
RHD_MOSI_N: R35.1, U7.N11 (MOSI-), U14.H4 (DIFFIO_TX_RX_B5P/H4)
RHD_MOSI_P: R35.2, U7.N12 (MOSI+), U14.J3 (DIFFIO_TX_RX_B5N/J3)
SCL: R44.2, U9.4 (SCL), U14.G3 (DIFFIO_RX_L27P/G3)
SCLK: U2.4 (SCLK), U3.3 (CLK), U4.5 (SCLK), U14.F3 (DIFFIO_RX_L27N/F3)
SDA: R52.2, U9.5 (SDA), U14.F8 (DIFFIO_RX_R10P/F8)
SIGOUT: C25.1, J5.3
STATUS: D7.1 (C), U14.C1 (DIFFIO_RX_L1P/C1)
STIM_NULL: R23.1, U5.15 (A), U14.F1 (DIFFIO_RX_L18N/CLK0N/F1)
TCK: R43.1, TP11.TP, U14.D4 (DIFFIO_RX_L11P/TCK/D4)
TDI: R40.2, TP12.TP, U14.E1 (DIFFIO_RX_L12N/TDI/E1)
TDO: TP13.TP, U14.E2 (DIFFIO_RX_L12P/TDO/E2)
TMS: R39.2, TP10.TP, U14.D3 (DIFFIO_RX_L11N/TMS/D3)
VCOAX: C2.1, C37.1, C39.1, C41.1, C55.1, C69.1, J8.36, J8.M3, L2.2, L9.2, L11.2, TP9.TP, U2.1 (AVDD), U3.24 (VDD), U13.3 (EN), U13.4 (IN), U15.3 (EN), U15.4 (IN), U16.3 (VIN), U17.3 (EN), U17.4 (IN), U18.A1 (MODE), U18.A2 (VIN), U18.B2 (EN)
VDAC: R4.1, U2.8 (VOUT)
VREF_2V5: R5.1, R18.1, U2.7 (VREF)
VSYNC: U9.2 (VSYNC), U14.G1 (DIFFIO_RX_L20P/CLK1P/G1)
_SIGOUT: D2.C, J3.P$1 (1), J4.3, L3.1, R9.1
_SIGOUT1: D1.C, J1.P$1 (1), J2.3, L1.1, R3.1
_SIGOUT2: D3.C, J6.P$1 (1), J7.3, L5.1, R20.1

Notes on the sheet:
NB: Inductors pass 250mA DC max before they are used to generate a flyback voltage. Because we are dealing with a very low current application, we can probably get away with inductors that saturate below 250 mA so long as they are capable of handling the current. The MLZ2012M100WT000 saturates at 2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
NB: VCoax must NOT exceed 5.5V
Programming interface
INPUT
ESTIM
OPTOSTIM
SERIALIZER
FPGA
ADC
TRACKING
POWER
NB: Because we are suing a 3.3V IO voltage for bank 3, the LVDS produced here is technically out of spec. The lines sit at 1.6V and swing about 600 mV. This is a result of using 3.3V supply on an FPGA that nominally requires a 2.5 rail to get LVDS to its standard 1.2V common mode voltage with 400 m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
DNP
NB: CLK3 drives PLL2
NB: IO daughter boards. Multiple allows them to be replaced if coax connector gets worn out.
NB: ISTIM = (VDAC - 2.5)/1000. e.g. VDAC = 2.5 -> ISTIM = 0 VDAC = 5.0 -> ISTIM = 2.5 mA VDAC = 0.0 -> ISTIM = -2.5mA and Imeas = 400 * ISTIM + 1.25V e.g. ISTIM = 0 -> IMEAS = 1.25V ISTIM = 2.5mA -> IMEAS = 2.25V ISTIM = -2.5mA -> IMEAS = 0.25V
I2C Selected
NB To get the best performance out of BNO055, it is recommended to use the external 32.768 kHz crystal.
NB: Decoupling relies on input caps for the LDO regulators.

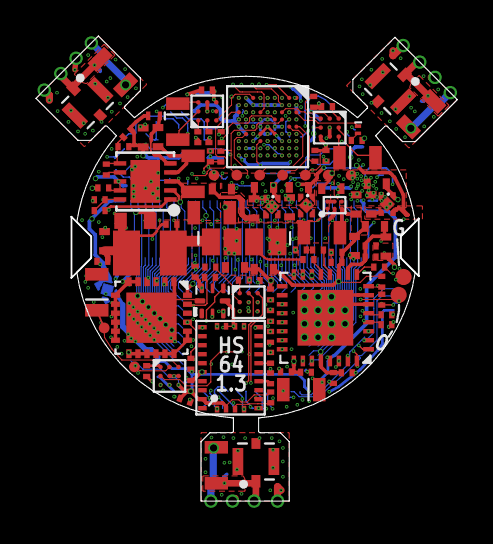
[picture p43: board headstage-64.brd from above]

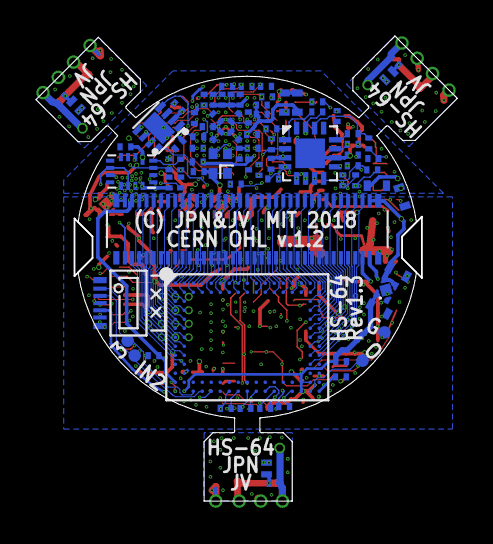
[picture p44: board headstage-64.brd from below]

Board: 8 copper layers, 23.4 x 25.8 mm, 195 parts (82 on the bottom side), 204 nets.

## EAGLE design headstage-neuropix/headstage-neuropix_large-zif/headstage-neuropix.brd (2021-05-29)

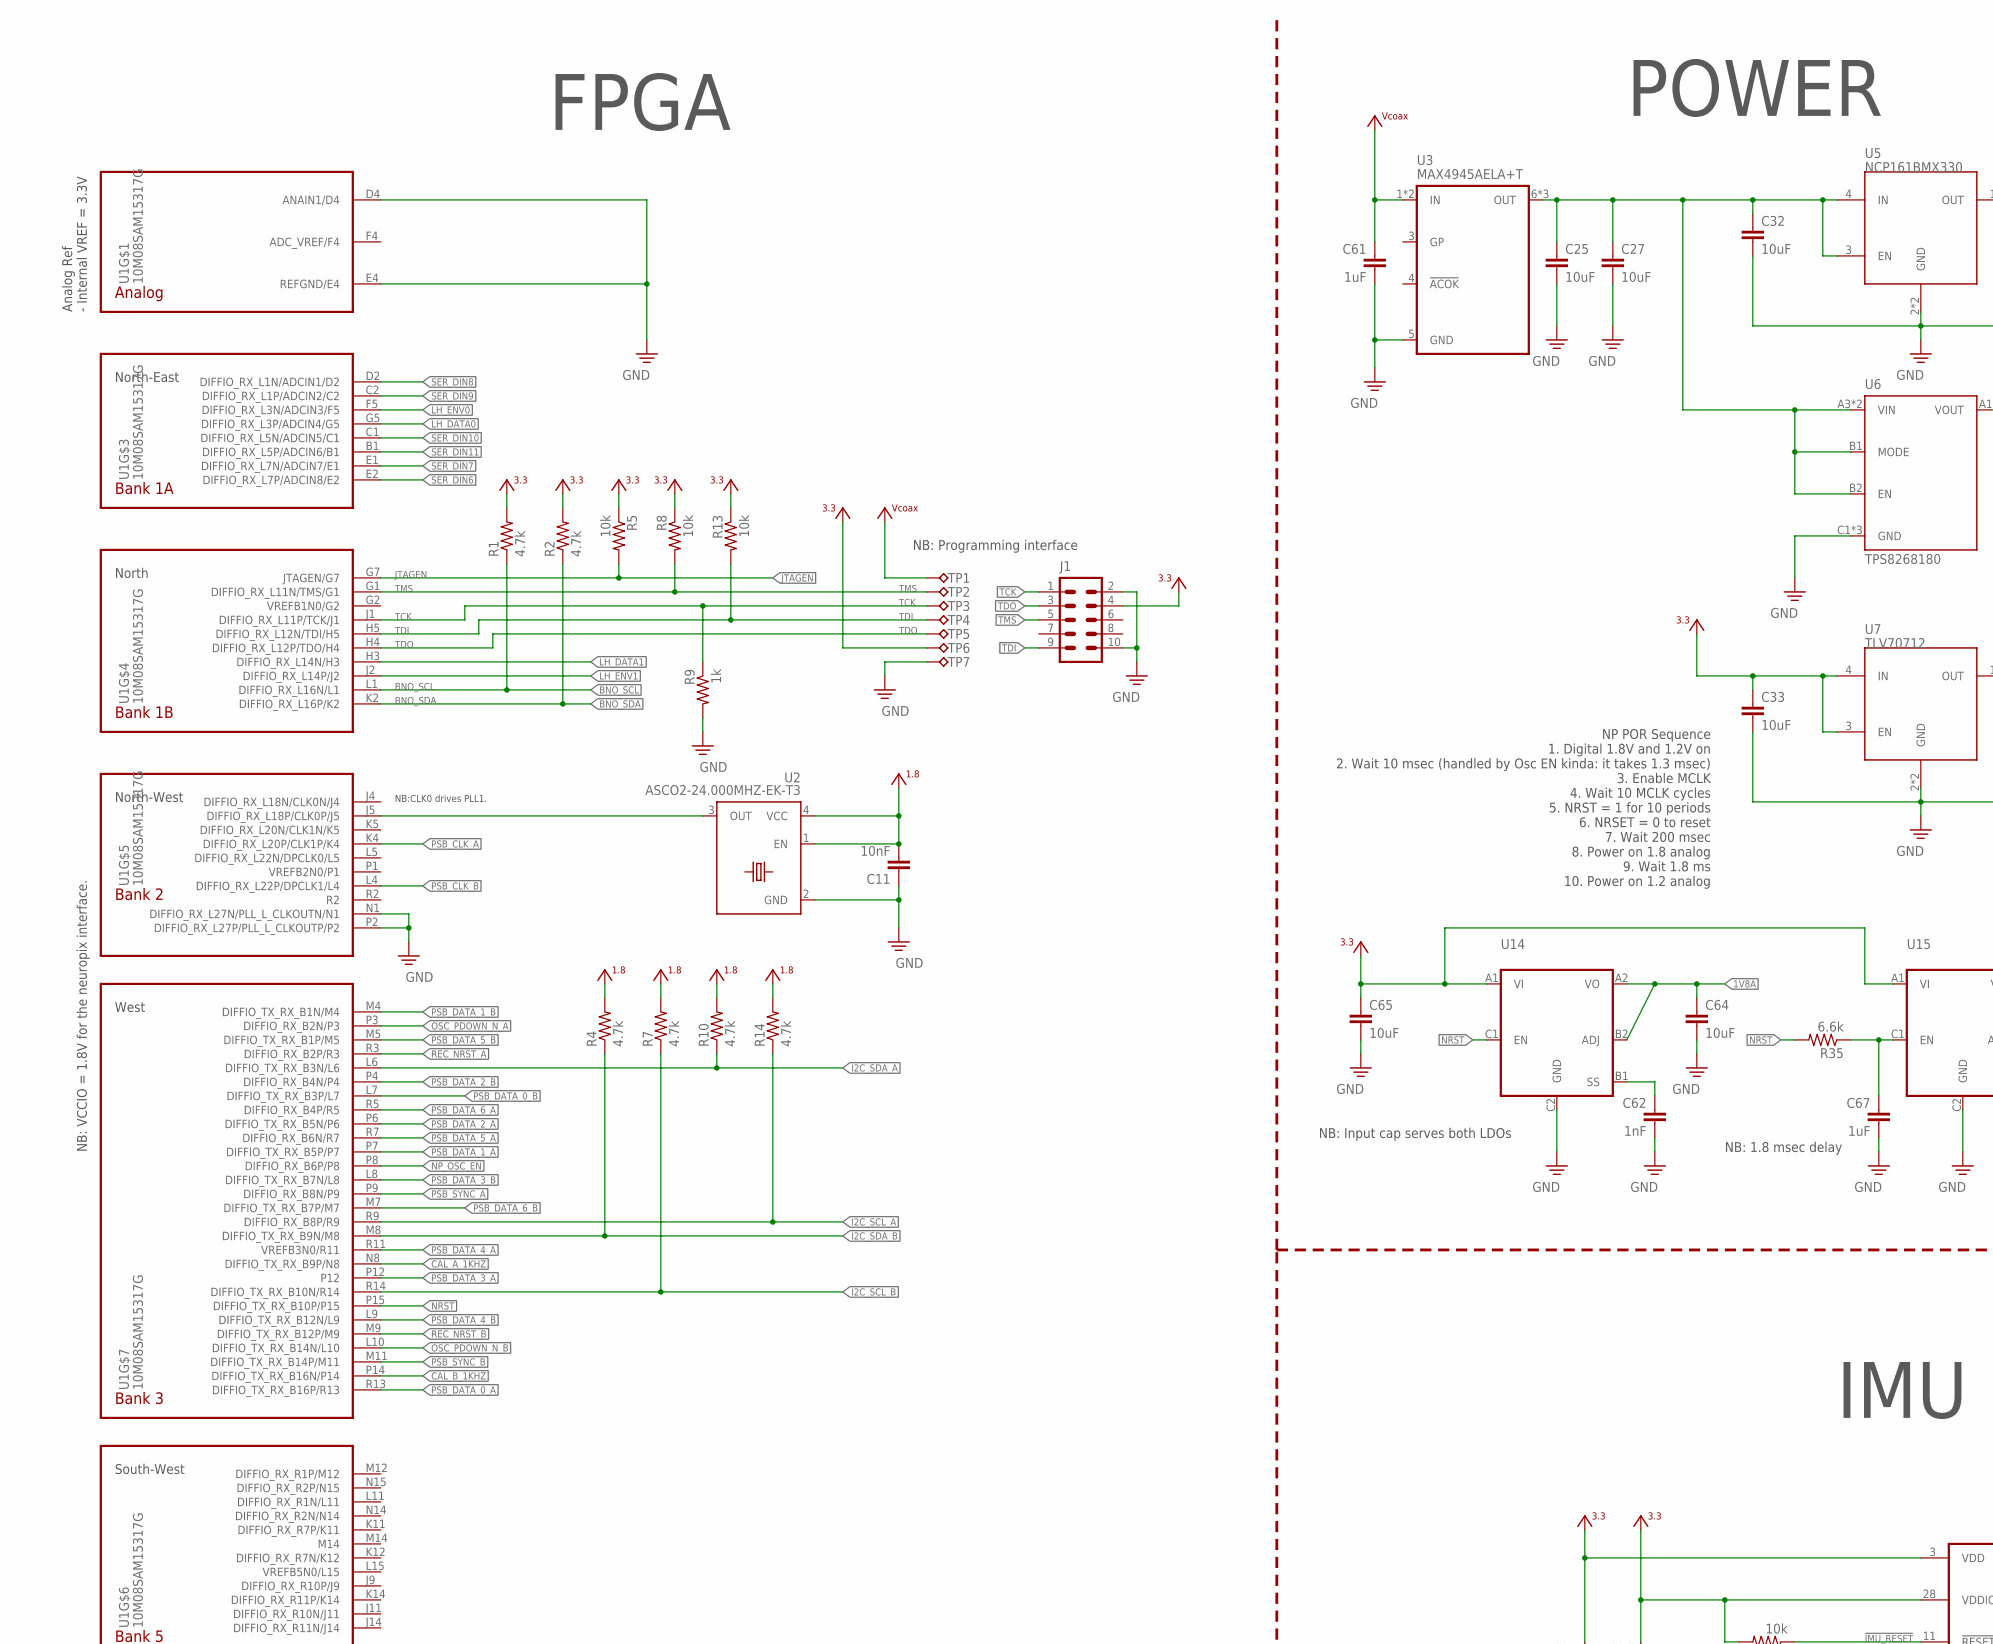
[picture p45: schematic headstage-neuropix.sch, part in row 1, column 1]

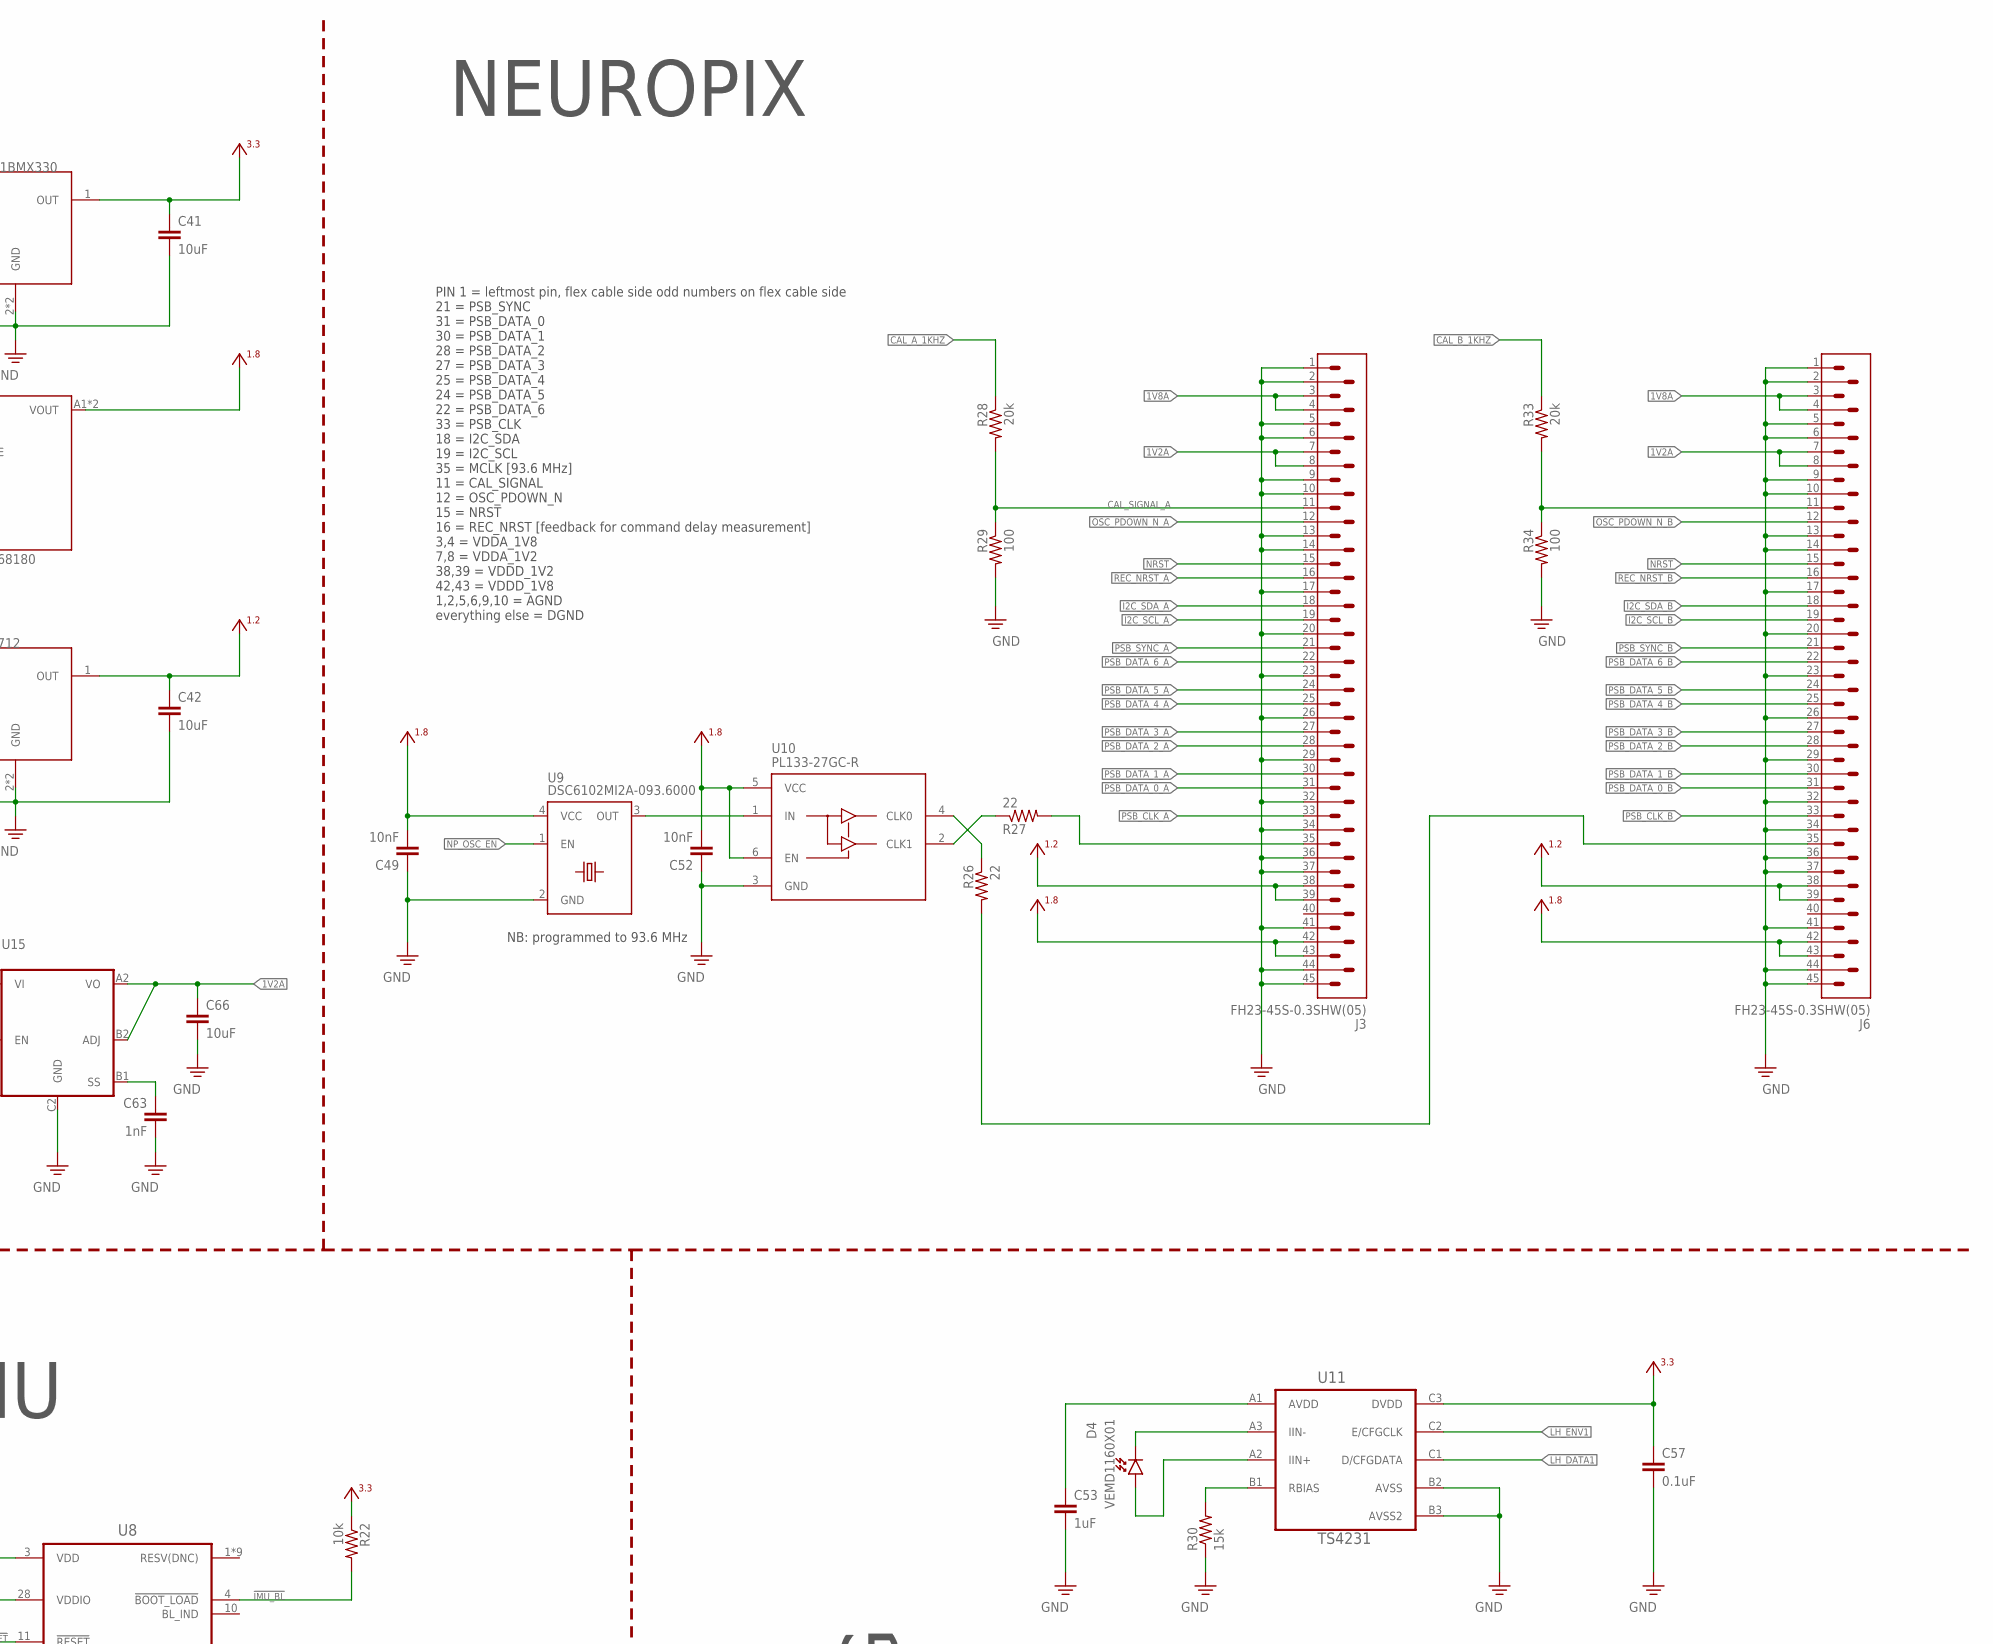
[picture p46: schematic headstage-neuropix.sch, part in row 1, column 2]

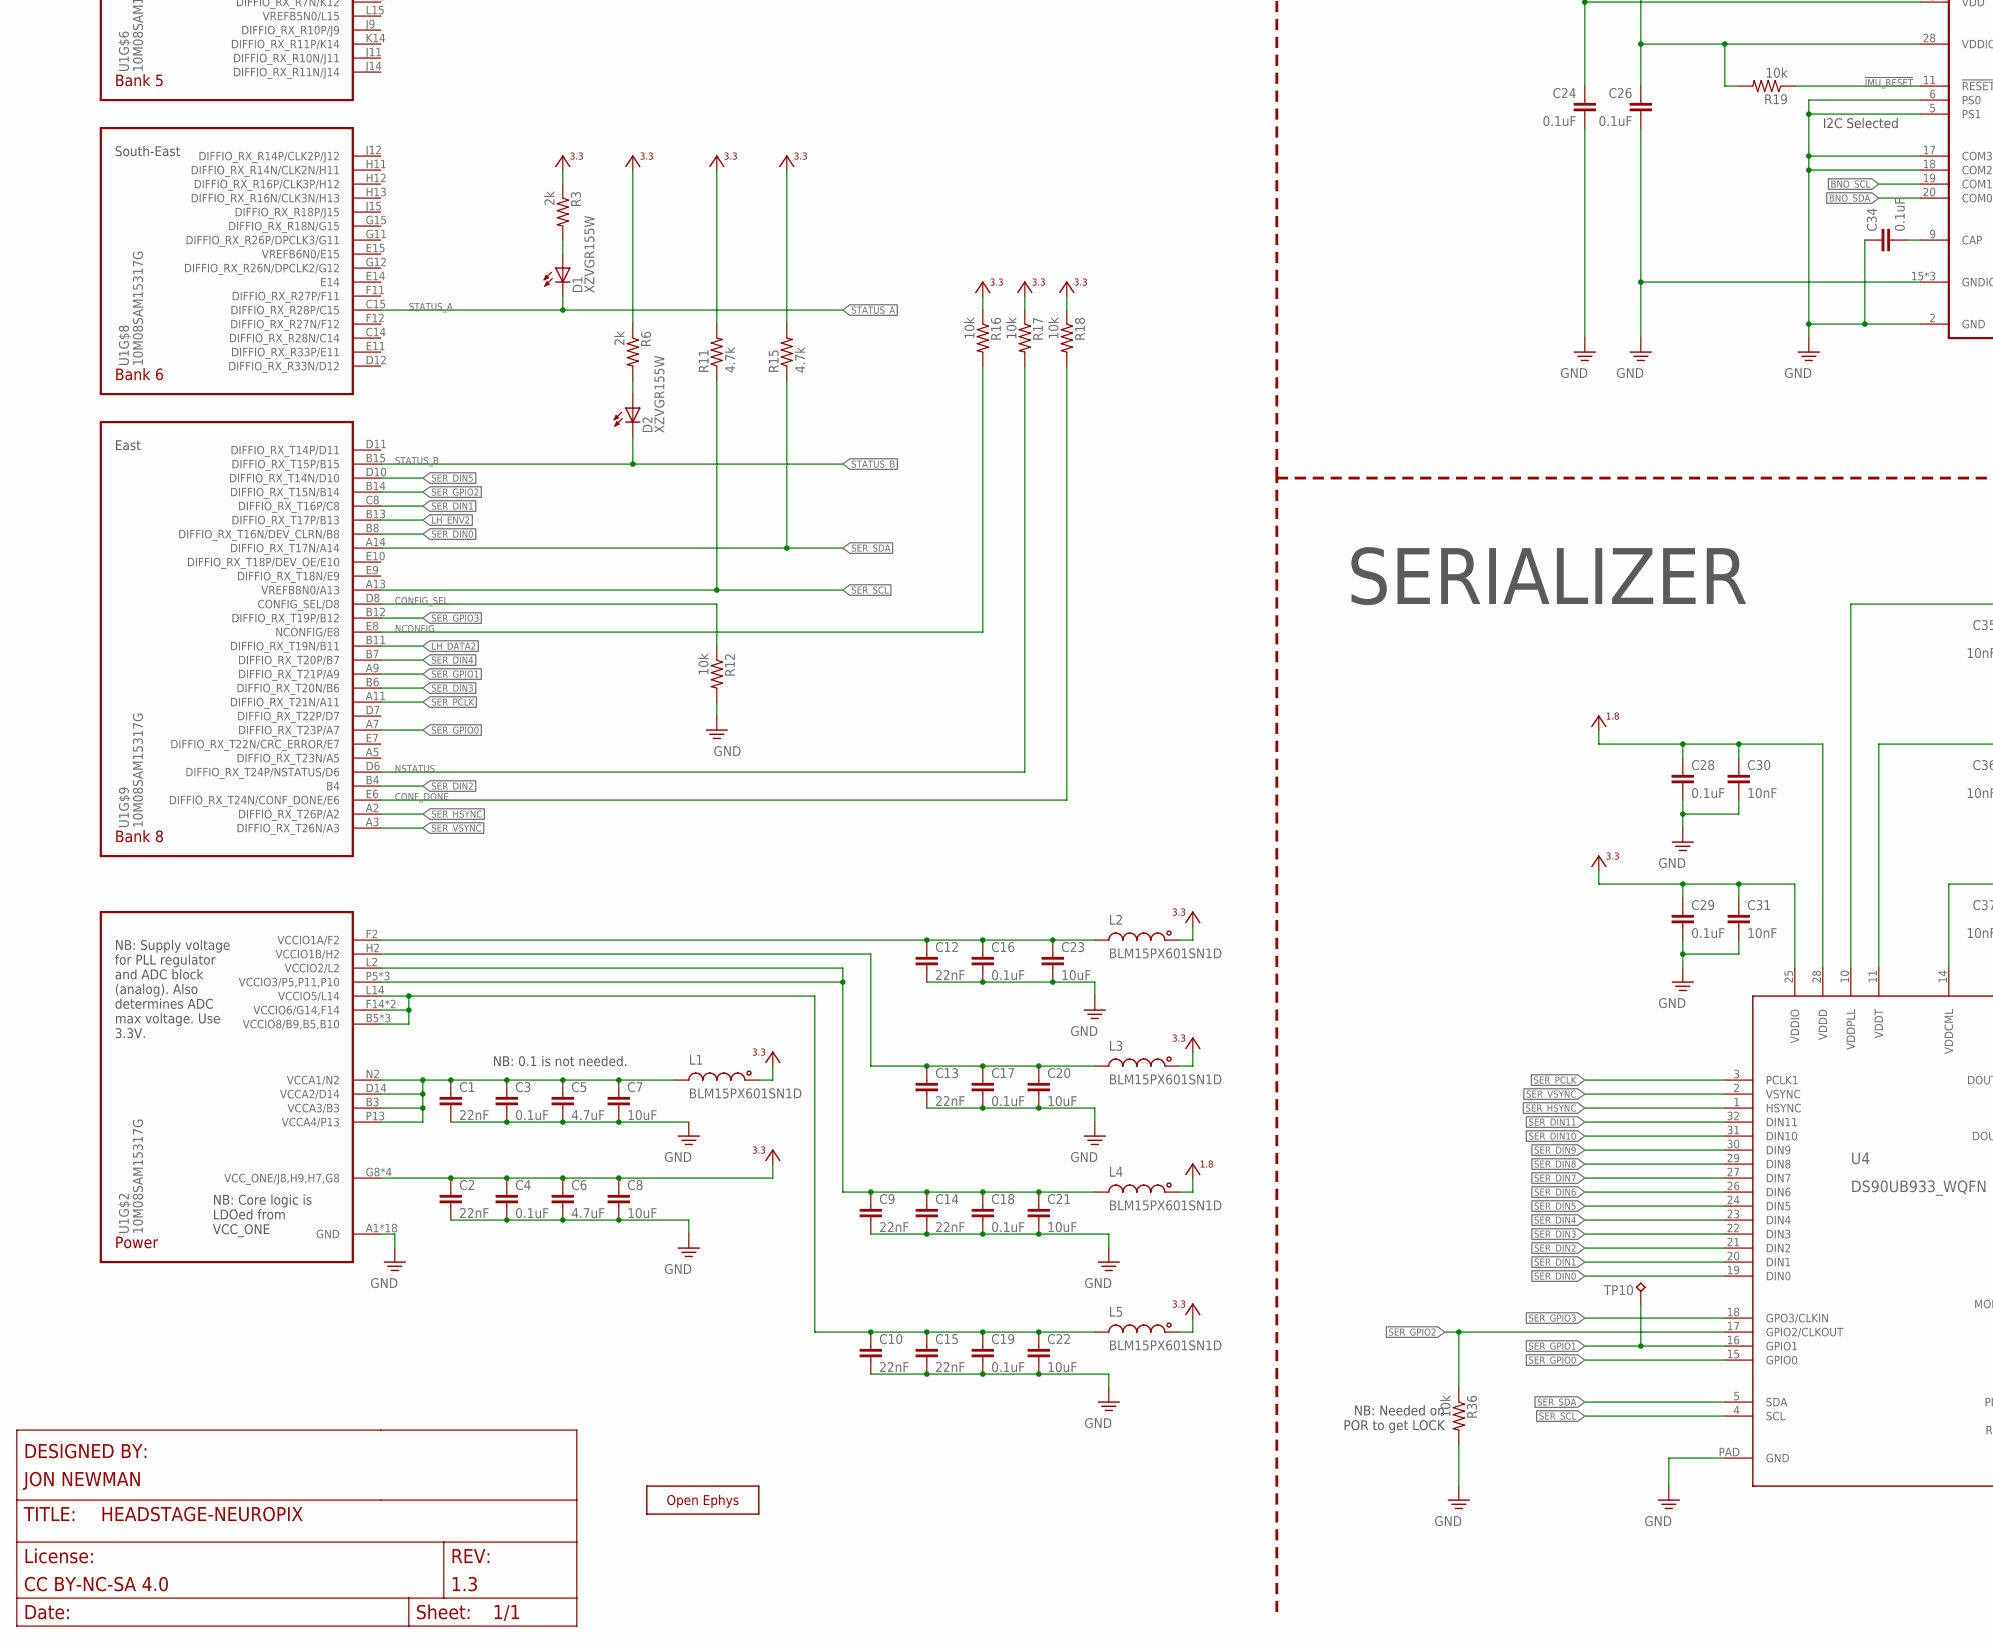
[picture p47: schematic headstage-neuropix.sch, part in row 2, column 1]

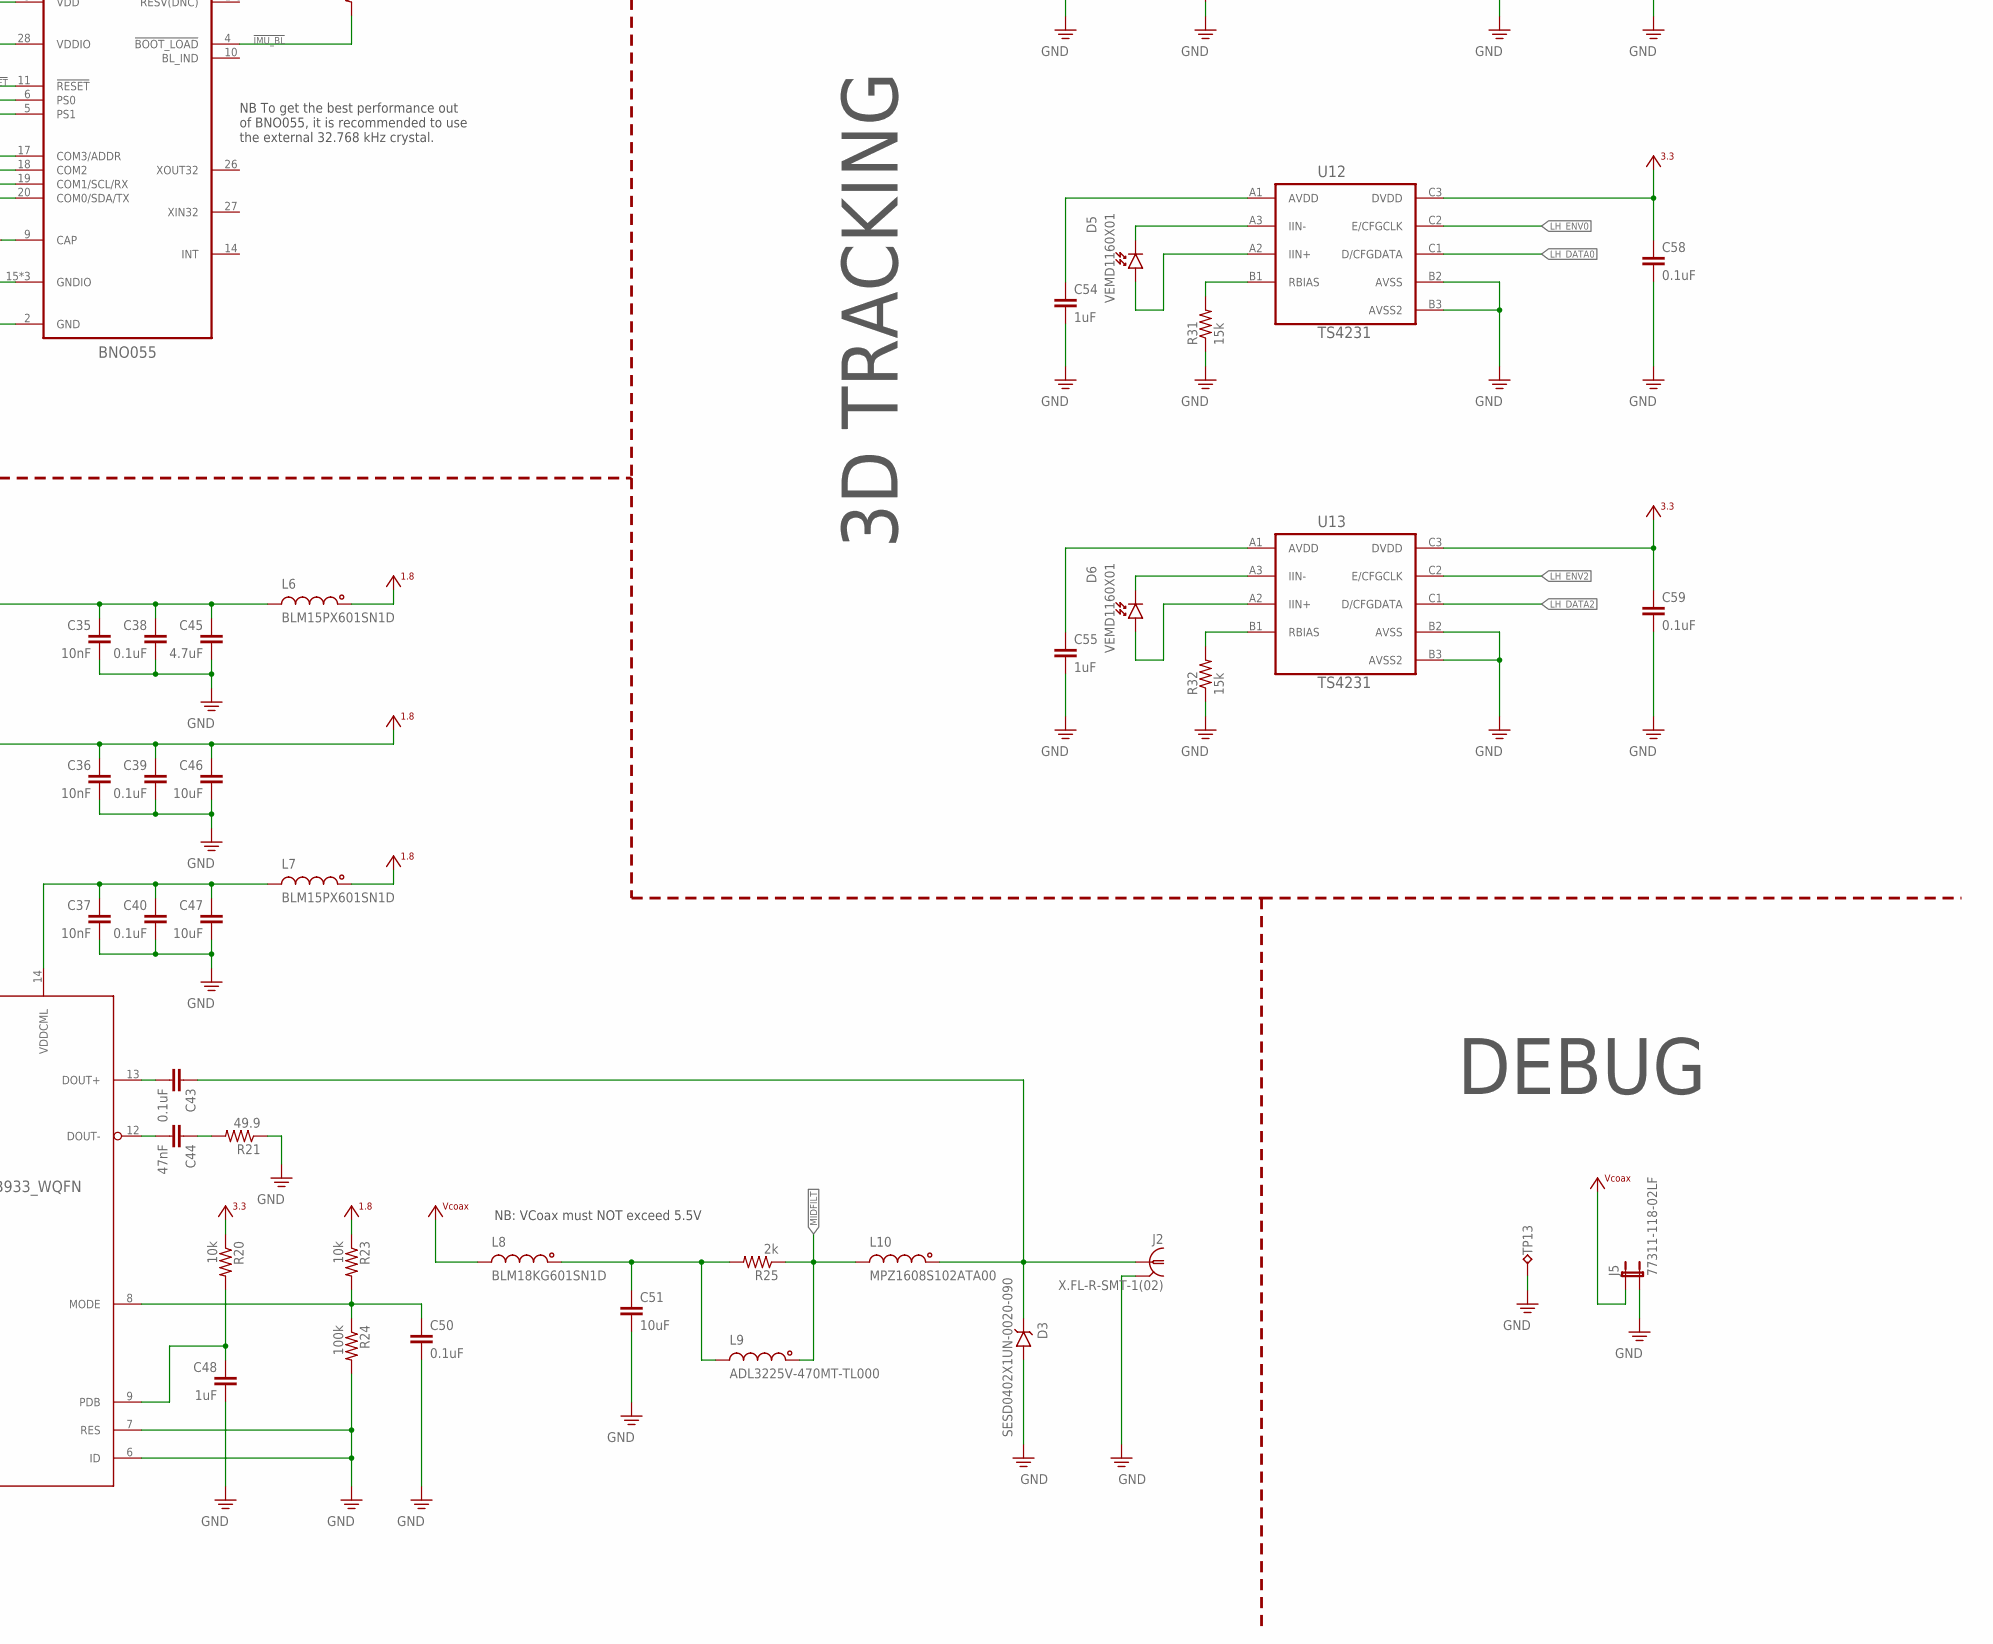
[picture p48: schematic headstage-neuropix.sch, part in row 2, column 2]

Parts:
C1, C2, C9, C10, C12, C13, C14, C15: 22nF; 0201T
C3, C4, C16, C17, C18, C19, C24, C26, C28, C29, C34, C38, C39, C40, C43, C50: 0.1uF; 0201T
C5, C6, C45: 4.7uF; 0402T
C7, C8, C20, C21, C22, C23, C46, C51: 10uF; 0402T
C11, C30, C31, C35, C36, C37, C49, C52: 10nF; 0201T
C25, C27, C32, C33, C41, C42, C47, C64, C65, C66: 10uF; 0402TW
C44: 47nF; 0201T
C48, C61, C67: 1uF; 0201T
C53, C54, C55: 1uF; 0201T; PARTNO CL03A105MP3ZSNH
C57, C58, C59: 0.1uF; 0201T; PARTNO C0603X5R1C104K030BC
C62, C63: 1nF; 0201T
D1, D2: XZVGR155W; LED-0201T
D3: SESD0402X1UN-0020-090; 0402T-DFN
D4, D5, D6: VEMD1160X01; 0805PT-NOSILK
J1: 302-S101; 2X05_IDC
J2: X.FL-R-SMT-1(02); X_FL_R_SMT_1(02)
J3, J6: FH23-45S-0.3SHW(05)
J5: 77311-118-02LF; JP2
L1, L2, L3, L4, L5, L6, L7: BLM15PX601SN1D; 0402T
L8: BLM18KG601SN1D; 0603T
L9: ADL3225V-470MT-TL000; 1210T
L10: MPZ1608S102ATA00; 0603T
R1, R2, R4, R7, R10, R11, R14, R15: 4.7k; 0201T
R3, R6, R25: 2k; 0201T
R5, R8, R12, R13, R16, R17, R18, R19, R20, R22, R23, R36: 10k; 0201T
R9: 1k; 0201T
R21: 49.9; 0201T
R24: 100k; 0201T
R26, R27: 22; 0201T
R28, R33: 20k; 0201T
R29, R34: 100; 0201T
R30, R31, R32: 15k; 0201T
R35: 6.6k; 0201T
TP1, TP2, TP3, TP4, TP5, TP6, TP7: TPTP10R; TP10R
TP10: TPTP09R; TP09R
TP13: TPTP20R; TP20R
U1: 10M08SAM15317G; MBGA153-8X8
U2: ASCO2-24.000MHZ-EK-T3; ASCO
U3: MAX4945AELA+T; UDFN8-2X2
U4: DS90UB933_WQFN; WQFN32-5X5
U5: NCP161BMX330; X2SON
U6: TPS8268180; MICROSIP9-3X2.3
U7: TLV70712; X2SON
U8: BNO055; LGA-28-3.8X5.2
U9: DSC6102MI2A-093.6000; VFLGA4-2.0X1.6
U10: PL133-27GC-R; DFN6_2X1.3_PAD
U11, U12, U13: TS4231; WLCSP3X3
U14, U15: LDO_ADJUST-EN-SS_WLCSP-ADP7112; WLCSP6-1X1.2
X2: OE-LOGO_14X10; OE-LOGO-14X10

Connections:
1V2A: C66.1, J3.7, J3.8, J6.7, J6.8, U15.A2 (VO), U15.B2 (ADJ)
1V8A: C64.1, J3.3, J3.4, J6.3, J6.4, U14.A2 (VO), U14.B2 (ADJ)
24MHZ_P: U1.J5 (DIFFIO_RX_L18P/CLK0P/J5), U2.3 (OUT)
!IMU_BL: R22.2, U8.4 (!BOOT_LOAD)
!IMU_RESET: R19.1, U8.11 (!RESET)
+1V2: C42.1, J3.38, J3.39, J6.38, J6.39, U7.1 (OUT)
+1V8: C11.2, C28.1, C30.1, C36.1, C39.1, C46.1, C49.2, C52.2, J3.42, J3.43, J6.42, J6.43, L4.1, L6.1, L7.1, R4.2, R7.2, R10.2, R14.2, R23.1, U2.1 (EN), U2.4 (VCC), U4.11 (VDDT), U4.28 (VDDD), U6.A1 (VOUT), U6.A2 (VOUT), U9.4 (VCC), U10.5 (VCC), U10.6 (EN)
+3V3: C2.1, C4.1, C6.1, C8.1, C24.1, C26.1, C29.1, C31.1, C33.1, C41.1, C57.1, C58.1, C59.1, C65.1, J1.4, L1.1, L2.1, L3.1, L5.1, R1.2, R2.2, R3.1, R5.1, R6.1, R8.1, R11.2, R13.1, R15.2, R16.1, R17.1, R18.1, R19.2, R20.1, R22.1, TP6.TP, U1.G8 (VCC_ONE/J8,H9,H7,G8), U1.H7 (VCC_ONE/J8,H9,H7,G8), U1.H9 (VCC_ONE/J8,H9,H7,G8), U1.J8 (VCC_ONE/J8,H9,H7,G8), U4.25 (VDDIO), U5.1 (OUT), U7.3 (EN), U7.4 (IN), U8.3 (VDD), U8.28 (VDDIO), U11.C3 (DVDD), U12.C3 (DVDD), U13.C3 (DVDD), U14.A1 (VI), U15.A1 (VI)
BNO_SCL: R1.1, U1.L1 (DIFFIO_RX_L16N/L1), U8.19 (COM1/SCL/RX)
BNO_SDA: R2.1, U1.K2 (DIFFIO_RX_L16P/K2), U8.20 (COM0/SDA/TX)
CAL_A_1KHZ: R28.1, U1.N8 (DIFFIO_TX_RX_B9P/N8)
CAL_B_1KHZ: R33.1, U1.P14 (DIFFIO_TX_RX_B16N/P14)
CAL_SIGNAL_A: J3.11, R28.2, R29.1
CAL_SIGNAL_A1: J6.11, R33.2, R34.1
CONFIG_SEL: R12.1, U1.D8 (CONFIG_SEL/D8)
CONF_DONE: R18.2, U1.E6 (DIFFIO_RX_T24N/CONF_DONE/E6)
GND: C1.2, C2.2, C3.2, C4.2, C5.2, C6.2, C7.2, C8.2, C9.2, C10.2, C11.1, C12.2, C13.2, C14.2, C15.2, C16.2, C17.2, C18.2, C19.2, C20.2, C21.2, C22.2, C23.2, C24.2, C25.2, C26.2, C27.2, C28.2, C29.2, C30.2, C31.2, C32.2, C33.2, C34.1, C35.2, C36.2, C37.2, C38.2, C39.2, C40.2, C41.2, C42.2, C45.2, C46.2, C47.2, C48.2, C49.1, C50.2, C51.2, C52.1, C53.2, C54.2, C55.2, C57.2, C58.2, C59.2, C61.2, C62.2, C63.2, C64.2, C65.2, C66.2, C67.2, D3.A, J1.2, J1.10, J2.P$2 (2), J2.P$3 (2), J2.P$4 (2), J3.1, J3.2, J3.5, J3.6, J3.9, J3.10, J3.13, J3.14, J3.17, J3.20, J3.23, J3.26, J3.29, J3.32, J3.34, J3.36, J3.37, J3.41, J3.44, J3.45, J5.2, J6.1, J6.2, J6.5, J6.6, J6.9, J6.10, J6.13, J6.14, J6.17, J6.20, J6.23, J6.26, J6.29, J6.32, J6.34, J6.36, J6.37, J6.41, J6.44, J6.45, R9.2, R12.2, R21.1, R24.2, R29.2, R30.1, R31.1, R32.1, R34.2, R36.2, TP7.TP, TP13.TP, U1.A1 (GND), U1.A15 (GND), U1.B2 (GND), U1.D4 (ANAIN1/D4), U1.D5 (GND), U1.D9 (GND), U1.E4 (REFGND/E4), U1.E5 (GND), U1.E12 (GND), U1.G4 (GND), U1.G9 (GND), U1.H8 (GND), U1.H14 (GND), U1.J7 (GND), U1.L12 (GND), U1.M2 (GND), U1.M6 (GND), U1.M10 (GND), U1.N1 (DIFFIO_RX_L27N/PLL_L_CLKOUTN/N1), U1.P2 (DIFFIO_RX_L27P/PLL_L_CLKOUTP/P2), U1.R1 (GND), U1.R15 (GND), U2.2 (GND), U3.5 (GND), U4.6 (ID), U4.7 (RES), U4.PAD (GND), U5.2 (GND), U5.PAD (GND), U6.C1 (GND), U6.C2 (GND), U6.C3 (GND), U7.2 (GND), U7.PAD (GND), U8.2 (GND), U8.5 (PS1), U8.6 (PS0), U8.15 (GNDIO), U8.16 (GNDIO), U8.17 (COM3/ADDR), U8.18 (COM2), U8.25 (GNDIO), U9.2 (GND), U10.3 (GND), U11.B2 (AVSS), U11.B3 (AVSS2), U12.B2 (AVSS), U12.B3 (AVSS2), U13.B2 (AVSS), U13.B3 (AVSS2), U14.C2 (GND), U15.C2 (GND)
I2C_SCL_A: J3.19, R14.1, U1.R9 (DIFFIO_RX_B8P/R9)
I2C_SCL_B: J6.19, R7.1, U1.R14 (DIFFIO_TX_RX_B10N/R14)
I2C_SDA_A: J3.18, R10.1, U1.L6 (DIFFIO_TX_RX_B3N/L6)
I2C_SDA_B: J6.18, R4.1, U1.M8 (DIFFIO_TX_RX_B9N/M8)
JTAGEN: R5.2, U1.G7 (JTAGEN/G7)
LH_DATA0: U1.G5 (DIFFIO_RX_L3P/ADCIN4/G5), U12.C1 (D/CFGDATA)
LH_DATA1: U1.H3 (DIFFIO_RX_L14N/H3), U11.C1 (D/CFGDATA)
LH_DATA2: U1.B11 (DIFFIO_RX_T19N/B11), U13.C1 (D/CFGDATA)
LH_ENV0: U1.F5 (DIFFIO_RX_L3N/ADCIN3/F5), U12.C2 (E/CFGCLK)
LH_ENV1: U1.J2 (DIFFIO_RX_L14P/J2), U11.C2 (E/CFGCLK)
LH_ENV2: U1.B13 (DIFFIO_RX_T17P/B13), U13.C2 (E/CFGCLK)
MIDFILT: L9.1, L10.2, R25.1
unnamed: U9.3 (OUT), U10.1 (IN)
unnamed: R26.1, U10.4 (CLK0)
unnamed: J3.35, R27.2
unnamed: C13.1, C17.1, C20.1, L3.2, U1.H2 (VCCIO1B/H2)
unnamed: J6.35, R26.2
unnamed: R27.1, U10.2 (CLK1)
unnamed: D4.C, U11.A3 (IIN-)
unnamed: D4.A, U11.A2 (IIN+)
unnamed: R30.2, U11.B1 (RBIAS)
unnamed: C53.1, U11.A1 (AVDD)
unnamed: C51.1, L8.1, L9.2, R25.2
unnamed: D5.C, U12.A3 (IIN-)
unnamed: D5.A, U12.A2 (IIN+)
unnamed: R31.2, U12.B1 (RBIAS)
unnamed: D6.C, U13.A3 (IIN-)
unnamed: D6.A, U13.A2 (IIN+)
unnamed: C43.2, U4.13 (DOUT+)
unnamed: R32.2, U13.B1 (RBIAS)
unnamed: C48.1, R20.2, U4.9 (PDB)
unnamed: C44.2, U4.12 (DOUT-)
unnamed: C44.1, R21.2
unnamed: C50.1, R23.2, R24.1, U4.8 (MODE)
unnamed: C35.1, C38.1, C45.1, L6.2, U4.10 (VDDPLL)
unnamed: C37.1, C40.1, C47.1, L7.2, U4.14 (VDDCML)
unnamed: C54.1, U12.A1 (AVDD)
unnamed: C55.1, U13.A1 (AVDD)
unnamed: C25.1, C27.1, C32.1, U3.6 (OUT), U3.7 (OUT), U3.8 (OUT), U5.3 (EN), U5.4 (IN), U6.A3 (VIN), U6.B1 (MODE), U6.B2 (EN), U6.B3 (VIN)
unnamed: C62.1, U14.B1 (SS)
unnamed: C63.1, U15.B1 (SS)
unnamed: C67.1, R35.1, U15.C1 (EN)
unnamed: C34.2, U8.9 (CAP)
unnamed: D2.2 (A), R6.2
unnamed: D1.2 (A), R3.2
NCONFIG: R16.2, U1.E8 (NCONFIG/E8)
NP_OSC_EN: U1.P8 (DIFFIO_RX_B6P/P8), U9.1 (EN)
NRST: J3.15, J6.15, R35.2, U1.P15 (DIFFIO_TX_RX_B10P/P15), U14.C1 (EN)
NSTATUS: R17.2, U1.D6 (DIFFIO_RX_T24P/NSTATUS/D6)
OSC_PDOWN_N_A: J3.12, U1.P3 (DIFFIO_RX_B2N/P3)
OSC_PDOWN_N_B: J6.12, U1.L10 (DIFFIO_TX_RX_B14N/L10)
PSB_CLK_A: J3.33, U1.K4 (DIFFIO_RX_L20P/CLK1P/K4)
PSB_CLK_B: J6.33, U1.L4 (DIFFIO_RX_L22P/DPCLK1/L4)
PSB_DATA_0_A: J3.31, U1.R13 (DIFFIO_TX_RX_B16P/R13)
PSB_DATA_0_B: J6.31, U1.L7 (DIFFIO_TX_RX_B3P/L7)
PSB_DATA_1_A: J3.30, U1.P7 (DIFFIO_TX_RX_B5P/P7)
PSB_DATA_1_B: J6.30, U1.M4 (DIFFIO_TX_RX_B1N/M4)
PSB_DATA_2_A: J3.28, U1.P6 (DIFFIO_TX_RX_B5N/P6)
PSB_DATA_2_B: J6.28, U1.P4 (DIFFIO_RX_B4N/P4)
PSB_DATA_3_A: J3.27, U1.P12
PSB_DATA_3_B: J6.27, U1.L8 (DIFFIO_TX_RX_B7N/L8)
PSB_DATA_4_A: J3.25, U1.R11 (VREFB3N0/R11)
PSB_DATA_4_B: J6.25, U1.L9 (DIFFIO_TX_RX_B12N/L9)
PSB_DATA_5_A: J3.24, U1.R7 (DIFFIO_RX_B6N/R7)
PSB_DATA_5_B: J6.24, U1.M5 (DIFFIO_TX_RX_B1P/M5)
PSB_DATA_6_A: J3.22, U1.R5 (DIFFIO_RX_B4P/R5)
PSB_DATA_6_B: J6.22, U1.M7 (DIFFIO_TX_RX_B7P/M7)
PSB_SYNC_A: J3.21, U1.P9 (DIFFIO_RX_B8N/P9)
PSB_SYNC_B: J6.21, U1.M11 (DIFFIO_TX_RX_B14P/M11)
REC_NRST_A: J3.16, U1.R3 (DIFFIO_RX_B2P/R3)
REC_NRST_B: J6.16, U1.M9 (DIFFIO_TX_RX_B12P/M9)
SER_DIN0: U1.B8 (DIFFIO_RX_T16N/DEV_CLRN/B8), U4.19 (DIN0)
SER_DIN1: U1.C8 (DIFFIO_RX_T16P/C8), U4.20 (DIN1)
SER_DIN2: U1.B4, U4.21 (DIN2)
SER_DIN3: U1.B6 (DIFFIO_RX_T20N/B6), U4.22 (DIN3)
SER_DIN4: U1.B7 (DIFFIO_RX_T20P/B7), U4.23 (DIN4)
SER_DIN5: U1.D10 (DIFFIO_RX_T14N/D10), U4.24 (DIN5)
SER_DIN6: U1.E2 (DIFFIO_RX_L7P/ADCIN8/E2), U4.26 (DIN6)
SER_DIN7: U1.E1 (DIFFIO_RX_L7N/ADCIN7/E1), U4.27 (DIN7)
SER_DIN8: U1.D2 (DIFFIO_RX_L1N/ADCIN1/D2), U4.29 (DIN8)
SER_DIN9: U1.C2 (DIFFIO_RX_L1P/ADCIN2/C2), U4.30 (DIN9)
SER_DIN10: U1.C1 (DIFFIO_RX_L5N/ADCIN5/C1), U4.31 (DIN10)
SER_DIN11: U1.B1 (DIFFIO_RX_L5P/ADCIN6/B1), U4.32 (DIN11)
SER_GPIO0: U1.A7 (DIFFIO_RX_T23P/A7), U4.15 (GPIO0)
SER_GPIO1: TP10.TP, U1.A9 (DIFFIO_RX_T21P/A9), U4.16 (GPIO1)
SER_GPIO2: R36.1, U1.B14 (DIFFIO_RX_T15N/B14), U4.17 (GPIO2/CLKOUT)
SER_GPIO3: U1.B12 (DIFFIO_RX_T19P/B12), U4.18 (GPO3/CLKIN)
SER_HSYNC: U1.A2 (DIFFIO_RX_T26P/A2), U4.1 (HSYNC)
SER_PCLK: U1.A11 (DIFFIO_RX_T21N/A11), U4.3 (PCLK1)
SER_SCL: R11.1, U1.A13 (VREFB8N0/A13), U4.4 (SCL)
SER_SDA: R15.1, U1.A14 (DIFFIO_RX_T17N/A14), U4.5 (SDA)
SER_VSYNC: U1.A3 (DIFFIO_RX_T26N/A3), U4.2 (VSYNC)
SIGOUT: C43.1, D3.C, J2.P$1 (1), L10.1
STATUS_A: D1.1 (C), U1.C15 (DIFFIO_RX_R28P/C15)
STATUS_B: D2.1 (C), U1.B15 (DIFFIO_RX_T15P/B15)
TCK: J1.1, R9.1, TP3.TP, U1.J1 (DIFFIO_RX_L11P/TCK/J1)
TDI: J1.9, R13.2, TP4.TP, U1.H5 (DIFFIO_RX_L12N/TDI/H5)
TDO: J1.3, TP5.TP, U1.H4 (DIFFIO_RX_L12P/TDO/H4)
TMS: J1.5, R8.2, TP2.TP, U1.G1 (DIFFIO_RX_L11N/TMS/G1)
VCCA: C1.1, C3.1, C5.1, C7.1, L1.2, U1.B3 (VCCA3/B3), U1.D14 (VCCA2/D14), U1.N2 (VCCA1/N2), U1.P13 (VCCA4/P13)
VCCIO: C10.1, C15.1, C19.1, C22.1, L5.2, U1.B5 (VCCIO8/B9,B5,B10), U1.B9 (VCCIO8/B9,B5,B10), U1.B10 (VCCIO8/B9,B5,B10), U1.F14 (VCCIO6/G14,F14), U1.G14 (VCCIO6/G14,F14), U1.L14 (VCCIO5/L14)
VCCIO2: C9.1, C14.1, C18.1, C21.1, L4.2, U1.L2 (VCCIO2/L2), U1.P5 (VCCIO3/P5,P11,P10), U1.P10 (VCCIO3/P5,P11,P10), U1.P11 (VCCIO3/P5,P11,P10)
VCCIOA: C12.1, C16.1, C23.1, L2.2, U1.F2 (VCCIO1A/F2)
VCOAX: C61.1, J5.1, L8.2, TP1.TP, U3.1 (IN), U3.2 (IN)

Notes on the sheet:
NB: VCoax must NOT exceed 5.5V
SERIALIZER
POWER
NEUROPIX
DEBUG
PIN 1 = leftmost pin, flex cable side odd numbers on flex cable side 21 = PSB_SYNC 31 = PSB_DATA_0 30 = PSB_DATA_1 28 = PSB_DATA_2 27 = PSB_DATA_3 25 = PSB_DATA_4 24 = PSB_DATA_5 22 = PSB_DATA_6 33 = PSB_CLK 18 = I2C_SDA 19 = I2C_SCL 35 = MCLK [93.6 MHz] 11 = CAL_SIGNAL 12 = OSC_PDOWN_N 15 = NRST 1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
NB: Core logic is LDOed from VCC_ONE
NB: Supply voltage for PLL regulator and ADC block (analog). Also determines ADC max voltage. Use 3.3V.
NB: VCCIO = 1.8V for the neuropix interface.
FPGA
South-East
East
South-West
West
North-West
North
North-East
Analog Ref - Internal VREF = 3.3V
NB: Programming interface
NB: 0.1 is not needed.
NB:CLK0 drives PLL1.
IMU
I2C Selected
NB To get the best performance out of BNO055, it is recommended to use the external 32.768 kHz crystal.
3D TRACKING
NB: programmed to 93.6 MHz
NP POR Sequence 1. Digital 1.8V and 1.2V on 2. Wait 10 msec (handled by Osc EN kinda: it takes 1.3 msec) 3. Enable MCLK 4. Wait 10 MCLK cycles 5. NRST = 1 for 10 periods 6. NRSET = 0 to reset 7. Wait 200 msec 8. Power on 1.8 analog 9. Wait 1.8 ms 10. Power on 1.2 analog
NB: 1.8 msec delay
NB: Input cap serves both LDOs
NB: Needed on POR to get LOCK

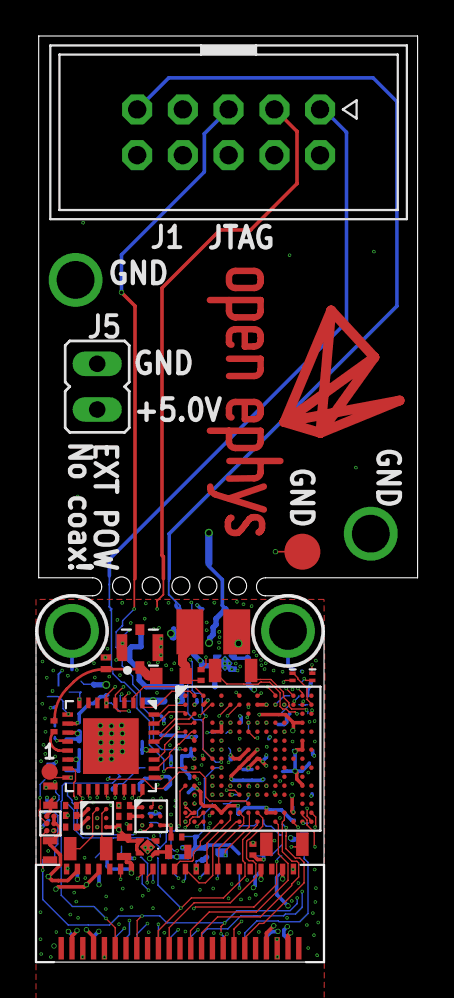
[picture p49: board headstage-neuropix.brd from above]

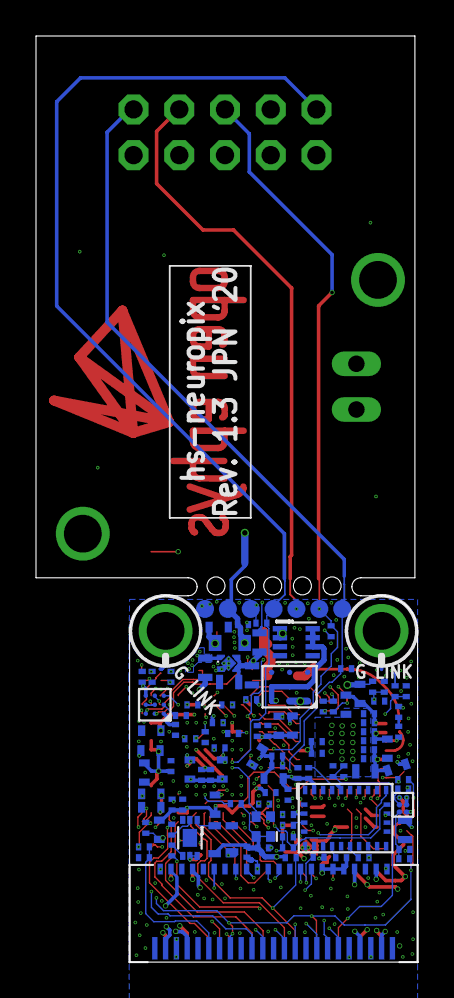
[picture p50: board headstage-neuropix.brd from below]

Board: 6 copper layers, 21.2 x 51.5 mm, 147 parts (112 on the bottom side), 121 nets.

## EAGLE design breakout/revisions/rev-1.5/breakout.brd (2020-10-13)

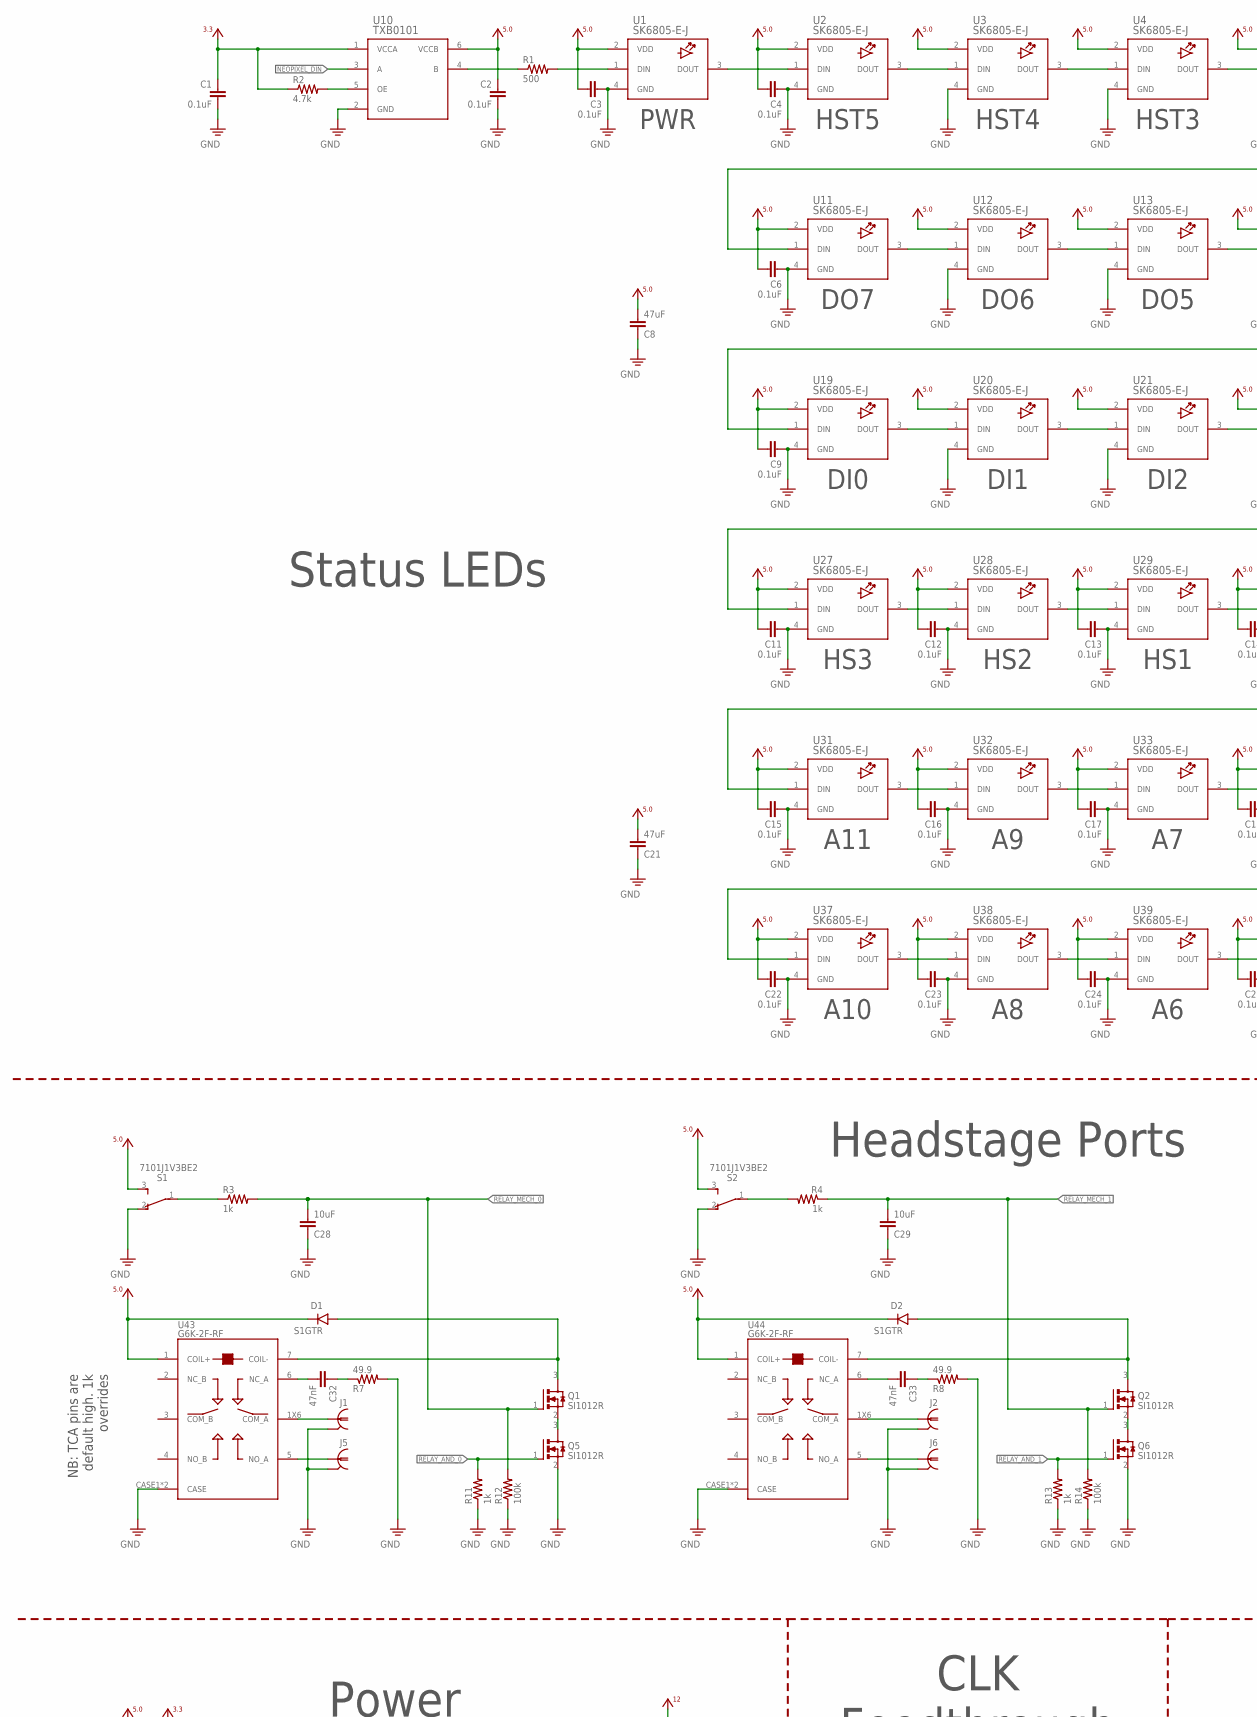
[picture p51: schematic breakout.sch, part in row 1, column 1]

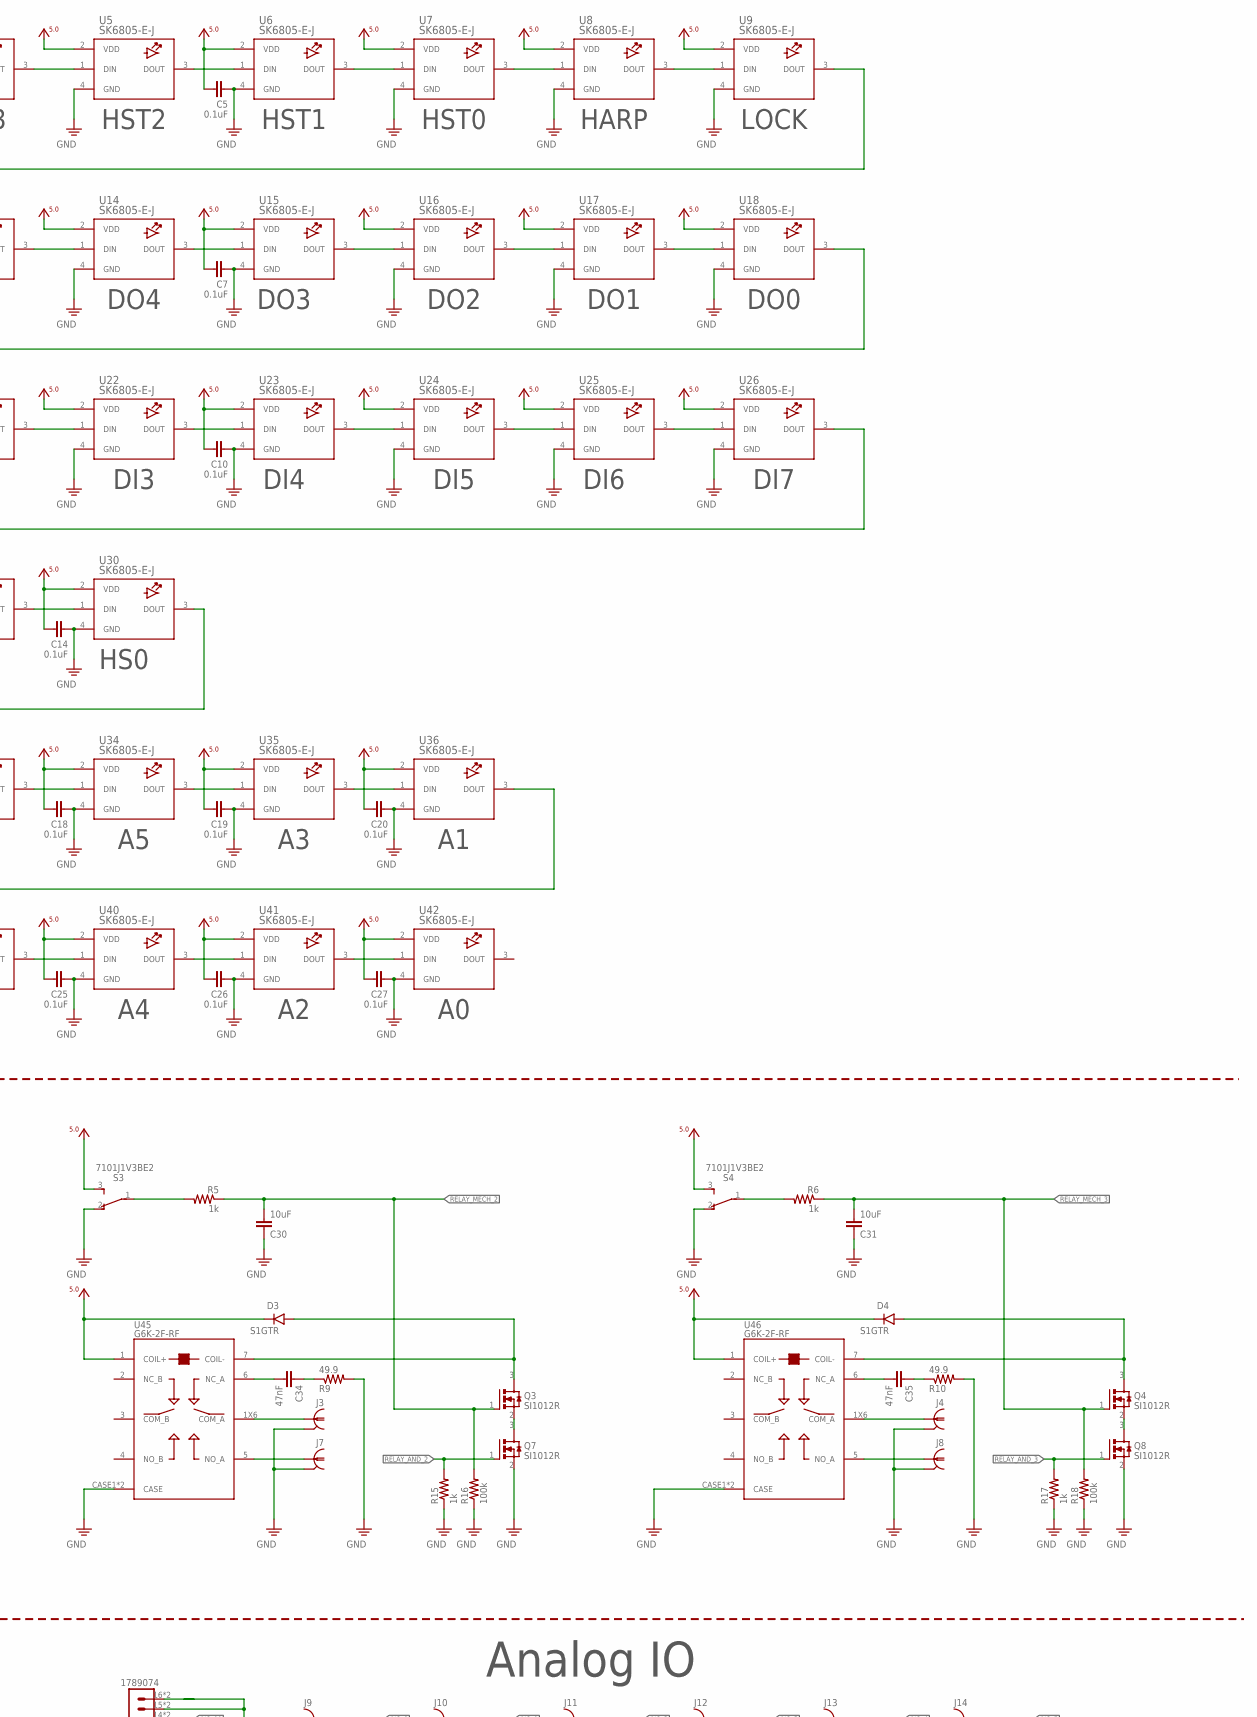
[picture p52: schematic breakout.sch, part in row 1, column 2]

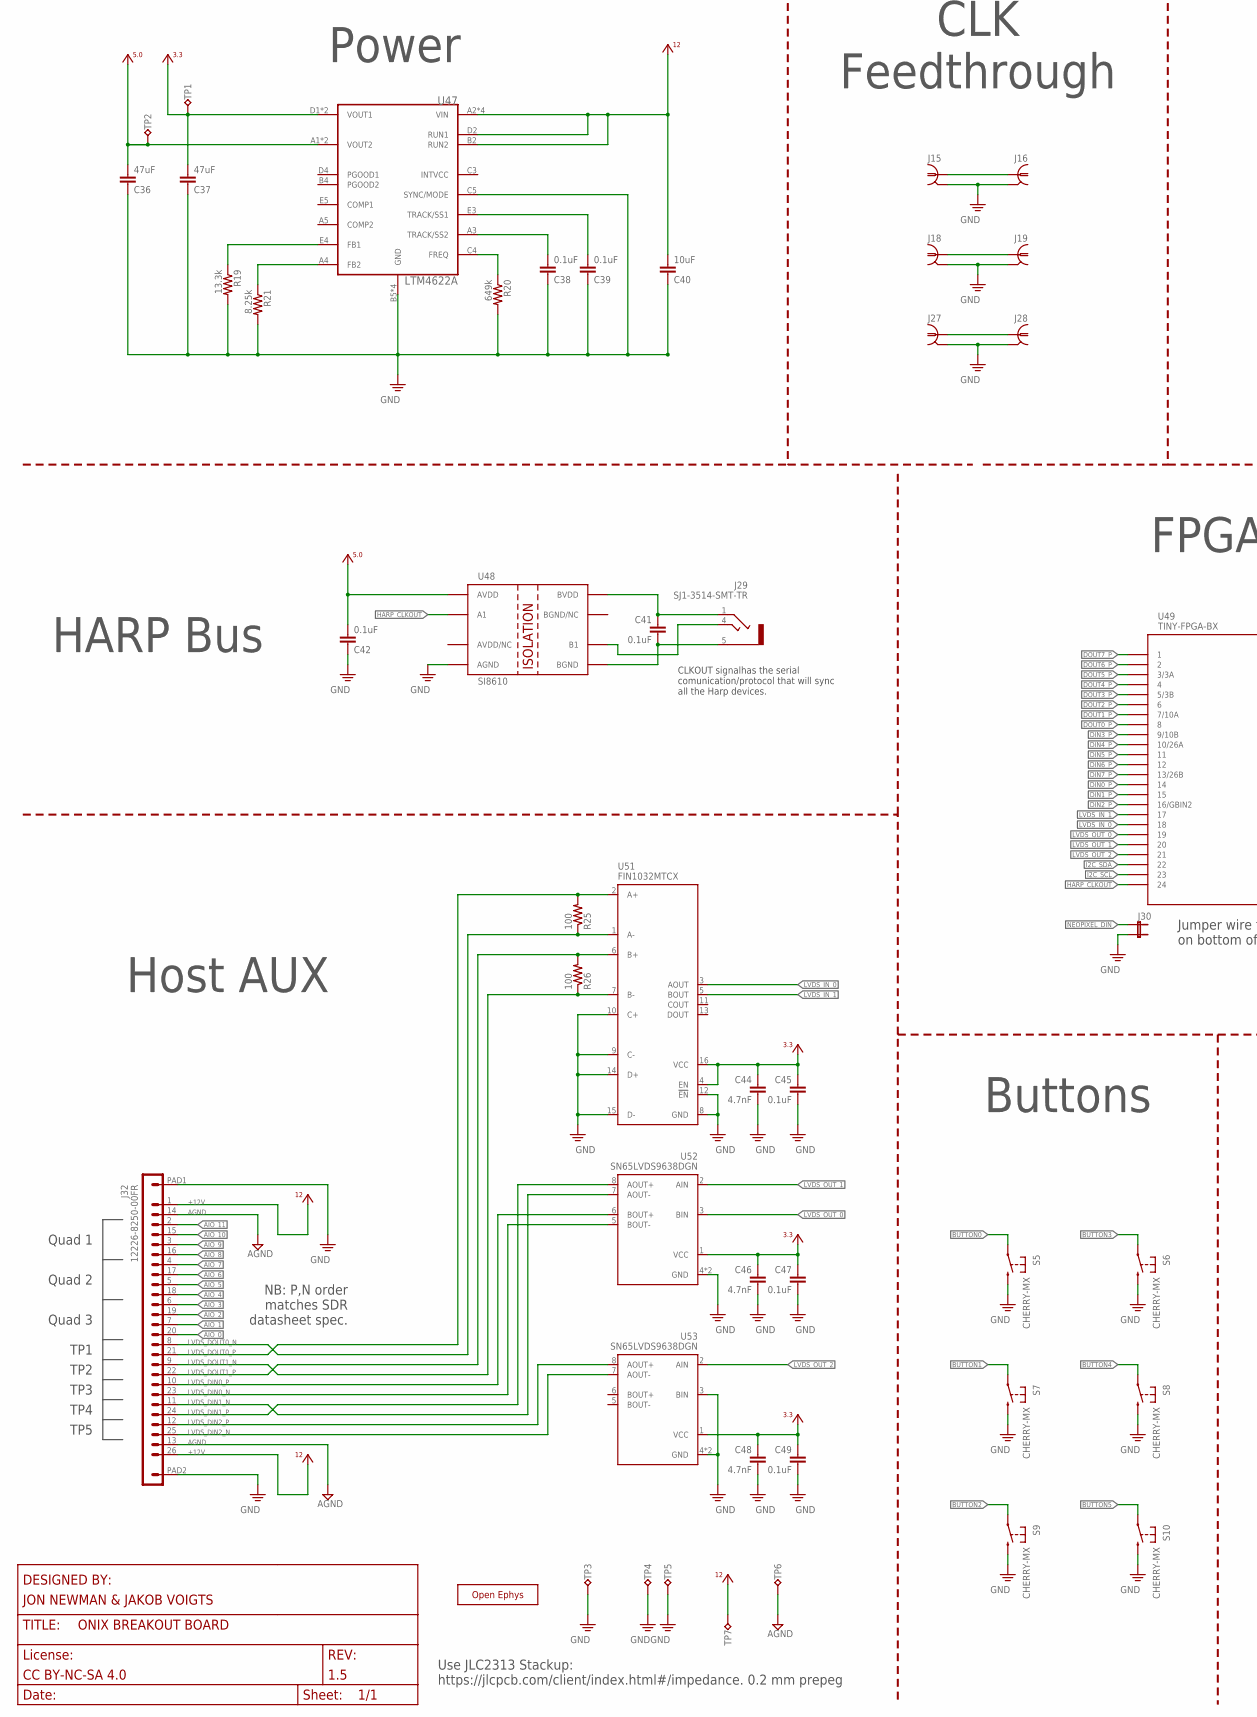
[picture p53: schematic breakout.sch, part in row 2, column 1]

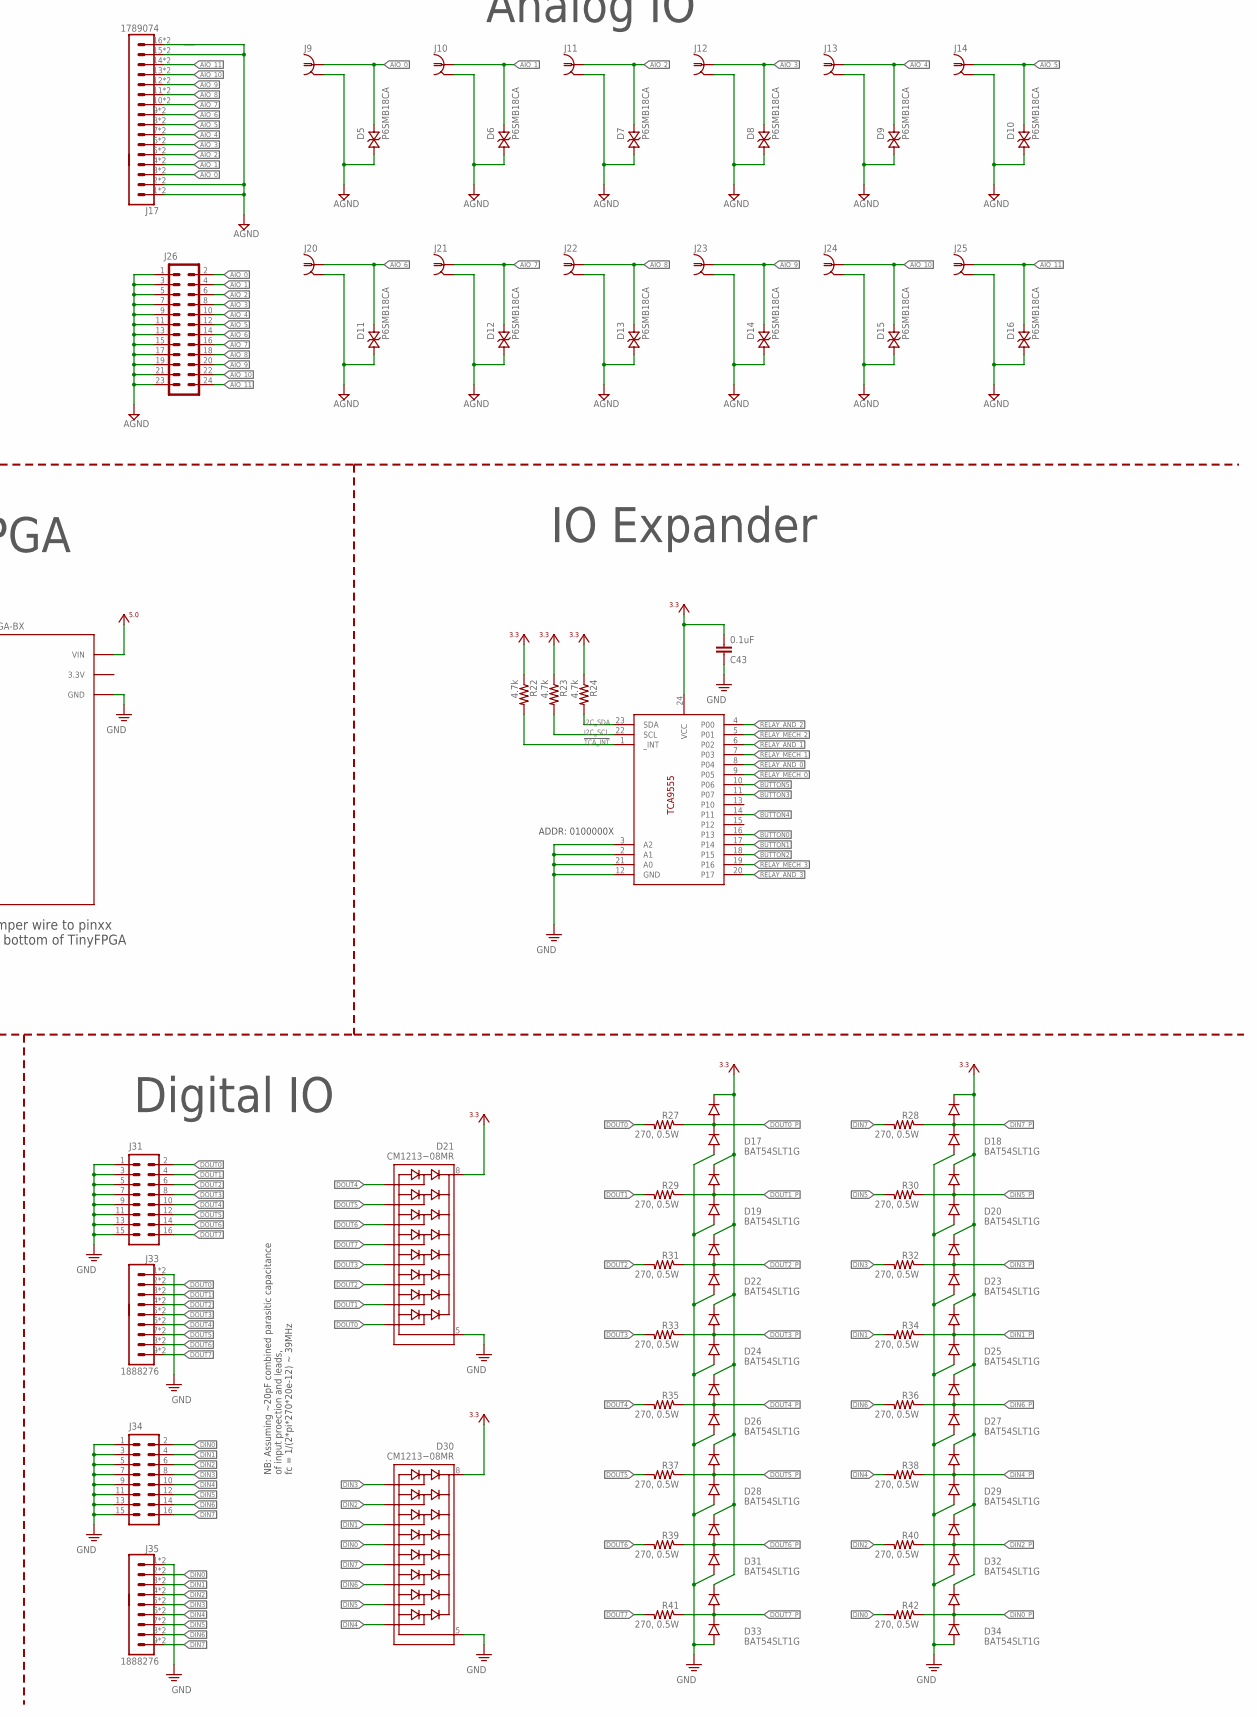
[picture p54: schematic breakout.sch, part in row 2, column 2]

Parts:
C1, C2, C3, C4, C5, C6, C7, C9, C10, C11, C12, C13, C14, C15, C16, C17, C18, C19, C20, C22, C23, C24, C25, C26, C27, C38, C39, C41, C42, C43, C45, C47, C49: 0.1uF; 0402
C8, C21, C36, C37: 47uF; 1210
C28, C29, C30, C31, C40: 10uF; 0805
C32, C33, C34, C35: 47nF; 0402
C44, C46, C48: 4.7nF; 0402
D1, D2, D3, D4: S1GTR; SMA-DO214AC
D5, D6, D7, D8, D9, D10, D11, D12, D13, D14, D15, D16: P6SMB18CA; SMA-DO214AC
D17, D18, D19, D20, D22, D23, D24, D25, D26, D27, D28, D29, D31, D32, D33, D34: BAT54SLT1G; SOT23
D21, D30: CM1213−08MR; MSOP-10-3X3
J1, J2, J3, J4, J16, J19, J28: COAX_SMA-VERT; SMA_JACK_142-0701-201
J5, J6, J7, J8, J15, J18, J27: COAX_MMCX-THRU; MMCX-THRU
J9, J10, J11, J12, J13, J14, J20, J21, J22, J23, J24, J25: COAX_0731010360; 0731010360
J17: 1789074; SCREW16-2
J26: 69168-124HLF; 2X12-BIG
J29: SJ1-3514-SMT-TR; 35RASMT2BHNTRX
J30: JP2E_THRU-HOLE; JP2
J31, J34: 69168-116HLF; 2X08-BIG
J32: 12226-8250-00FR; 12226-82X0-00XX
J33, J35: 1888276; SCREW9-2
Q1, Q2, Q3, Q4, Q5, Q6, Q7, Q8: SI1012R; SC75
R1: 500; 0402
R2, R22, R23, R24: 4.7k; 0402
R3, R4, R5, R6, R11, R13, R15, R17: 1k; 0402
R7, R8, R9, R10: 49.9; 0402
R12, R14, R16, R18: 100k; 0402
R19: 13.3k; 0402
R20: 649k; 0402
R21: 8.25k; 0402
R25, R26: 100; 0402
R27, R28, R29, R30, R31, R32, R33, R34, R35, R36, R37, R38, R39, R40, R41, R42: 270, 0.5W; 0805
S1, S2, S3, S4: 7101J1V3BE2; CK_7101J1V3QE2
S5, S6, S7, S8, S9, S10: CHERRY-MX
TP1, TP2: TPTP19R; TP19R
TP3, TP4, TP5, TP6, TP7: TP_2MM; TESTPOINT_2MM
U1, U2, U3, U4, U5, U6, U7, U8, U9, U11, U12, U13, U14, U15, U16, U17, U18, U19, U20, U21, U22, U23, U24, U25, U26, U27, U28, U29, U30, U31, U32, U33, U34, U35, U36, U37, U38, U39, U40, U41, U42: SK6805-E-J; NEOPIXEL-1.5X1.5
U10: TXB0101; SOT23-6
U43, U44, U45, U46: G6K-2F-RF; G6KU-2F-RF
U47: LTM4622A; BGA_5X5_625X625
U48: SI8610; SO-08
U49: TINY-FPGA-BX; TINY-FPGA-BX_BASIC
U50: TCA9555; TSSOP-24
U51: FIN1032MTCX; TSSOP-16
U52, U53: SN65LVDS9638DGN; MSOP-8-PAD-3X3
X: OE-LOGO_28X20; OE-LOGO-28X20

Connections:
!TCA_INT: R22.2, U50.1 (_INT)
+3V3: C1.1, C37.2, C43.2, C44.1, C45.1, C46.1, C47.1, C48.1, C49.1, D17.2 (C), D18.2 (C), D19.2 (C), D20.2 (C), D21.8 (VCC), D22.2 (C), D23.2 (C), D24.2 (C), D25.2 (C), D26.2 (C), D27.2 (C), D28.2 (C), D29.2 (C), D30.8 (VCC), D31.2 (C), D32.2 (C), D33.2 (C), D34.2 (C), R2.1, R22.1, R23.1, R24.1, TP1.TP, U10.1 (VCCA), U47.D1 (VOUT1), U47.E1 (VOUT1), U50.24 (VCC), U51.4 (EN), U51.16 (VCC), U52.1 (VCC), U53.1 (VCC)
+5V0: C2.1, C3.2, C4.2, C5.2, C6.2, C7.2, C8.2, C9.2, C10.2, C11.2, C12.2, C13.2, C14.2, C15.2, C16.2, C17.2, C18.2, C19.2, C20.2, C21.2, C22.2, C23.2, C24.2, C25.2, C26.2, C27.2, C36.2, C42.2, D1.C, D2.C, D3.C, D4.C, S1.3, S2.3, S3.3, S4.3, TP2.TP, U1.2 (VDD), U2.2 (VDD), U3.2 (VDD), U4.2 (VDD), U5.2 (VDD), U6.2 (VDD), U7.2 (VDD), U8.2 (VDD), U9.2 (VDD), U10.6 (VCCB), U11.2 (VDD), U12.2 (VDD), U13.2 (VDD), U14.2 (VDD), U15.2 (VDD), U16.2 (VDD), U17.2 (VDD), U18.2 (VDD), U19.2 (VDD), U20.2 (VDD), U21.2 (VDD), U22.2 (VDD), U23.2 (VDD), U24.2 (VDD), U25.2 (VDD), U26.2 (VDD), U27.2 (VDD), U28.2 (VDD), U29.2 (VDD), U30.2 (VDD), U31.2 (VDD), U32.2 (VDD), U33.2 (VDD), U34.2 (VDD), U35.2 (VDD), U36.2 (VDD), U37.2 (VDD), U38.2 (VDD), U39.2 (VDD), U40.2 (VDD), U41.2 (VDD), U42.2 (VDD), U43.1 (COIL+), U44.1 (COIL+), U45.1 (COIL+), U46.1 (COIL+), U47.A1 (VOUT2), U47.B1 (VOUT2), U48.1 (AVDD), U49.VIN
+12V: C40.2, J32.1, J32.26, TP7.1, U47.A2 (VIN), U47.B2 (RUN2), U47.B3 (VIN), U47.D2 (RUN1), U47.D3 (VIN), U47.E2 (VIN)
AGND: D5.A (1), D6.A (1), D7.A (1), D8.A (1), D9.A (1), D10.A (1), D11.A (1), D12.A (1), D13.A (1), D14.A (1), D15.A (1), D16.A (1), J9.2, J9.3 (2), J9.4 (2), J9.5 (2), J10.2, J10.3 (2), J10.4 (2), J10.5 (2), J11.2, J11.3 (2), J11.4 (2), J11.5 (2), J12.2, J12.3 (2), J12.4 (2), J12.5 (2), J13.2, J13.3 (2), J13.4 (2), J13.5 (2), J14.2, J14.3 (2), J14.4 (2), J14.5 (2), J17.1, J17.2, J17.15, J17.16, J17.17 (1), J17.18 (2), J17.31 (15), J17.32 (16), J20.2, J20.3 (2), J20.4 (2), J20.5 (2), J21.2, J21.3 (2), J21.4 (2), J21.5 (2), J22.2, J22.3 (2), J22.4 (2), J22.5 (2), J23.2, J23.3 (2), J23.4 (2), J23.5 (2), J24.2, J24.3 (2), J24.4 (2), J24.5 (2), J25.2, J25.3 (2), J25.4 (2), J25.5 (2), J26.1, J26.3, J26.5, J26.7, J26.9, J26.11, J26.13, J26.15, J26.17, J26.19, J26.21, J26.23, J32.13, J32.14, TP6.1
AIO_0: D5.C (2), J9.1, J17.3, J17.19 (3), J26.2, J32.20
AIO_1: D6.C (2), J10.1, J17.4, J17.20 (4), J26.4, J32.7
AIO_2: D7.C (2), J11.1, J17.5, J17.21 (5), J26.6, J32.19
AIO_3: D8.C (2), J12.1, J17.6, J17.22 (6), J26.8, J32.6
AIO_4: D9.C (2), J13.1, J17.7, J17.23 (7), J26.10, J32.18
AIO_5: D10.C (2), J14.1, J17.8, J17.24 (8), J26.12, J32.5
AIO_6: D11.C (2), J17.9, J17.25 (9), J20.1, J26.14, J32.17
AIO_7: D12.C (2), J17.10, J17.26 (10), J21.1, J26.16, J32.4
AIO_8: D13.C (2), J17.11, J17.27 (11), J22.1, J26.18, J32.16
AIO_9: D14.C (2), J17.12, J17.28 (12), J23.1, J26.20, J32.3
AIO_10: D15.C (2), J17.13, J17.29 (13), J24.1, J26.22, J32.15
AIO_11: D16.C (2), J17.14, J17.30 (14), J25.1, J26.24, J32.2
BUTTON0: S5.SW1, U50.16 (P13)
BUTTON1: S7.SW1, U50.17 (P14)
BUTTON2: S9.SW1, U50.18 (P15)
BUTTON3: S6.SW1, U50.11 (P07)
BUTTON4: S8.SW1, U50.14 (P11)
BUTTON5: S10.SW1, U50.10 (P06)
DIN0: D30.4 (CH4), J34.2, J35.2, J35.11 (2), R42.2
DIN0_P: D34.3 (COMM), R42.1, U49.14
DIN1: D30.3 (CH3), J34.4, J35.3, J35.12 (3), R34.2
DIN1_P: D25.3 (COMM), R34.1, U49.15
DIN2: D30.2 (CH2), J34.6, J35.4, J35.13 (4), R40.2
DIN2_P: D32.3 (COMM), R40.1, U49.16 (16/GBIN2)
DIN3: D30.1 (CH1), J34.8, J35.5, J35.14 (5), R32.2
DIN3_P: D23.3 (COMM), R32.1, U49.9 (9/10B)
DIN4: D30.10 (CH8), J34.10, J35.6, J35.15 (6), R38.2
DIN4_P: D29.3 (COMM), R38.1, U49.10 (10/26A)
DIN5: D30.9 (CH7), J34.12, J35.7, J35.16 (7), R30.2
DIN5_P: D20.3 (COMM), R30.1, U49.11
DIN6: D30.7 (CH6), J34.14, J35.8, J35.17 (8), R36.2
DIN6_P: D27.3 (COMM), R36.1, U49.12
DIN7: D30.6 (CH5), J34.16, J35.9, J35.18 (9), R28.2
DIN7_P: D18.3 (COMM), R28.1, U49.13 (13/26B)
DOUT0: D21.10 (CH8), J31.2, J33.2, J33.11 (2), R27.2
DOUT0_P: D17.3 (COMM), R27.1, U49.8
DOUT1: D21.9 (CH7), J31.4, J33.3, J33.12 (3), R29.2
DOUT1_P: D19.3 (COMM), R29.1, U49.7 (7/10A)
DOUT2: D21.7 (CH6), J31.6, J33.4, J33.13 (4), R31.2
DOUT2_P: D22.3 (COMM), R31.1, U49.6
DOUT3: D21.6 (CH5), J31.8, J33.5, J33.14 (5), R33.2
DOUT3_P: D24.3 (COMM), R33.1, U49.5 (5/3B)
DOUT4: D21.1 (CH1), J31.10, J33.6, J33.15 (6), R35.2
DOUT4_P: D26.3 (COMM), R35.1, U49.4
DOUT5: D21.2 (CH2), J31.12, J33.7, J33.16 (7), R37.2
DOUT5_P: D28.3 (COMM), R37.1, U49.3 (3/3A)
DOUT6: D21.3 (CH3), J31.14, J33.8, J33.17 (8), R39.2
DOUT6_P: D31.3 (COMM), R39.1, U49.2
DOUT7: D21.4 (CH4), J31.16, J33.9, J33.18 (9), R41.2
DOUT7_P: D33.3 (COMM), R41.1, U49.1
GND: C1.2, C2.2, C3.1, C4.1, C5.1, C6.1, C7.1, C8.1, C9.1, C10.1, C11.1, C12.1, C13.1, C14.1, C15.1, C16.1, C17.1, C18.1, C19.1, C20.1, C21.1, C22.1, C23.1, C24.1, C25.1, C26.1, C27.1, C28.1, C29.1, C30.1, C31.1, C36.1, C37.1, C38.1, C39.1, C40.1, C42.1, C43.1, C44.2, C45.2, C46.2, C47.2, C48.2, C49.2, D17.1 (A), D18.1 (A), D19.1 (A), D20.1 (A), D21.5 (VSS), D22.1 (A), D23.1 (A), D24.1 (A), D25.1 (A), D26.1 (A), D27.1 (A), D28.1 (A), D29.1 (A), D30.5 (VSS), D31.1 (A), D32.1 (A), D33.1 (A), D34.1 (A), J1.GND$1 (2), J1.GND$2 (2), J1.GND$3 (2), J1.GND$4 (2), J2.GND$1 (2), J2.GND$2 (2), J2.GND$3 (2), J2.GND$4 (2), J3.GND$1 (2), J3.GND$2 (2), J3.GND$3 (2), J3.GND$4 (2), J4.GND$1 (2), J4.GND$2 (2), J4.GND$3 (2), J4.GND$4 (2), J5.GND@1 (2), J5.GND@2 (2), J5.GND@3 (2), J5.GND@4 (2), J6.GND@1 (2), J6.GND@2 (2), J6.GND@3 (2), J6.GND@4 (2), J7.GND@1 (2), J7.GND@2 (2), J7.GND@3 (2), J7.GND@4 (2), J8.GND@1 (2), J8.GND@2 (2), J8.GND@3 (2), J8.GND@4 (2), J15.GND@1 (2), J15.GND@2 (2), J15.GND@3 (2), J15.GND@4 (2), J16.GND$1 (2), J16.GND$2 (2), J16.GND$3 (2), J16.GND$4 (2), J18.GND@1 (2), J18.GND@2 (2), J18.GND@3 (2), J18.GND@4 (2), J19.GND$1 (2), J19.GND$2 (2), J19.GND$3 (2), J19.GND$4 (2), J27.GND@1 (2), J27.GND@2 (2), J27.GND@3 (2), J27.GND@4 (2), J28.GND$1 (2), J28.GND$2 (2), J28.GND$3 (2), J28.GND$4 (2), J30.2, J31.1, J31.3, J31.5, J31.7, J31.9, J31.11, J31.13, J31.15, J32.PAD1, J32.PAD2, J33.1, J33.10 (1), J34.1, J34.3, J34.5, J34.7, J34.9, J34.11, J34.13, J34.15, J35.1, J35.10 (1), Q5.2 (S), Q6.2 (S), Q7.2 (S), Q8.2 (S), R7.2, R8.2, R9.2, R10.2, R11.1, R12.1, R13.1, R14.1, R15.1, R16.1, R17.1, R18.1, R19.2, R20.2, R21.2, S1.2 (1), S2.2 (1), S3.2 (1), S4.2 (1), S5.SW2 (S), S6.SW2 (S), S7.SW2 (S), S8.SW2 (S), S9.SW2 (S), S10.SW2 (S), TP3.1, TP4.1, TP5.1, U1.4 (GND), U2.4 (GND), U3.4 (GND), U4.4 (GND), U5.4 (GND), U6.4 (GND), U7.4 (GND), U8.4 (GND), U9.4 (GND), U10.2 (GND), U11.4 (GND), U12.4 (GND), U13.4 (GND), U14.4 (GND), U15.4 (GND), U16.4 (GND), U17.4 (GND), U18.4 (GND), U19.4 (GND), U20.4 (GND), U21.4 (GND), U22.4 (GND), U23.4 (GND), U24.4 (GND), U25.4 (GND), U26.4 (GND), U27.4 (GND), U28.4 (GND), U29.4 (GND), U30.4 (GND), U31.4 (GND), U32.4 (GND), U33.4 (GND), U34.4 (GND), U35.4 (GND), U36.4 (GND), U37.4 (GND), U38.4 (GND), U39.4 (GND), U40.4 (GND), U41.4 (GND), U42.4 (GND), U43.CASE1 (CASE), U43.CASE2 (CASE), U44.CASE1 (CASE), U44.CASE2 (CASE), U45.CASE1 (CASE), U45.CASE2 (CASE), U46.CASE1 (CASE), U46.CASE2 (CASE), U47.B5 (GND), U47.C1 (GND), U47.C2 (GND), U47.C5 (SYNC/MODE), U47.D5 (GND), U48.4 (AGND), U49.GND@1 (GND), U49.GND@2 (GND), U50.2 (A1), U50.3 (A2), U50.12 (GND), U50.21 (A0), U51.8 (GND), U51.9 (C-), U51.10 (C+), U51.12 (!EN), U51.14 (D+), U51.15 (D-), U52.4 (GND), U52.PAD (GND), U53.3 (BIN), U53.4 (GND), U53.PAD (GND)
HARP_CLKOUT: U48.2 (A1), U49.24
I2C_SCL: R23.2, U49.23, U50.22 (SCL)
I2C_SDA: R24.2, U49.22, U50.23 (SDA)
LOCKED: U9.3 (DOUT), U11.1 (DIN)
LVDS_DIN0_N: J32.23, U52.5 (BOUT-)
LVDS_DIN0_P: J32.10, U52.6 (BOUT+)
LVDS_DIN1_N: J32.11, U52.7 (AOUT-)
LVDS_DIN1_P: J32.24, U52.8 (AOUT+)
LVDS_DIN2_N: J32.25, U53.7 (AOUT-)
LVDS_DIN2_P: J32.12, U53.8 (AOUT+)
LVDS_DOUT0_N: J32.8, R25.1, U51.1 (A-)
LVDS_DOUT0_P: J32.21, R25.2, U51.2 (A+)
LVDS_DOUT1_N: J32.9, R26.1, U51.7 (B-)
LVDS_DOUT1_P: J32.22, R26.2, U51.6 (B+)
LVDS_IN_0: U49.18, U51.3 (AOUT)
LVDS_IN_1: U49.17, U51.5 (BOUT)
LVDS_OUT_0: U49.19, U52.3 (BIN)
LVDS_OUT_1: U49.20, U52.2 (AIN)
LVDS_OUT_2: U49.21, U53.2 (AIN)
unnamed: J15.SIG (1), J16.CLK (1)
unnamed: J18.SIG (1), J19.CLK (1)
unnamed: J27.SIG (1), J28.CLK (1)
unnamed: D1.A, Q1.3 (D), U43.7 (COIL-)
unnamed: Q1.2 (S), Q5.3 (D)
unnamed: U11.3 (DOUT), U12.1 (DIN)
unnamed: U12.3 (DOUT), U13.1 (DIN)
unnamed: U13.3 (DOUT), U14.1 (DIN)
unnamed: U36.3 (DOUT), U37.1 (DIN)
unnamed: U31.3 (DOUT), U32.1 (DIN)
unnamed: D2.A, Q2.3 (D), U44.7 (COIL-)
unnamed: U15.3 (DOUT), U16.1 (DIN)
unnamed: U16.3 (DOUT), U17.1 (DIN)
unnamed: C32.2, U43.6 (NC_A)
unnamed: C41.1, J29.1, U48.8 (BVDD)
unnamed: C41.2, J29.5, U48.5 (BGND)
unnamed: J29.4, U48.6 (B1)
unnamed: J6.SIG (1), U44.5 (NO_A)
unnamed: U17.3 (DOUT), U18.1 (DIN)
unnamed: U1.3 (DOUT), U2.1 (DIN)
unnamed: C33.1, R8.1
unnamed: R3.1, S1.1 (2)
unnamed: R21.1, U47.A4 (FB2)
unnamed: R19.1, U47.E4 (FB1)
unnamed: C38.2, U47.A3 (TRACK/SS2)
unnamed: C39.2, U47.E3 (TRACK/SS1)
unnamed: J5.SIG (1), U43.5 (NO_A)
unnamed: J1.CLK (1), U43.1X6 (COM_A)
unnamed: C32.1, R7.1
unnamed: C33.2, U44.6 (NC_A)
unnamed: Q3.2 (S), Q7.3 (D)
unnamed: C34.1, R9.1
unnamed: J2.CLK (1), U44.1X6 (COM_A)
unnamed: R4.2, S2.1 (2)
unnamed: C34.2, U45.6 (NC_A)
unnamed: J7.SIG (1), U45.5 (NO_A)
unnamed: R5.2, S3.1 (2)
unnamed: Q2.2 (S), Q6.3 (D)
unnamed: U2.3 (DOUT), U3.1 (DIN)
unnamed: U3.3 (DOUT), U4.1 (DIN)
unnamed: J3.CLK (1), U45.1X6 (COM_A)
unnamed: R6.2, S4.1 (2)
unnamed: C35.1, R10.1
unnamed: C35.2, U46.6 (NC_A)
unnamed: J8.SIG (1), U46.5 (NO_A)
unnamed: J4.CLK (1), U46.1X6 (COM_A)
unnamed: U4.3 (DOUT), U5.1 (DIN)
unnamed: D3.A, Q3.3 (D), U45.7 (COIL-)
unnamed: U6.3 (DOUT), U7.1 (DIN)
unnamed: U7.3 (DOUT), U8.1 (DIN)
unnamed: U8.3 (DOUT), U9.1 (DIN)
unnamed: R1.2, U1.1 (DIN)
unnamed: R1.1, U10.4 (B)
unnamed: U5.3 (DOUT), U6.1 (DIN)
unnamed: R2.2, U10.5 (OE)
unnamed: U14.3 (DOUT), U15.1 (DIN)
unnamed: D4.A, Q4.3 (D), U46.7 (COIL-)
unnamed: Q4.2 (S), Q8.3 (D)
unnamed: U32.3 (DOUT), U33.1 (DIN)
unnamed: U33.3 (DOUT), U34.1 (DIN)
unnamed: U34.3 (DOUT), U35.1 (DIN)
unnamed: U35.3 (DOUT), U36.1 (DIN)
unnamed: U37.3 (DOUT), U38.1 (DIN)
unnamed: U38.3 (DOUT), U39.1 (DIN)
unnamed: U39.3 (DOUT), U40.1 (DIN)
unnamed: U40.3 (DOUT), U41.1 (DIN)
unnamed: U41.3 (DOUT), U42.1 (DIN)
unnamed: U18.3 (DOUT), U19.1 (DIN)
unnamed: U19.3 (DOUT), U20.1 (DIN)
unnamed: U20.3 (DOUT), U21.1 (DIN)
unnamed: U21.3 (DOUT), U22.1 (DIN)
unnamed: U22.3 (DOUT), U23.1 (DIN)
unnamed: U23.3 (DOUT), U24.1 (DIN)
unnamed: U24.3 (DOUT), U25.1 (DIN)
unnamed: U25.3 (DOUT), U26.1 (DIN)
unnamed: U26.3 (DOUT), U27.1 (DIN)
unnamed: U27.3 (DOUT), U28.1 (DIN)
unnamed: U28.3 (DOUT), U29.1 (DIN)
unnamed: U29.3 (DOUT), U30.1 (DIN)
unnamed: U30.3 (DOUT), U31.1 (DIN)
unnamed: R20.1, U47.C4 (FREQ)
NEOPIXEL_DIN: J30.1, U10.3 (A)
RELAY_AND_0: Q5.1 (G), R11.2, U50.8 (P04)
RELAY_AND_1: Q6.1 (G), R13.2, U50.6 (P02)
RELAY_AND_2: Q7.1 (G), R15.2, U50.4 (P00)
RELAY_AND_3: Q8.1 (G), R17.2, U50.20 (P17)
RELAY_MECH_0: C28.2, Q1.1 (G), R3.2, R12.2, U50.9 (P05)
RELAY_MECH_1: C29.2, Q2.1 (G), R4.1, R14.2, U50.7 (P03)
RELAY_MECH_2: C30.2, Q3.1 (G), R5.1, R16.2, U50.5 (P01)
RELAY_MECH_3: C31.2, Q4.1 (G), R6.1, R18.2, U50.19 (P16)

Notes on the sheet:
Use JLC2313 Stackup: https://jlcpcb.com/client/index.html#/impedance. 0.2 mm prepeg
NB: P,N order matches SDR datasheet spec.
Power
Host AUX
Headstage Ports
Analog IO
CLKOUT signalhas the serial comunication/protocol that will sync all the Harp devices.
HARP Bus
CLK Feedthrough
Quad 1
Quad 2
Quad 3
TP1
TP2
TP3
TP4
TP5
IO Expander
Buttons
FPGA
Digital IO
Status LEDs
ADDR: 0100000X
NB: Assuming ~20pF combined parasitic capacitance of input proection and leads, fc = 1/(2*pi*270*20e-12) ~ 39MHz
Jumper wire to pinxx on bottom of TinyFPGA
PWR
HST0
HARP
LOCK
DO7
DO6
DO5
DO4
DO3
DO2
DO1
DO0
DI0
DI1
DI2


Board: 4 copper layers, 505.0 x 160.0 mm, 242 parts (0 on the bottom side), 165 nets.

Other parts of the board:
E$1, E$3, E$5: FIDUCIAL

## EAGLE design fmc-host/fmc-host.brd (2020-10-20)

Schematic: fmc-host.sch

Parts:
C1, C2, C6, C7, C27, C28, C35, C36, C37, C38, C72, C73, C74, C75, C81, C82, C83, C93, C94, C108, C120, C139, C140: 10uF; 1206
C3, C4, C8, C9, C10, C11, C14, C15, C16, C17, C18, C19, C20, C23, C24, C31, C32, C33, C34, C39, C43, C45, C46, C47, C48, C49, C50, C51, C54, C55, C56, C57, C58, C62, C63, C65, C67, C69, C70, C80, C85, C86, C87, C88, C89, C91, C92, C95, C101, C102, C106, C109, C112, C113, C114, C116, C117, C133, C134, C135, C137, C138: 0.1uF; 0402
C5, C29, C30: 4.7nF; 0402
C12, C13, C21, C22, C25, C26, C52, C53, C59, C60, C84, C124, C125, C126: 10nF; 0402
C40, C41: 47nF; 0402
C42, C44, C66, C68, C76, C77, C78, C90: 1uF; 0805
C61, C64, C71, C79, C97, C98, C103, C105, C107, C110, C111, C115, C118, C119, C121, C122, C123, C127, C128, C129: 10uF; 0805
C96, C99, C100, C104, C130, C131, C132, C136: 47uF; 1210
D1, D2, D3: HSMG-C280; LED-0402
D4, D5: SESD0402X1UN-0020-090; 0402P-DFN
D6, D7, D8: BAR66; SOT23
D9: KDZ4.3B; SOD123
D10, D11: APFA3011-AK13/F; RGB_LED_SMD-6
F1, F2, F3: C014F-2; 1812
J1, J2, J3, J4, J5: SMA002; MMCX-THRU
J6: ESHF-105-01-L-D-SM-K-TR
J7: 12226-8250-00FR; 12226-82X0-00XX
J8: 95278-101A16LF; JP2X8_SMD
J9: FMC_SINGLE_WIDTH_MODULE
J10: ASP-134488-01; FMC_HPC_MALE
L1, L2: 1008PS-472; 1008PS
L3, L4, L9, L10, L11, L12: BLM18KG601SN1D; 0603
L5, L6: SRNxx-101M; SRN6045TA
L7, L8: MPZ2012S102AT000; 0805
L13: L_1210; 1210
L14, L15, L16, L17, L18, L19: BLM15PX601SN1D; 0402; PARTNO BLM15PX601SN1D
Q1, Q2: SI1012R; SC75
R1, R6, R7, R12, R13, R63, R64: 2k; 0402
R2, R3, R36, R37, R38, R39, R46, R49, R77, R79, R81: 4.7k; 0402
R4, R5, R33, R44, R45: 3k; 0402
R8, R9, R10, R11, R14, R15: 150,0.25W; 0603
R16, R17, R55, R56, R57, R58, R82: 165k; 0402
R18, R19, R41, R43, R65, R70, R71, R72, R73, R74, R84, R85: 10k; 0402
R20, R21, R47, R48, R50, R51, R52, R53: 1k; 0402
R22, R24: 5.6k 1%; 0402
R23, R25: 21k 1%; 0402
R26, R27: 60 1%; 0402
R28, R29, R34, R35: 49.9; 0402
R30, R31, R32: 100; 0402
R40, R42: DNP; 0402
R54, R69: 0; 0402
R59, R60, R61, R62: 2.2k; RN2X8-1506
R66, R67: 3.48k; 0402
R68: 649k; 0402
R75: 2.2k; 0402
R76: 15k; 0402
R78, R80: 43k; 0402
R83: 178k; 0402
R86, R87: 73.2k; 0402
S1, S2: CHS-01TA; DIP01-SMD-GULL
S3: CHS-02TB
SJ1, SJ2: SJ2_0201; SJ_2_0201
TP1, TP2, TP4, TP5, TP6, TP7, TP11, TP12, TP13, TP14, TP15, TP16: TPB1,27; B1,27
TP3, TP8, TP9, TP10, TP17, TP18: TPB2,54; B2,54
U1: SN74LVC2G34DCKR; SC70
U2: SN65LVDS9638DGN; MSOP-8-PAD-3X3
U3: FIN1032MTCX; TSSOP-16
U4: LTC2875_DFN; DFN83X3
U5, U6: ADCMP600; SOT-23-5
U7, U8, U9: DG1412E; QFN16-4X4MM
U10, U11: DS90UB934-Q1; WQFN48-7X7-PAD
U12: DS91M040; WQFN32-5X5
U13: AD5766BCPZ-RL7; CP_40_7
U14: MCP47FEB02A0-E/ST; TSSOP-8
U15: LM4132AMF-2.5/NOPBCT-ND; SOT-23-5
U16: AD7617BSTZ; ST_80_2
U17: AD5142BCPZ10; CP_16_27-L
U18: LTM4622A; BGA_5X5_625X625
U19: TPS62293DRV; WSON6-2X2
U20, U21: TPS7A49; PVSON-N8+4-3X3
U22: TPS7A30; PVSON-N8+4-3X3
U23: 24AA64ST; TSSOP8
U24: LTM8049_BGA; LTM8049
X2, X3: OE-LOGO_7X5; OE-LOGO-7X5

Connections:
!ADC_CS: J10.H13 (LA07_P), U16.63 (!CS)
!ADC_RESET: J10.F10 (HA08_P), R72.2
!DAC_CS: J10.J16 (HA14_N), U13.8 (!CS)
!DAC_RESET: J10.F14 (HA12_N), U13.3 (!RESET)
!LINK_PWR_ADJ_CS: J10.F38 (HB20_N), U17.14 (!CS)
!LINK_PWR_ADJ_RESET: J10.E37 (HB21_N), U17.16 (!RESET)
$N1: D8.3 (COMM), F2.2, R5.2, R9.2, R11.2, R15.2, R29.1
$N2: D6.3 (COMM), F3.2, U1.4 (OUT2), U1.6 (OUT1)
$N3: D7.3 (COMM), F1.2, R4.2, R8.2, R10.2, R14.2, R28.1
+1V8: C88.2, C89.2, C93.2, C94.2, C108.2, L3.2, L4.2, L9.1, L10.1, L13.1, R22.1, R24.1, R40.1, R42.1, TP16.TP, U10.17 (VDD18), U11.17 (VDD18), U19.3 (FB)
+3V3: C11.2, C23.1, C24.1, C29.1, C30.1, C33.1, C34.1, C39.1, C76.2, C80.2, C84.2, C91.2, C95.2, C98.2, C113.2, C115.2, C116.2, C119.2, C120.2, C136.2, C137.2, C138.2, C139.1, C140.1, J10.E39 (VADJ), J10.F40 (VADJ), J10.G39 (VADJ), J10.H40 (VADJ), J10.J39 (VIO_B_M2C), J10.K40 (VIO_B_M2C), L11.1, L12.1, R36.2, R37.2, R38.2, R39.2, R46.2, R49.2, R63.2, R64.2, R69.1, R70.1, R71.1, R75.1, R84.2, R85.2, S1.2, S2.2, TP11.TP, U1.5 (VCC), U2.1 (VCC), U3.4 (EN), U3.16 (VCC), U4.3 (VCC), U5.5 (V+), U6.5 (V+), U10.4 (OSS_SEL), U10.5 (OEN), U11.4 (OSS_SEL), U11.5 (OEN), U12.11 (VDD), U12.12 (VDD), U12.29 (VDD), U12.30 (VDD), U13.4 (VLOGIC), U14.1 (VDD), U14.2 (REFA), U16.49 (VDRIVE), U17.9 (VDD), U17.10 (VLOGIC), U17.15 (INDEP), U19.2 (MODE), U19.4 (EN), U19.5 (VIN), U24.A5 (VIN1), U24.A6 (VIN1), U24.A7 (VIN1), U24.B7 (RUN1), U24.K7 (RUN2), U24.L5 (VIN2), U24.L6 (VIN2), U24.L7 (VIN2)
+5V_AN: C61.2, C64.2, C71.2, C79.2, C83.1, C85.2, C86.2, C87.2, C92.2, C109.2, C110.2, L14.1, R1.2, TP1.TP, U13.28 (AVCC), U15.3 (EN), U15.4 (VIN), U16.6 (VCC), U16.15 (VCC), U16.30 (VCC), U16.71 (VCC)
+12V: C118.2, C130.2, C133.2, C134.2, J7.1, J7.26, J10.C35 (12P0V1), J10.C37 (12P0V2), R44.2, R45.2, TP12.TP, U18.A2 (VIN), U18.B3 (VIN), U18.D3 (VIN), U18.E2 (VIN)
+13V_AN: C8.2, C9.2, C10.2, C106.2, C107.2, L15.1, R2.2, TP2.TP, U7.11 (V+), U8.11 (V+), U9.11 (V+), U13.26 (AVDD)
+15V: C131.2, L17.2, L18.2, R82.1, U24.A1 (VOUT1P), U24.A2 (VOUT1P), U24.B1 (VOUT1P), U24.B2 (VOUT1P)
-13V_AN: C18.2, C19.2, C20.2, C101.2, C105.2, L16.1, R3.2, TP4.TP, U7.2 (V-), U7.PAD (V-), U8.2 (V-), U8.PAD (V-), U9.2 (V-), U9.PAD (V-), U13.6 (AVSS), U13.PAD (AVSS)
-15V: C132.1, L19.2, R83.1, U24.G1 (VOUT2N), U24.G2 (VOUT2N), U24.H1 (VOUT2N), U24.H2 (VOUT2N), U24.J2 (VOUT2N)
ADC_BUSY: J10.J12 (HA11_P), U16.67 (BUSY)
ADC_CONVST: J10.K13 (HA10_P), U16.68 (CONVST)
ADC_MISO_A: J10.K11 (HA06_N), U16.57 (DB12/SDOA)
ADC_MISO_B: J10.J10 (HA07_N), U16.56 (DB11/SDOB)
ADC_MOSI: J10.K10 (HA06_P), U16.55 (DB10/SDI)
ADC_SCLK: J10.J13 (HA11_N), U16.62 (SCLK/!RD)
ADDR0: J10.C27 (LA27_N), R84.1, S3.4
ADDR1: J10.C26 (LA27_P), R85.1, S3.3
AGND: C8.1, C9.1, C10.1, C18.1, C19.1, C20.1, C61.1, C64.1, C71.1, C79.1, C83.2, C85.1, C86.1, C87.1, C90.1, C92.1, C97.1, C101.1, C102.1, C103.1, C105.1, C106.1, C107.1, C109.1, C110.1, D1.C, D2.C, D3.A, J7.13, J7.14, R54.1, R59.C2, R59.C4, R59.C6, R59.C7, R60.C1, R60.C3, R60.C5, R60.C6, R60.C7, R60.C8, R61.C2, R61.C3, R61.C5, R61.C7, R62.C1, R62.C2, R62.C3, R62.C4, R62.C6, R62.C8, TP3.TP, U7.3 (GND), U8.3 (GND), U9.3 (GND), U13.10 (AGND), U13.20 (NIC), U13.23 (N0), U13.24 (N1), U13.25 (NIC), U13.29 (AGND), U13.31 (NIC), U15.2 (GND), U16.5 (AGND), U16.16 (AGND), U16.29 (AGND), U16.32 (REFGND), U16.34 (REFINOUTGND), U16.69 (REGGND), U16.72 (AGND)
AIN_AOUT0: J10.F11 (HA08_N), U9.15 (IN1)
AIN_AOUT1: J10.D11 (LA05_P), U9.6 (IN4)
AIN_AOUT2: J10.E12 (HA13_P), U9.7 (IN3)
AIN_AOUT3: J10.H10 (LA04_P), U9.14 (IN2)
AIN_AOUT4: J10.E18 (HA20_P), U8.15 (IN1)
AIN_AOUT5: J10.J9 (HA07_P), U8.6 (IN4)
AIN_AOUT6: J10.G10 (LA03_N), U8.7 (IN3)
AIN_AOUT7: J10.F17 (HA15_N), U8.14 (IN2)
AIN_AOUT8: J10.H20 (LA15_N), U7.7 (IN3)
AIN_AOUT9: J10.J18 (HA18_P), U7.14 (IN2)
AIN_AOUT10: J10.G19 (LA16_N), U7.6 (IN4)
AIN_AOUT11: J10.H19 (LA15_P), U7.15 (IN1)
AIO_0: J7.7, R59.C1, U9.16 (D1)
AIO_1: J7.20, R59.C3, U9.5 (D4)
AIO_2: J7.8, R59.C5, U9.8 (D3)
AIO_3: J7.21, R59.C8, U9.13 (D2)
AIO_4: J7.9, R60.C4, U8.16 (D1)
AIO_5: J7.22, R60.C2, U8.5 (D4)
AIO_6: J7.10, R62.C5, U8.8 (D3)
AIO_7: J7.23, R62.C7, U8.13 (D2)
AIO_8: J7.11, R61.C6, U7.8 (D3)
AIO_9: J7.24, R61.C8, U7.13 (D2)
AIO_10: J7.12, R61.C4, U7.5 (D4)
AIO_11: J7.25, R61.C1, U7.16 (D1)
AOUT0: U7.1 (S1), U13.32 (VOUT0)
AOUT1: U7.4 (S4), U13.33 (VOUT1)
AOUT2: U7.9 (S3), U13.34 (VOUT2)
AOUT3: U7.12 (S2), U13.35 (VOUT3)
AOUT4: U8.1 (S1), U13.36 (VOUT4)
AOUT5: U8.4 (S4), U13.37 (VOUT5)
AOUT6: U8.12 (S2), U13.38 (VOUT6)
AOUT7: U8.9 (S3), U13.39 (VOUT7)
AOUT8: U9.9 (S3), U13.12 (VOUT8)
AOUT9: U9.12 (S2), U13.13 (VOUT9)
AOUT10: U9.4 (S4), U13.14 (VOUT10)
AOUT11: U9.1 (S1), U13.15 (VOUT11)
CAN_N: R27.2, SJ1.2, U4.6 (CANL)
CAN_P: R26.2, SJ2.2, U4.7 (CANH)
CAN_RX: J10.K8 (HA02_N), U4.4 (RXD)
CAN_TX: J10.K7 (HA02_P), U4.1 (TXD)
CLKIN0: J10.D21 (LA17_N_CC), TP7.TP, U5.1 (OUT)
CLKIN1: J10.E19 (HA20_N), TP6.TP, U6.1 (OUT)
CLKIN_TERM0: J10.K19 (HA21_P), R20.1
CLKIN_TERM1: J10.K17 (HA17_N_CC), R21.1
CLKIN_VBIAS_SCL: J10.J21 (HA22_P), R64.1, U14.7 (SCL)
CLKIN_VBIAS_SDA: J10.K20 (HA21_N), R63.1, U14.8 (SDA)
CLKOUT: J10.D20 (LA17_P_CC), U1.1 (IN3), U1.3 (IN2)
DAC_MISO: J10.K16 (HA17_P_CC), U13.9 (MISO)
DAC_MOSI: J10.H14 (LA07_N), U13.5 (MOSI)
DAC_MUX: TP15.TP, U13.27 (MUX_OUT)
DAC_SCLK: J10.J15 (HA14_P), U13.7 (SCLK)
DEBUG0: J8.2, J10.C10 (LA06_P)
DEBUG1: J8.4, J10.C11 (LA06_N)
DEBUG2: J8.6, J10.D14 (LA09_P)
DEBUG3: J8.8, J10.C14 (LA10_P)
DEBUG4: J8.10, J10.D15 (LA09_N)
DEBUG5: J8.12, J10.C15 (LA10_N)
DEBUG6: J8.14, J10.C18 (LA14_P)
DEBUG7: J8.16, J10.C19 (LA14_N)
DES_A_D0: J10.F34 (HB16_P), U11.24 (ROUT0)
DES_A_D1: J10.K35 (HB14_N), U11.23 (ROUT1)
DES_A_D2: J10.J34 (HB15_N), U11.22 (ROUT2)
DES_A_D3: J10.K34 (HB14_P), U11.21 (ROUT3)
DES_A_D4: J10.E33 (HB19_P), U11.19 (ROUT4)
DES_A_D5: J10.J33 (HB15_P), U11.18 (ROUT5)
DES_A_D6: J10.F32 (HB12_N), U11.16 (ROUT6)
DES_A_D7: J10.E31 (HB13_N), U11.15 (ROUT7)
DES_A_D8: J10.K32 (HB10_N), U11.14 (ROUT8)
DES_A_D9: J10.F31 (HB12_P), U11.13 (ROUT9)
DES_A_D10: J10.J31 (HB11_N), U11.12 (ROUT10)
DES_A_D11: J10.K31 (HB10_P), U11.11 (ROUT11)
DES_A_GPIO0: J10.J37 (HB18_N), U11.28 (GPIO0)
DES_A_GPIO1: J10.K37 (HB17_P_CC), U11.27 (GPIO1)
DES_A_GPIO2: J10.J36 (HB18_P), U11.26 (GPIO2)
DES_A_GPIO3: J10.E34 (HB19_N), R49.1, U11.25 (GPIO3/INTB)
DES_A_HSYNC: J10.E30 (HB13_P), U11.10 (HSYNC)
DES_A_LEDG: J10.F28 (HB08_P), R53.2
DES_A_LOCK: J10.E27 (HB09_P), R48.2, R56.2, U11.48 (LOCK)
DES_A_PASS: J10.J28 (HB07_N), R51.2, R58.2, U11.47 (PASS)
DES_A_PCLK: J10.K28 (HB06_P_CC), U11.8 (PCLK)
DES_A_PDB: J10.F35 (HB16_N), U11.30 (PDB)
DES_A_SCL: J10.F29 (HB08_N), R37.1, U11.2 (SCL)
DES_A_SDA\: J10.E28 (HB09_N), R39.1, U11.1 (SDA)
DES_A_VSYNC: J10.J30 (HB11_P), U11.9 (VSYNC)
DES_B_D0: J10.H29 (LA24_N), U10.24 (ROUT0)
DES_B_D1: J10.H28 (LA24_P), U10.23 (ROUT1)
DES_B_D2: J10.G28 (LA25_N), U10.22 (ROUT2)
DES_B_D3: J10.G27 (LA25_P), U10.21 (ROUT3)
DES_B_D4: J10.D27 (LA26_N), U10.19 (ROUT4)
DES_B_D5: J10.D26 (LA26_P), U10.18 (ROUT5)
DES_B_D6: J10.H26 (LA21_N), U10.16 (ROUT6)
DES_B_D7: J10.G25 (LA22_N), U10.15 (ROUT7)
DES_B_D8: J10.H25 (LA21_P), U10.14 (ROUT8)
DES_B_D9: J10.D24 (LA23_N), U10.13 (ROUT9)
DES_B_D10: J10.G24 (LA22_P), U10.12 (ROUT10)
DES_B_D11: J10.D23 (LA23_P), U10.11 (ROUT11)
DES_B_GPIO0: J10.H32 (LA28_N), U10.28 (GPIO0)
DES_B_GPIO1: J10.G31 (LA29_N), U10.27 (GPIO1)
DES_B_GPIO2: J10.H31 (LA28_P), U10.26 (GPIO2)
DES_B_GPIO3: J10.G30 (LA29_P), R46.1, U10.25 (GPIO3/INTB)
DES_B_HSYNC\: J10.H23 (LA19_N), U10.10 (HSYNC)
DES_B_LEDG: J10.G21 (LA20_P), R52.2
DES_B_LOCK: J10.J22 (HA22_N), R47.2, R55.2, U10.48 (LOCK)
DES_B_PASS: J10.K22 (HA23_P), R50.2, R57.2, U10.47 (PASS)
DES_B_PCLK: J10.C22 (LA18_P_CC), U10.8 (PCLK)
DES_B_PDB: J10.G33 (LA31_P), U10.30 (PDB)
DES_B_SCL: J10.G22 (LA20_N), R36.1, U10.2 (SCL)
DES_B_SDA: J10.H22 (LA19_P), R38.1, U10.1 (SDA)
DES_B_VSYNC: J10.K23 (HA23_N), U10.9 (VSYNC)
DI_VBIAS0: R18.1, U14.3 (VOUT0)
DI_VBIAS1: R19.1, U14.4 (VOUT1)
DOUTP_F_A: C47.2, D5.C, J2.SIG (1), L2.2, R7.2
DOUTP_F_B: C46.2, D4.C, J1.SIG (1), L1.2, R6.2
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

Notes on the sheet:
FMC
NB: Input protection voltage ~4.6V
L2 is the smallest package size I could find that barely meets current saturation requriements. An 8x8mm device that is probably safer is the Bourns SRN8040TA series.
Power: ~1.3A DC at 12V; 15.6W. With 90% efficiency regulation to 5.5V at serializer, this translates to 2.55A available, which is enough for 1A/LED + 500 mA serializer and FPGA.
DNP
NB: Use both MISO lines
NB: R-arrays provide input protection. Limit current thru internal clamp diodes to 10 mA at 20V.
NB: Worst case 100 mA draw from both ADC and DAC. With 10V stepdown, this is 1W dissipation.
ANALOG IO
CLK/TRIGGER I/0
NB: 3.48k = 11V output.
NB: VADJ must be set to 1.8V on host board!
NB: GA0 and GA1 define the LSBs of the EEPROM I2C address. We use 0x1010000
NB: FMC FRU module. Required by FMC standard.
Quad 1
Quad 2
Quad 3
NB: For best performance, quads should only be input or output, not mixtures.
TP1
TP2
TP3
TP4
TP5
NB: VLINK adjust. - Max step down ratio: 1 - (45e-9 *1.48e6) = 0.933 - So max voltage = 11.19 - Linear mode selected - R_AW = 0 : VLINK = 11.0V - R_AW = 5k : VLINK = 5.0V - General: VLINK = 36.24k/(3.48k + R_AW) + 0.6
NB: Default VBIAS = 1.65V
LINK A
LINK POWER
ANALOG POWER
LINK B
CLK IN 0
CLK IN 1
CLK OUT
FMC IO
HPC FMC
INTERNAL CLK/TRIG
SYNC
NB: Board address
NB: P,N order matches SDR datasheet spec.
NB: DC signals so no worries about DGND
NB: TO CC Pin



Board: 6 copper layers, 76.5 x 69.0 mm, 321 parts (174 on the bottom side), 306 nets.

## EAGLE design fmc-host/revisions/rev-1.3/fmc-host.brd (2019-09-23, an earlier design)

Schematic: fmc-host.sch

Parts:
AUX: 12226-8250-00FR; 12226-82X0-00XX
C1, C2, C47, C52, C57, C63, C85, C86, C94, C95, C99, C101, C102, C107, C109, C110, C111, C112, C113, C117, C118, C119: 10uF; 0805
C3, C4, C25, C26, C50, C51, C55, C56, C58, C59, C61, C62, C68, C73, C74, C81, C82, C90, C91, C114, C115, C116: 10nF; 0402
C5, C6, C12, C13, C14, C15, C16, C17, C18, C19, C20, C21, C22, C23, C24, C31, C32, C33, C34, C35, C36, C39, C42, C43, C44, C45, C46, C53, C54, C64, C65, C66, C71, C72, C75, C76, C77, C79, C80, C83, C87, C88, C92, C93, C96, C97, C98, C100, C103, C104, C105, C108, C123, C124, C125, C127, C128, C130, C131: 0.1uF; 0402
C7, C29, C30: 4.7nF; 0402
C8, C9, C10, C11, C27, C28, C37, C38, C48, C49, C67, C69, C70, C132, C133: 4.7uF; 1206
C40, C41: 47nF; 0402
C60, C78: 1uF; 0805
C84, C89, C120, C121, C122, C126, C129: 47uF; 1210
C106: 100pF; 0402
CLKI0, CLKI1: SMA002; MMCX-THRU
CLKO: SMA002; MMCX-THRU
D1, D2, D3: LED_0402; LED-0402
D4, D5: SESD0402X1UN-0020-090; 0402P-DFN
D6, D7, D8: BAR66; SOT23
D9: KDZ4.3B; SOD123
D10, D11: APFA3011-AK13/F; RGB_LED_SMD-6
F1, F2, F3: C014F-2; 1812
J6: PINHD-2X5_ESHF-SM; ESHF-105-01-L-D-SM-K-TR
J8: PINHD-2X8_SMD; JP2X8_SMD
J9: FMC_SINGLE_WIDTH_MODULE
J10: ASP-134488-01; FMC_HPC_MALE
L1, L2: 1008PS-472; 1008PS
L3, L4, L7, L8, L11, L12: BLM18KG601SN1D; 0603
L5, L6: SRNxx-101M; SRN6045TA
L9, L10: MPZ2012S102AT000; 0805
L13, L14, L15, L16, L17, L18: BLM15PX601SN1D; 0402; PARTNO BLM15PX601SN1D
LINKA: SMA002; MMCX-THRU
LINKB: SMA002; MMCX-THRU
Q1, Q2, Q3, Q4: SI1012R; SC75
R1: 1.6k; 0402
R2, R3: 3.9k; 0402
R4, R5, R29, R31, R45, R56, R61: 3k; 0402
R6, R7, R24, R25, R28, R30, R39, R40, R41, R42, R43, R44, R74, R79, R80, R81, R83, R84, R95, R96: 10k; 0402
R8, R9, R10, R11, R18, R19, R26, R27, R48, R49, R50, R51, R62, R63, R64, R65, R66, R67: 1k; 0402
R12, R13, R22, R23, R93: 165k; 0402
R14, R15, R16, R17, R20, R21: 150,0.25W; 0603
R32, R33: 60 1%; 0402
R34, R35, R46, R47: 49.9; 0402
R36, R37, R38: 100; 0402
R52, R54, R57, R59: DNP; 0402
R53, R55, R58, R60, R78, R82: 0; 0402
R68, R69, R70, R71: 2.2k; RN2X8-1506
R72, R73, R91, R92: 2k; 0402
R75, R76: 3.16k; 0402
R77: 649k; 0402
R85: 15k; 0402
R86, R88, R90: 4.7k; 0402
R87, R89: 43k; 0402
R94: 178k; 0402
R97, R98: 73.2k; 0402
S1, S2: CHS-01TA; DIP01-SMD-GULL
S3: CHS-02TB
SJ1, SJ2: SJ2_0201; SJ_2_0201
TP1, TP2, TP4, TP5, TP6, TP7, TP11, TP12, TP13, TP14, TP15, TP16: TPB1,27; B1,27
TP3, TP8, TP9, TP10, TP17, TP18: TPB2,54; B2,54
U1: NC7WZ07P6X; SC70
U2: SN65LVDS9638DGN; MSOP-8-PAD-3X3
U3: FIN1032MTCX; TSSOP-16
U4: LTC2875_DFN; DFN83X3
U5, U6: ADCMP600; SOT-23-5
U7, U8, U9: ADG1434YCPZ; QFN20-4X4MM
U10, U11: DS90UB914A-Q1; WQFN48-7.4X7.4
U12: DS91M040; WQFN32-5X5
U13: AD5766BCPZ-RL7; CP_40_7
U14: MCP47FEB02A0-E/ST; TSSOP-8
U15: LM4132AMF-2.5/NOPBCT-ND; SOT-23-5
U16: AD7617BSTZ; ST_80_2
U17: AD5142BCPZ10; CP_16_27-L
U18: LTM4622A; BGA_5X5_625X625
U19, U20: TPS7A49; PVSON-N8+4-3X3
U21: TPS7A30; PVSON-N8+4-3X3
U22: 24AA64ST; TSSOP8
U23: LTM8049_BGA; LTM8049
X2, X3: OE-LOGO_7X5; OE-LOGO-7X5

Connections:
!ADC_CS: J10.H13 (LA07_P), U16.63 (!CS)
!ADC_RESET: C106.1, J10.F10 (HA08_P), R81.2, U16.36 (!RESET)
!AIN_AOUT_EN: J10.J19 (HA18_N), U7.18 (!EN), U8.18 (!EN), U9.18 (!EN)
!DAC_CS: J10.J16 (HA14_N), U13.8 (!CS)
!DAC_RESET: J10.F14 (HA12_N), U13.3 (!RESET)
!LINK_PWR_ADJ_CS: J10.F38 (HB20_N), U17.14 (!CS)
!LINK_PWR_ADJ_RESET: J10.E37 (HB21_N), U17.16 (!RESET)
$N1: D8.3 (COMM), F2.2, R5.2, R15.2, R17.2, R21.2, R35.1
$N2: D6.3 (COMM), F3.2, U1.4 (OUT2), U1.6 (OUT1)
$N3: D7.3 (COMM), F1.2, R4.2, R14.2, R16.2, R20.2, R34.1
+1V8: C73.2, C74.2, C76.2, C77.2, C81.2, C82.2, C87.2, C88.2, C90.2, C91.2, C96.2, C97.2, C129.2, C130.2, C131.2, J10.E39 (VADJ), J10.F40 (VADJ), J10.G39 (VADJ), J10.H40 (VADJ), L3.2, L4.2, L7.2, L8.2, L11.1, L12.1, R28.1, R30.1, R52.1, R54.1, R57.1, R59.1, TP16.TP, U10.3 (VDDSSCG), U10.17 (VDDD), U10.36 (VDDR), U11.3 (VDDSSCG), U11.17 (VDDD), U11.36 (VDDR)
+3V3: C15.2, C23.1, C24.1, C29.1, C30.1, C35.1, C36.1, C39.1, C45.2, C46.2, C50.2, C51.2, C55.2, C56.2, C60.2, C61.2, C62.2, C64.2, C65.2, C66.2, C68.2, C69.2, C70.2, C79.2, C83.2, C86.2, C104.2, C107.2, C108.2, C110.2, C126.2, C127.2, C128.2, C132.1, C133.1, J10.C39 (3P3V1), J10.D36 (3P3V2), J10.D38 (3P3V3), J10.D40 (3P3V4), R6.1, R7.1, R41.2, R42.2, R43.2, R44.2, R48.2, R49.2, R50.2, R51.2, R72.2, R73.2, R78.1, R79.1, R80.1, R81.1, R95.2, R96.2, S1.2, S2.2, TP11.TP, U1.5 (VCC), U2.1 (VCC), U3.4 (EN), U3.16 (VCC), U4.3 (VCC), U5.5 (V+), U6.5 (V+), U10.7 (VDDIO3), U10.20 (VDDIO2), U10.29 (VDDIO1), U11.7 (VDDIO3), U11.20 (VDDIO2), U11.29 (VDDIO1), U12.11 (VDD), U12.12 (VDD), U12.29 (VDD), U12.30 (VDD), U13.4 (VLOGIC), U14.1 (VDD), U14.2 (REFA), U16.49 (VDRIVE), U17.9 (VDD), U17.10 (VLOGIC), U17.15 (INDEP), U23.A5 (VIN1), U23.A6 (VIN1), U23.A7 (VIN1), U23.B7 (RUN1), U23.K7 (RUN2), U23.L5 (VIN2), U23.L6 (VIN2), U23.L7 (VIN2)
+5V_AN: C47.2, C52.2, C57.2, C63.2, C67.1, C71.2, C72.2, C75.2, C80.2, C100.2, C101.2, L13.1, R1.2, TP1.TP, U13.28 (AVCC), U15.3 (EN), U15.4 (VIN), U16.6 (VCC), U16.15 (VCC), U16.30 (VCC), U16.71 (VCC)
+12V: AUX.1, AUX.26, C109.2, C120.2, C123.2, C124.2, J10.C35 (12P0V1), J10.C37 (12P0V2), R56.2, R61.2, TP12.TP, U18.A2 (VIN), U18.B3 (VIN), U18.D3 (VIN), U18.E2 (VIN)
+13V_AN: C12.2, C13.2, C14.2, C98.2, C99.2, L14.1, R2.2, TP2.TP, U7.13 (V+), U8.13 (V+), U9.13 (V+), U13.26 (AVDD)
+15V: C121.2, L16.2, L17.2, R93.1, U23.A1 (VOUT1P), U23.A2 (VOUT1P), U23.B1 (VOUT1P), U23.B2 (VOUT1P)
-13V_AN: C20.2, C21.2, C22.2, C92.2, C95.2, L15.1, R3.2, TP4.TP, U7.3 (V-), U7.PAD (V-), U8.3 (V-), U8.PAD (V-), U9.3 (V-), U9.PAD (V-), U13.6 (AVSS), U13.PAD (AVSS)
-15V: C122.1, L18.2, R94.1, U23.G1 (VOUT2N), U23.G2 (VOUT2N), U23.H1 (VOUT2N), U23.H2 (VOUT2N), U23.J2 (VOUT2N)
ADC_BUSY: J10.J12 (HA11_P), U16.67 (BUSY)
ADC_CONVST: J10.K13 (HA10_P), U16.68 (CONVST)
ADC_MISO_A: J10.K11 (HA06_N), U16.57 (DB12/SDOA)
ADC_MISO_B: J10.J10 (HA07_N), U16.56 (DB11/SDOB)
ADC_MOSI: J10.K10 (HA06_P), U16.55 (DB10/SDI)
ADC_SCLK: J10.J13 (HA11_N), U16.62 (SCLK/!RD)
ADDR0: J10.C27 (LA27_N), R95.1, S3.4
ADDR1: J10.C26 (LA27_P), R96.1, S3.3
AGND: AUX.13, AUX.14, C12.1, C13.1, C14.1, C20.1, C21.1, C22.1, C47.1, C52.1, C57.1, C63.1, C67.2, C71.1, C72.1, C75.1, C78.1, C80.1, C85.1, C92.1, C93.1, C94.1, C95.1, C98.1, C99.1, C100.1, C101.1, D1.C, D2.C, D3.A, R68.C2, R68.C4, R68.C6, R68.C7, R69.C1, R69.C3, R69.C5, R69.C6, R69.C7, R69.C8, R70.C2, R70.C3, R70.C5, R70.C7, R71.C1, R71.C2, R71.C3, R71.C4, R71.C6, R71.C8, R82.1, TP3.TP, U7.4 (GND), U8.4 (GND), U9.4 (GND), U13.10 (AGND), U13.20 (NIC), U13.23 (N0), U13.24 (N1), U13.25 (NIC), U13.29 (AGND), U13.31 (NIC), U15.2 (GND), U16.5 (AGND), U16.16 (AGND), U16.29 (AGND), U16.32 (REFGND), U16.34 (REFINOUTGND), U16.69 (REGGND), U16.72 (AGND)
AINA0: R68.C1, U9.20 (S1A)
AINA1: R68.C3, U9.7 (S2A)
AINA2: R68.C5, U9.10 (S3A)
AINA3: R68.C8, U9.16 (S4A)
AINA4: R69.C2, U8.7 (S2A)
AINA5: R69.C4, U8.20 (S1A)
AINB0: R70.C8, U7.16 (S4A)
AINB1: R70.C6, U7.10 (S3A)
AINB2: R70.C4, U7.7 (S2A)
AINB3: R70.C1, U7.20 (S1A)
AINB4: R71.C7, U8.16 (S4A)
AINB5: R71.C5, U8.10 (S3A)
AIN_AOUT0: J10.H19 (LA15_P), U7.19 (IN1)
AIN_AOUT1: J10.G19 (LA16_N), U7.8 (IN2)
AIN_AOUT2: J10.H20 (LA15_N), U7.9 (IN3)
AIN_AOUT3: J10.J18 (HA18_P), U7.17 (IN4)
AIN_AOUT4: J10.E18 (HA20_P), U8.19 (IN1)
AIN_AOUT5: J10.J9 (HA07_P), U8.8 (IN2)
AIN_AOUT6: J10.G10 (LA03_N), U8.9 (IN3)
AIN_AOUT7: J10.F17 (HA15_N), U8.17 (IN4)
AIN_AOUT8: J10.F11 (HA08_N), U9.19 (IN1)
AIN_AOUT9: J10.D11 (LA05_P), U9.8 (IN2)
AIN_AOUT10: J10.E12 (HA13_P), U9.9 (IN3)
AIN_AOUT11: J10.H10 (LA04_P), U9.17 (IN4)
AIO_0: AUX.25, U7.1 (D1)
AIO_1: AUX.12, U7.6 (D2)
AIO_2: AUX.24, U7.15 (D4)
AIO_3: AUX.11, U7.11 (D3)
AIO_4: AUX.23, U8.15 (D4)
AIO_5: AUX.10, U8.11 (D3)
AIO_6: AUX.22, U8.6 (D2)
AIO_7: AUX.9, U8.1 (D1)
AIO_8: AUX.21, U9.15 (D4)
AIO_9: AUX.8, U9.11 (D3)
AIO_10: AUX.20, U9.6 (D2)
AIO_11: AUX.7, U9.1 (D1)
AOUT0: U7.2 (S1B), U13.32 (VOUT0)
AOUT1: U7.5 (S2B), U13.33 (VOUT1)
AOUT2: U7.12 (S3B), U13.34 (VOUT2)
AOUT3: U7.14 (S4B), U13.35 (VOUT3)
AOUT4: U8.2 (S1B), U13.36 (VOUT4)
AOUT5: U8.5 (S2B), U13.37 (VOUT5)
AOUT6: U8.14 (S4B), U13.38 (VOUT6)
AOUT7: U8.12 (S3B), U13.39 (VOUT7)
AOUT8: U9.12 (S3B), U13.12 (VOUT8)
AOUT9: U9.14 (S4B), U13.13 (VOUT9)
AOUT10: U9.5 (S2B), U13.14 (VOUT10)
AOUT11: U9.2 (S1B), U13.15 (VOUT11)
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

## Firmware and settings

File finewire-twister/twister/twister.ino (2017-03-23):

#include <AccelStepper.h>

// Microstepper driver connections
#define M0 5
#define M1 6
#define M2 7
#define STEP 10
#define DIR 11

// Button input
#define TRIG 2

// Hardcoded number of steps in the motor I'm using
#define STEPS_PER_REV 200

AccelStepper stepper(1, STEP, DIR);
long num_turns = 100;
long usteps = 0;
volatile bool moving = false;
volatile bool state_change = false;
const int led = LED_BUILTIN; 

void setup(void) {
  Serial.begin(9600);

  // Microsteps (set to 16)
  pinMode(M0, OUTPUT);
  pinMode(M1, OUTPUT);
  pinMode(M2, OUTPUT);

  // Trigger button
  pinMode(TRIG, INPUT);
  attachInterrupt(0, trigPressed, RISING);

  configureParameters(true);
}

void loop(void) {

  if (state_change && moving) {
    // Stop moton
    stepper.setCurrentPosition(0);
    state_change = false;
    moving = false;
    digitalWrite(LED_BUILTIN, LOW);
    Serial.println("Stopping motion");
  } else if (state_change) {
    Serial.println(getNumSteps());
    stepper.move(getNumSteps());
    state_change = false;
    moving = true;
    digitalWrite(LED_BUILTIN, HIGH);
    Serial.println("Starting motion");
  }

  if (stepper.distanceToGo() != 0) {
    stepper.run();
  } else {
    moving = false;
  }

  if (!moving && Serial.available()) {
    int temp = Serial.parseInt();
    if (temp != 0) {
      num_turns = temp;
      Serial.print("Target turns set to ");
      Serial.println(num_turns);
    }
  }
}

int configureParameters(bool init) {

  if (init) {

      // Set number of microsteps
      usteps = setUStep(usteps);

      // Set max stepper speed in turns/sec
      double max_speed = 500;
      stepper.setMaxSpeed(max_speed);
      stepper.setAcceleration(max_speed/5);
  }
}

int setUStep(int us) {

  switch (us) {
  case 0: {
    digitalWrite(M0, LOW);
    digitalWrite(M1, LOW);
    digitalWrite(M2, LOW);
    Serial.println("Set to no microsteps");
    return 1;
  }
  case 8: {
    digitalWrite(M0, HIGH);
    digitalWrite(M1, HIGH);
    digitalWrite(M2, LOW);
    Serial.println("Set to 8 microsteps");
    return 8;
  }
  case 16: {
    digitalWrite(M0, LOW);
    digitalWrite(M1, LOW);
    digitalWrite(M2, HIGH);
    Serial.println("Set to 16 microsteps");
    return 32;
  }
  case 32: {
    digitalWrite(M0, HIGH);
    digitalWrite(M1, HIGH);
    digitalWrite(M2, HIGH);
    Serial.println("Set to 32 microsteps");
    return 32;
  }
  default: {
    digitalWrite(M0, LOW);
    digitalWrite(M1, LOW);
    digitalWrite(M2, LOW);
    Serial.println("Invalid selection. Set to no microsteps");
    return 1;
  }
  }
}

void trigPressed() { state_change = true; }
long getNumSteps() { return usteps * STEPS_PER_REV * num_turns; }

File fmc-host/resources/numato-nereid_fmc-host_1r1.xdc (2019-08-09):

####################################################################################################################
#                                               CLOCK 100MHz                                                       #
####################################################################################################################
set_property -dict { PACKAGE_PIN "F22"    IOSTANDARD LVCMOS33   SLEW FAST} [get_ports { CLK1 }]     ;                           # IO_L12P_T1_MRCC_14            Sch = CLK1

set_property -dict { PACKAGE_PIN "D23"    IOSTANDARD LVCMOS33   SLEW FAST} [get_ports { CLK_DIR }]  ;                           # IO_L11P_T1_SRCC_14            Sch = CLK_DIR

####################################################################################################################
#                                              150MHz LVDS Oscillator                                              #
####################################################################################################################
set_property -dict { PACKAGE_PIN "G24"    IOSTANDARD TMDS_33   SLEW FAST} [get_ports { CLK2_P }]     ;                          # IO_L14P_T2_SRCC_14            Sch = CLK2_P
set_property -dict { PACKAGE_PIN "F24"    IOSTANDARD TMDS_33   SLEW FAST} [get_ports { CLK2_N }]     ;                          # IO_L14N_T2_SRCC_14            Sch = CLK2_N

####################################################################################################################
#                                       RESET - SW2 & FAN PWM                                                      #
####################################################################################################################
set_property -dict { PACKAGE_PIN "C26"    IOSTANDARD LVCMOS33   SLEW FAST   PULLDOWN True} [get_ports { RESET }]    ;           # IO_L5N_T0_D07_14              Sch = RESET
set_property -dict { PACKAGE_PIN "J25"    IOSTANDARD LVCMOS33   SLEW FAST   PULLDOWN True} [get_ports { FAN_PWM }]  ;           # IO_L22N_T3_A04_D20_14         Sch = FAN_PWM

####################################################################################################################
#                                               ADC                                                                #
####################################################################################################################
set_property -dict { PACKAGE_PIN "B16"    IOSTANDARD LVCMOS33   SLEW FAST} [get_ports { ADC_A_N[0] }]   ;                       # IO_L1N_T0_AD0N_15             Sch = ADC_A0_N
set_property -dict { PACKAGE_PIN "C16"    IOSTANDARD LVCMOS33   SLEW FAST} [get_ports { ADC_A_P[0] }]   ;                       # IO_L1P_T0_AD0P_15             Sch = ADC_A0_P
set_property -dict { PACKAGE_PIN "A19"    IOSTANDARD LVCMOS33   SLEW FAST} [get_ports { ADC_A_N[1] }]   ;                       # IO_L2N_T0_AD8N_15             Sch = ADC_A1_N
set_property -dict { PACKAGE_PIN "A18"    IOSTANDARD LVCMOS33   SLEW FAST} [get_ports { ADC_A_P[1] }]   ;                       # IO_L2P_T0_AD8P_15             Sch = ADC_A1_P
set_property -dict { PACKAGE_PIN "A17"    IOSTANDARD LVCMOS33   SLEW FAST} [get_ports { ADC_A_N[2] }]   ;                       # IO_L3N_T0_DQS_AD1N_15         Sch = ADC_A2_N
set_property -dict { PACKAGE_PIN "B17"    IOSTANDARD LVCMOS33   SLEW FAST} [get_ports { ADC_A_P[2] }]   ;                       # IO_L3P_T0_DQS_AD1P_15         Sch = ADC_A2_P
set_property -dict { PACKAGE_PIN "N11"    IOSTANDARD LVCMOS33   SLEW FAST} [get_ports { ADC_VREF_N }]   ;                       # VREFN_0                       Sch = ADC_VREF_N
set_property -dict { PACKAGE_PIN "P12"    IOSTANDARD LVCMOS33   SLEW FAST} [get_ports { ADC_VREF_P }]   ;                       # VREFP_0                       Sch = ADC_VREF_P
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

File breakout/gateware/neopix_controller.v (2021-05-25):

// NB: colors.mem was generated using colors.py. There are lots of hardcoded
// constants in here that would need to be changed if the number of colors or
// their order is altered

`include "./ws2811/ws2811.v"

module neopix_controller # (
    parameter CLK_RATE_HZ = 50_000_000
) (
    // Clock and reset
    input   wire            i_clk,
    input   wire            i_reset,

    // Derived from host to breakout slow word
    input   wire            i_acq_running,
    input   wire            i_acq_reset_done,
    input   wire    [3:0]   i_ledlevel,
    input   wire    [1:0]   i_ledmode,
    input   wire    [1:0]   i_porta_status,
    input   wire    [1:0]   i_portb_status,
    input   wire    [1:0]   i_portc_status,
    input   wire    [1:0]   i_portd_status,
    input   wire    [11:0]  i_aio_dir,
    input   wire    [1:0]   i_harp_conf, // TODO
    input   wire    [15:0]  i_gpio_dir,  // TODO

    // Link power
    input   wire    [3:0]   i_link_pow,

    // HARP heartbeat
    input   wire            i_harp_hb,

    // Button press state
    input   wire    [5:0]   i_button,

    // Digital IO
    input   wire    [7:0]   i_din_state,
    input   wire    [7:0]   i_dout_state,

    // Neopixel control signal
    output  wire            o_neopix
);

// Colors
reg [23:0] off,
           blue,
           orange,
           green,
           red,
           purple,
           brown ,
           pink ,
           white ,
           yellow,
           cyan;

// NB: This is hardcoded for the particular color set generated by colors.py
reg [23:0] colors [0:159];
reg [7:0] color_addr;
reg [3:0] color_idx, color_idx_last;
reg [23:0] color;

// Initialize RAM (produced by colors.py)
initial $readmemh("colors.mem", colors);
initial off = 0;

// RAM address
always @ (posedge i_clk) begin

    color_idx_last <= color_idx;

    if (i_reset) begin
        color_addr <= 0;
        color_idx <= 0;
    end else if (color_idx == 0) begin
        color_addr <= 144 + {4'b0000, i_ledlevel};
        color_idx <= 9;
    end else begin
        color_addr <= color_addr - 16;
        color_idx <= color_idx - 1;
    end
end

// RAM access
always @ (posedge i_clk) begin
    color <= colors[color_addr];
end

// Color update
always @ (posedge i_clk) begin
    case (color_idx_last)
        0: blue <= color;
        1: orange <= color;
        2: green <= color;
        3: red <= color;
        4: purple <= color;
        5: brown <= color;
        6: pink <= color;
        7: white <= color;
        8: yellow <= color;
        9: cyan <= color;
    endcase
end

// Neopixel color state
reg [23:0] rgb [0:40];

// LED use levels
reg dark = 1'b0;
reg [1:0] button0_history = 2'b00;

always @ (posedge i_clk) begin

    button0_history <= {button0_history[0], i_button[0]};

    if (button0_history == 2'b01) begin
        dark <= dark + 1;
    end
end

// Port-specific running indicators
reg [3:0] port_running = 4'b0000;
reg [3:0] port_failed = 4'b0000;
reg last_acq_running = 1'b0;

always @ (posedge i_clk) begin

    last_acq_running <= i_acq_running;

    // NB: Internal, port-specific running flag only changes on running start,
    // stop, or loss of lock or power
    if (!last_acq_running && i_acq_running) begin

        port_running <= {i_porta_status == 2'b11,
                         i_portb_status == 2'b11,
                         i_portc_status == 2'b11,
                         i_portd_status == 2'b11};
        port_failed <= 4'b0;

    end else if(!i_acq_running) begin

        port_running <= 4'b0;
        port_failed <= 4'b0;

    end else begin

        // Requires !i_acq_running to reset latch
        port_failed <= {port_failed[3] || (port_running[3] && i_porta_status != 2'b11),
                        port_failed[2] || (port_running[2] && i_portb_status != 2'b11),
                        port_failed[1] || (port_running[1] && i_portc_status != 2'b11),
                        port_failed[0] || (port_running[0] && i_portd_status != 2'b11)};
    end
end

wire leds_on = ~dark;

// LED color logic
always @ (*) begin

    rgb[0] = leds_on ? yellow : off;

    rgb[1] = leds_on ?
            (i_acq_reset_done ?
            (i_acq_running ?
            (i_harp_hb ?
            red : off) : red) : purple) : off;

    rgb[2] = (leds_on & i_button[5]) ? yellow : off;
    rgb[3] = (leds_on & i_button[4]) ? yellow : off;
    rgb[4] = (leds_on & i_button[3]) ? yellow : off;
    rgb[5] = (leds_on & i_button[2]) ? yellow : off;
    rgb[6] = (leds_on & i_button[1]) ? yellow : off;

    rgb[7] = off; // TODO: "Host"
    rgb[8] = (leds_on & i_harp_hb) ? red : off;

    rgb[9]  = (leds_on & i_din_state[0]) ? blue : off;
    rgb[10] = (leds_on & i_din_state[1]) ? blue : off;
    rgb[11] = (leds_on & i_din_state[2]) ? blue : off;
    rgb[12] = (leds_on & i_din_state[3]) ? blue : off;
    rgb[13] = (leds_on & i_din_state[4]) ? blue : off;
    rgb[14] = (leds_on & i_din_state[5]) ? blue : off;
    rgb[15] = (leds_on & i_din_state[6]) ? blue : off;
    rgb[16] = (leds_on & i_din_state[7]) ? blue : off;

    rgb[17] = (leds_on & i_dout_state[7]) ? blue : off;
    rgb[18] = (leds_on & i_dout_state[6]) ? blue : off;
    rgb[19] = (leds_on & i_dout_state[5]) ? blue : off;
    rgb[20] = (leds_on & i_dout_state[4]) ? blue : off;
    rgb[21] = (leds_on & i_dout_state[3]) ? blue : off;
    rgb[22] = (leds_on & i_dout_state[2]) ? blue : off;
    rgb[23] = (leds_on & i_dout_state[1]) ? blue : off;
    rgb[24] = (leds_on & i_dout_state[0]) ? blue : off;

    // NB: These if statements make heavy use of decending case priority
    // encoding

    // Port A (HS3 on the board)
    if (!leds_on || i_porta_status == 2'b00)            // Dark or power off
        rgb[25] = off;
    else if (port_failed[3])                            // Link issue in the middle of acquisition
        rgb[25] = orange;
    else if (port_running[3])                           // Acquisition running
        rgb[25] = i_harp_hb ? red : off;
    else if (i_porta_status != 2'b01)                   // Locked
        rgb[25] = purple;
    else if (i_link_pow[3] && i_porta_status == 2'b01)  // Power on, waiting for lock
        rgb[25] = green;
    else
        rgb[25] = off;

    // Port B (HS2 on the board)
    if (!leds_on || i_portb_status == 2'b00)            // Dark or power off
        rgb[26] = off;
    else if (port_failed[2])                            // Link issue in the middle of acquisition
        rgb[26] = orange;
    else if (port_running[2])                           // Acquisition running
        rgb[26] = i_harp_hb ? red : off;
    else if (i_portb_status != 2'b01)                   // Locked
        rgb[26] = purple;
    else if (i_link_pow[2] && i_portb_status == 2'b01)  // Power on, waiting for lock
        rgb[26] = green;
    else
        rgb[26] = off;
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

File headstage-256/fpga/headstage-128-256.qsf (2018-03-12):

# -------------------------------------------------------------------------- #
#
# Copyright (C) 2017  Intel Corporation. All rights reserved.
# Your use of Intel Corporation's design tools, logic functions 
# and other software and tools, and its AMPP partner logic 
# functions, and any output files from any of the foregoing 
# (including device programming or simulation files), and any 
# associated documentation or information are expressly subject 
# to the terms and conditions of the Intel Program License 
# Subscription Agreement, the Intel Quartus Prime License Agreement,
# the Intel FPGA IP License Agreement, or other applicable license
# agreement, including, without limitation, that your use is for
# the sole purpose of programming logic devices manufactured by
# Intel and sold by Intel or its authorized distributors.  Please
# refer to the applicable agreement for further details.
#
# -------------------------------------------------------------------------- #
#
# Quartus Prime
# Version 17.1.0 Build 590 10/25/2017 SJ Lite Edition
# Date created = 08:37:01  February 08, 2018
#
# -------------------------------------------------------------------------- #
#
# Notes:
#
# 1) The default values for assignments are stored in the file:
#		headstage-128-256_assignment_defaults.qdf
#    If this file doesn't exist, see file:
#		assignment_defaults.qdf
#
# 2) Altera recommends that you do not modify this file. This
#    file is updated automatically by the Quartus Prime software
#    and any changes you make may be lost or overwritten.
#
# -------------------------------------------------------------------------- #


set_global_assignment -name FAMILY "MAX 10"
set_global_assignment -name DEVICE 10M08SAM153I7G
set_global_assignment -name TOP_LEVEL_ENTITY headstage_128_256
set_global_assignment -name ORIGINAL_QUARTUS_VERSION 17.1.0
set_global_assignment -name PROJECT_CREATION_TIME_DATE "08:37:01  FEBRUARY 08, 2018"
set_global_assignment -name LAST_QUARTUS_VERSION "17.1.0 Lite Edition"
set_global_assignment -name PROJECT_OUTPUT_DIRECTORY output_files
set_global_assignment -name MIN_CORE_JUNCTION_TEMP "-40"
set_global_assignment -name MAX_CORE_JUNCTION_TEMP 100
set_global_assignment -name DEVICE_FILTER_PACKAGE MBGA
set_global_assignment -name DEVICE_FILTER_PIN_COUNT 153
set_global_assignment -name ERROR_CHECK_FREQUENCY_DIVISOR 256
set_global_assignment -name EDA_SIMULATION_TOOL "ModelSim-Altera (Verilog)"
set_global_assignment -name EDA_TIME_SCALE "1 ps" -section_id eda_simulation
set_global_assignment -name EDA_OUTPUT_DATA_FORMAT "VERILOG HDL" -section_id eda_simulation
set_location_assignment PIN_R3 -to rhd_miso_a
set_location_assignment PIN_L7 -to rhd_sclk_ac
set_location_assignment PIN_L6 -to "rhd_sclk_ac(n)"
set_location_assignment PIN_P15 -to rhd_miso_b
set_location_assignment PIN_R14 -to "rhd_miso_b(n)"
set_location_assignment PIN_R13 -to rhd_cs_bd
set_location_assignment PIN_P14 -to "rhd_cs_bd(n)"
set_location_assignment PIN_M9 -to rhd_sclk_bd
set_location_assignment PIN_L9 -to "rhd_sclk_bd(n)"
set_location_assignment PIN_M11 -to rhd_mosi_bd
set_location_assignment PIN_L10 -to "rhd_mosi_bd(n)"
set_location_assignment PIN_R9 -to rhd_miso_d
set_location_assignment PIN_P9 -to "rhd_miso_d(n)"
set_location_assignment PIN_M7 -to rhd_miso_c
set_location_assignment PIN_L8 -to "rhd_miso_c(n)"
set_location_assignment PIN_M5 -to rhd_cs_ac
set_location_assignment PIN_M4 -to "rhd_cs_ac(n)"
set_location_assignment PIN_P7 -to rhd_mosi_ac
set_location_assignment PIN_P6 -to "rhd_mosi_ac(n)"
set_location_assignment PIN_K5 -to sd_dat2
set_location_assignment PIN_L1 -to sd_cs
set_location_assignment PIN_L4 -to sd_mosi
set_location_assignment PIN_L5 -to sd_sclk
set_location_assignment PIN_N1 -to sd_miso
set_location_assignment PIN_P1 -to sd_irq
set_location_assignment PIN_J4 -to lh_env5
set_location_assignment PIN_J2 -to lh_data5
set_location_assignment PIN_R2 -to lh_env2
set_location_assignment PIN_P2 -to lh_data2
set_location_assignment PIN_C14 -to lH_data1
set_location_assignment PIN_C15 -to lh_env1
set_location_assignment PIN_D12 -to led_sin
set_location_assignment PIN_E11 -to led_clk
set_location_assignment PIN_E14 -to led_latch
set_location_assignment PIN_E15 -to potb_cs
set_location_assignment PIN_F11 -to lh_data6
set_location_assignment PIN_F12 -to lh_env6
set_location_assignment PIN_G11 -to exp18
set_location_assignment PIN_G12 -to exp17
set_location_assignment PIN_G15 -to exp16
set_location_assignment PIN_H11 -to exp15
set_location_assignment PIN_J11 -to dac_b_cs
set_location_assignment PIN_H12 -to stim_null_b
set_location_assignment PIN_K14 -to lh_data3
set_location_assignment PIN_K12 -to lh_env3
set_location_assignment PIN_J15 -to lh_data4
set_location_assignment PIN_J14 -to lh_env4
set_location_assignment PIN_J9 -to nrf_irq
set_location_assignment PIN_N14 -to nrf_cs
set_location_assignment PIN_N15 -to nrf_en
set_location_assignment PIN_M12 -to miso
set_location_assignment PIN_J12 -to mosi
set_location_assignment PIN_H13 -to sclk
set_location_assignment PIN_L11 -to sda
set_location_assignment PIN_K11 -to scl
set_location_assignment PIN_M14 -to status_a
set_location_assignment PIN_L15 -to status_b
set_location_assignment PIN_J5 -to stim_null_a
set_location_assignment PIN_H3 -to pota_cs
set_location_assignment PIN_G2 -to dac_a_cs
set_location_assignment PIN_K2 -to intan_en
set_location_assignment PIN_K4 -to estim_power_en
set_location_assignment PIN_B1 -to exp6
set_location_assignment PIN_C2 -to exp2
set_location_assignment PIN_C1 -to exp5
set_location_assignment PIN_D2 -to exp1
set_location_assignment PIN_E2 -to exp8
set_location_assignment PIN_E1 -to exp7
set_location_assignment PIN_F5 -to exp3
set_location_assignment PIN_G5 -to exp4
set_location_assignment PIN_R5 -to imu_int
set_location_assignment PIN_P4 -to imu_reset
set_location_assignment PIN_R7 -to exp9
set_location_assignment PIN_P8 -to exp10
set_location_assignment PIN_N8 -to exp13
set_location_assignment PIN_M8 -to exp11
set_location_assignment PIN_P12 -to exp14
set_location_assignment PIN_A2 -to lipo_alrt
set_location_assignment PIN_A3 -to lipo_qstrt
set_location_assignment PIN_B4 -to serdes_en
set_location_assignment PIN_A5 -to serdes_gpio1
set_location_assignment PIN_B6 -to serdes_gpio0
set_location_assignment PIN_B7 -to serdes_gpio2
set_location_assignment PIN_A7 -to serdes_gpio3
set_location_assignment PIN_D7 -to din0
set_location_assignment PIN_B8 -to din1
set_location_assignment PIN_C8 -to din2
set_location_assignment PIN_A9 -to din3
set_location_assignment PIN_E7 -to din4
set_location_assignment PIN_E9 -to din5
set_location_assignment PIN_D10 -to din6
set_location_assignment PIN_E10 -to din7
set_location_assignment PIN_A11 -to din8
set_location_assignment PIN_B11 -to din9
set_location_assignment PIN_B12 -to din10
set_location_assignment PIN_D11 -to din11
set_location_assignment PIN_B14 -to serdes_scl
set_location_assignment PIN_A14 -to pclk
set_location_assignment PIN_B15 -to serdes_sda
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

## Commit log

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2014-07-01 Eliminated 2nd non-gnd via under RHD, all remaining ones are ground and should not cause any issues. There's very likely still a bunch of cleaning to do in order to pass DRCs.
    [headstage.brd]
2014-07-01 Silkscreen updates and cosmetic fixes
    the ADXL accelerometer doesnt have a proper alignment mark silkscreen
    yet - probbaly needs to be added to the library
    [headstage.brd]
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2014-07-10 Fixed the design rules for the JMD headstage to fit OSH park's new tolerances. Added a BOM.
    [headstage.brd, headstage.sch]
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2015-01-31 Addressed Reid's issues with the previous design. This board is nearly ready for pre-prototyping at OSH park.
    [headstage.brd, headstage.sch]
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2017-03-23 eib-256 pin hole size fix and led-board
    - The eib-256 pcbs' pin hole sizes was too small before which caused fab
    house to use a smaller drill bit and gold pins did not fit in the holes.
    I've increased the hole size by a mil to see if this fixes the
    situation.
    - Added stencil for eib-256-panel since this time I will do the
    assembly...
    - Added gold pin datasheet.
    - Created a metal-core PCB (led-board) for making optrodes.
    - Updated README a bit.
    [eib-256.brd, eib-256.sch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]
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2017-07-30 Started adding spartan6 to headstage-64
    - Incomplete part, just checking spacing
    - Also added estim reset swtich to schematic
    [headstage-64.brd, headstage-64.sch]
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2017-08-06 Switched Spartan-6 for 10MAXDC
    - Much smaller footprint, embedded flash, and oscillator.
    - Starting to review power requriements etc
    [headstage-64.brd, headstage-64.sch]
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2017-08-10 Replaced x2y capacitors with multiple 0201 on headstage-64
    - Smaller overall area and easier to place.
    - Schematic improvements and fixes.
    [headstage-64.brd, headstage-64.sch]
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2017-09-04 More work on eib-245 nanoz adapter board
    - Hard routing done
    - Needs user pinout for power, ref, etc
    - Needs reverse polarity protection
    [eib-256-nanoz-adapter.brd, eib-256-nanoz-adapter.sch]
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2017-09-17 PCIe host board update
    - Fixed term indicator LED circuit so that it does not short DI lines to
    3.3V
    - Connectoed power indication LED to power
    - Fixed the LVDS driver footprints
    [pcie-host.brd, pcie-host.sch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]
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2017-09-24 mostly fixed RHD lvds routing - moved vias out from top layer footprints - added decoupling cap and testpoints
    [headstage-64.brd]
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2017-09-27 PCIe host board revision 1.1
    - Ready for fab
    - Fixed I2C part number: ISO1540 instead of ISO1541
    - More and larger testpoints
    - Improved silkscreen
    [pcie-host.GBL, pcie-host.GBO, pcie-host.GBS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]
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2017-10-03 Fixes during headstage-64 gerber check
    - Added pullup to NCONFIG
    - Realized that DATA4, and ENV1-4 are not routed. At least data4 needs
    to be routed.
    [headstage-64.brd, headstage-64.sch]
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2017-10-09 Headstage programmer modifications
    - Due to discussions with Jakob
    - Coin cell replaced with AAA battery
    - Orientation of programming pins rotated
    - JTAG connector removed to rear
    - Reverse polarity protection in case coax is plugged in during
    programming
    - Power switch
    - Flashlight LED on bottom
    [headstage-programmer.GBL, headstage-programmer.GBO, headstage-programmer.GBS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]
2017-10-09 Changes to pogo JTAG programming dimensions
    - Pins are now separated by 0.05 inches so that standard pins might be
    possible to use
    - There is not much clearance on the headstage-64 so we may still have
    to use tiny pogo pins
    - Fixed JTAG connectivity on headstage-64 by connecting +3V3 to
    VCC(TRGT) pad
    [headstage-64.brd, headstage-64.sch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]
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2017-10-18 Started a headstage-64 which uses BGA Intan chip
    - I put it in another file to facilitate comparisons with the wirebond
    version
    - It has errors that need to be resolved, but I didn't bother yet
    because we are likely moving the LVDS bank
    [headstage-64_bga.brd, headstage-64_bga.sch]
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2017-10-24 Replaced GPIO3 with PASS on pcie-host board
    - PASS pin from deserializer which goes low if errors are detected in
    the deserialed payload. This can be use to detect bad frames even when
    the lock to the serializer is maintained.
    [pcie-host.brd, pcie-host.sch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]
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2017-10-24 intan LVDS re-route WIP - routed LVDS pairs out from fpga, pins need to be swapped to straighten out assignments on intan end - moved R38 out from under fpga to make some room - 2do: have not routed 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
    [headstage-64_bga_true-lvds.brd, headstage-64_bga_true-lvds.sch]
2017-10-25 headsstage routing WIP - mostly done with SE signals, spacing iss till temporary but topology&overall layout should work - LVDS pairs make it to RHD chip, but pins need to be swapped on fpga to simpl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
    [headstage-64_bga_true-lvds.brd, headstage-64_bga_true-lvds.sch]
2017-10-27 finished rough layout-rework of LVDS and SE traces - got all signals to where they belong - 2do: trace spacing for long distance routing is still all over the place - 2do: the fpga escape pattern nee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
    [headstage-64_bga_true-lvds.brd]
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2017-11-03 Replaced 1.8V LDO with step-down converter
    - Should take care of thermal issues
    - introduces more routing fun
    - Also, fixed up some of the trace/space issues with Jakob's LVDS
    routing
    [headstage-64_bga_true-lvds.brd, headstage-64_bga_true-lvds.sch]
2017-11-05 Completed routing for true-lvds version of headstage-64
    - GPIO is an unrouted trace that will probably stay that way for a
    air-wire
    - Extensive rework of many portions of board
    - 1.8V is now from a tiny step down converter
    - This board is not production ready, i've started a checklist on slack
    to get it there
    [headstage-64_bga_true-lvds.brd, headstage-64_bga_true-lvds.sch]
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2017-11-06 Headstage-64 routing refinements
    - Update programmer to reflect switchee Vcoax/Gnd positions
    - AGND/GND sprinkles for thermal and noise considerations
    - Route optimization/simplificiation
    [headstage-64.brd, headstage-programmer.brd]
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2017-11-07 Minimum LDO Vin is 2V
    - The 1.2V LDO was being supplied with 1.8 volts, which will not work
    - Routed the 2.5V LDO to it. This should be OK because neither of these
    are under heavy load and the large step down from Vcoax is spread across
    2 devices.
    [headstage-64.brd, headstage-64.sch]
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2017-11-25 Fixing DRC errors in headstage 64
    - Got rid of castellated daughter board
    - Simplified schematic
    - Produced gerbers
    - Should be about ready to go
    [headstage-64.brd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]
2017-11-25 Routed ENV4 from the forth SteamVR module
    - A couple other ERC fixes
    [headstage-64.brd, headstage-64.sch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]
2017-11-27 fixed some small routing errors - one of the lighthouse IC signals wasnt making it to the fpgs - some small stubs left in V+ layer - relaxed some trace spacing
    [headstage-64.brd]
2017-12-03 Fixed missing 1.8v power intput to serializer in headstage-64
    - Added values to components missing them
    - Completed ERC and DRC
    - Should be ready for fab pending final checks by other ppl
    [eib-64.brd, headstage-64.brd, headstage-64.sch]
2017-12-07 Moved status LEDs away from serdes tether solder pads - moved one off to the right a bit - moved one next to FPGA, had to shift lighthouse sensor etc down by .2mm to do that. - still getting very min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
    [headstage-64.brd]
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2017-12-10 Modifications to test-board-64
    - Fixed stim electrode model passives replaced with sockets
    - LED A/C connections can be directed to sockets for testing other LEDs
    and laser diodes
    [test-board-64.brd, test-board-64.sch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]
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2017-12-14 Created led-flex-board
    - Useful for creating optrodes with either xlamp or direct attach
    micro LEDs
    - Flexible substrate
    - Also updated ridgid led-board's license
    [led-board.brd, led-board.sch, led-flex-board.brd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]
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2018-01-03 Minor fixes to nanoz-adapter-128-256
    - Silk screen instructions for DIP switch more explanitory
    - Fixed some wonky wiring in top layer due to previously moved part
    [eib-128-256-nanoz-adapter.brd, eib-128-256-nanoz-adapter.sch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]
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2018-01-20 Updated footprint of headstage-64 s-diode
    - It was too big for the 0402-sized part we are using an prevented
    proper reflow
    [headstage-64.brd, headstage-64.sch]
2018-01-27 Post assembly headstage-64 update
    - Small changes made after assembling first prototype of headstage-64
    - TLVxxx LDO's package/land patterns fixed
    - 0402 diode package fixed
    - Components that we found were likely to short were moved apart
    - Cream/solder mask improvements
    [headstage-64.brd, headstage-64.sch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]
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2018-02-03 Added a connection for estim power enable
    - I did not route it yet. I'm going to let other issues accumulate
    before doing that
    [headstage-64.brd, headstage-64.sch]
2018-02-06 Routed the missing estim power trace
    - Fixes issue mentioned in 7940a139
    - Created all gerbers etc
    [headstage-64.brd, headstage-64_via-reduce.brd, headstage-64_via-reduce.sch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]
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2018-03-06 More headstage-256 routing
    - Replace 1.8 step down module with more capable version that is
    actually available on DK
    [headstage-256.brd, headstage-256.sch]
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2018-03-11 Headstage-256 routing is complete
    - Passes DRC
    - Passes ERC
    - Probably still some issues need to have others look at it
    [headstage-256.brd, headstage-256.sch]
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2018-03-25 headstage-256 fixes during BOM creation
    - Consolodation of parts (lots of 0603s were moved to 0402)
    - NRF's antenna connection can use either MMCX or U.FL
    - BNO was given its own 32 kHz crystal
    [headstage-256.brd, headstage-256.sch]
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2018-04-07 Headstage-64 updates following testing
    - Added 50 MHz crystal oscillator to drive FPGA PLL
    - LED driver now gets serial data via common MOSI line instead of
    dedicated SDO. Clock line is still separate since it acts like the LED
    driver's clock and CS together.
    - LED driver's blank pin is now tied to CRC_ERROR/C5 on FPGA
    - Removed one status LED and instead routed serializer GPIO0 to FPGA
    - Increased size of programming pads
    [headstage-64.brd, headstage-64.sch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]
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2018-04-09 Fixes to headstage programmer
    - Added switch to turn off bottom LED
    [headstage-programmer.brd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]
2018-04-13 Updates due to production questions from speedy
    - Space added between some components
    - 3.3V stub removed from headstage-64
    - Intan AUXOUTs routed to test points on both boards
    - Crystal's re-routed to drive FPGA clock pins that interface with an
    avaialble PLL. Previous routing went to clock pins that had no PLL on
    both designs.
    - Some pins swapping to simplfy routing on both boards.
    [headstage-256.brd, headstage-256.sch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]
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2018-04-15 Lots of small fixes and cleanup
    - Taking care of little issues that have been bothering me
    - Dediated serdes interface board moved to deprecated
    - Non-serialized headstage moved to deprecated
    - Deleted top-level datasheets directory which does not really
    apply to anything anymore
    - Added pdfs versions of board schematics so that eagle is not
    needed to see them.
    - Small fixes to test-boards: High power LEDs moved to bottom to prevent
    blinding ppl. Silkscreen improved. License updated. Etc. Gerbers
    updated.
    - Removed random deprecated design files where I found them.
    [Consideration_hand_calcs.xlsx, Headstage_withFPGA_BGA.SchDoc, Spartan3A_Spartan6_XPE_14_3.xls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]
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2018-05-07 Incrreased the value of the estim discharge resistor
    - Circuit could become unstable if current still being passed when
    analog switch was closed. This fixes this issue.
    [headstage-256.brd, headstage-256.sch, headstage-64.brd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]
2018-05-18 Replaced stim null circuit on both headstages
    - ADG140x was replaced with dg509b, which is a 2 circuit 1-to-4 mux.
    This allows the electrode path to be completely disconnected from
    stimulation circuitry during idle periods. During idle periods,
    stimuluation output is shunted to ground through a dummy load so that
    offsets to not develop large voltages during idle periods.
    - Additionally, the inverting node of the estim current source amplifier
    is sent to the intan chip instead of the DAC voltage. This gives a true
    reflection of delivered current rather than just the control signal.
    [headstage-256.brd, headstage-256.sch, headstage-64.brd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]
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2018-05-21 Minor fixes following headstage-256 assembly
    - Corrected 0201 LED package
    - Moved a couple passives apart to reduce shorts
    [headstage-256.brd, headstage-256.sch, headstage-64.brd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]
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2018-07-09 headstage-256 rev 1.1
    - Should be ready for speedy
    - 8 layer board should fix radio-freq isolation issue on previous
    - Other small circuit modifications and fixes
    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
    [headstage-256.brd, headstage-256.sch, headstage-256_via-reduce.brd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]
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2018-07-16 Even more catious routing on headstage-256
    - Serializer digital lines completely avoid bias-t network's inductor
    and pads.
    [headstage-256.brd, headstage-256_via-reduce.brd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]
2018-07-18 pcie-host board rev. 1.2
    - Extra bidirectional isolator added to propogate LOCK and PASS signals from deserializer to host FPGA.
    - Immediate non-isolated and isolated SMA IO added.
    - Routed HSYNC to normal (LA) differential pins rather than dedicated
    clock input which was causing synthesis issues.
    [pcie-host.brd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]
2018-07-18 Added path the deserializer PDN input on host board
    - Tactile switch on panel
    - Path from host FPGA
    - Allows hard reset of deserializer
    [pcie-host.brd, pcie-host.sch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]
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2018-07-21 Minor fixes to pcie-host board during BOM updated
    - BOM simplification and correction
    - Some minor layout fixes
    [pcie-host.brd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]
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2018-07-23 More WIP routing on on headstage-64 - tried avoiding the area under the RF connector, still am intersecting the power decoupling section by a bit.
    [headstage-64.brd, headstage-64.sch]
2018-07-24 Routing WIP on headstage-64 -Cleaned up some more traces and swapped pins to move traces out from RF area, still need to clean up routing layer quite a bit
    [headstage-64.brd, headstage-64.sch]
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2018-08-10 Many fixes to new 8-layer routing
    - Replace ultra thin power traces
    - Proper z on differential pairs
    - Decoupling elements moved to corresponding ICs
    - Remove thin gnd wiring and use planes
    [headstage-64.brd, headstage-64.sch]
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2018-08-13 Some final changes to headstage-256
    - Replace UFL wirelss coax connector with IPEX connector
    - Ground plane improvements
    [headstage-256.brd, headstage-256.sch, headstage-256_via-reduce.brd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]
2018-08-15 Headstage-256 rev. 1.1
    - Ready for speedy
    - Moved the coax adapter boards to tabbed daughter boards on the
    headstage-256 PCB
    - Lots of small fixes during final DRC and gerber creation
    [coax-adapter.GBL, coax-adapter.GBO, coax-adapter.GBS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]
2018-08-16 headstage-64 ready for fabrication
    - Tiny improvements due to DRC and drill rack check
    - Fabrication files updated
    - Missing gerber files added
    - Gerbv project updated
    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
    [headstage-64.brd, headstage-64.sch, headstage-64_via-reduce.brd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]
2018-08-17 Moved parts around on headstage-64 to increase spaces between pads
    - Tried to jiggle parts around to prevent very closely spaced pads on
    difference signals. Hopefully this will reduce possibily of shorts
    during reflow.
    [headstage-64.brd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]
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2018-08-20 Fixed some incorrect trace names in pcie-host
    - No physical change to board, just fixes to net names
    - Updates pdf schematic
    [pcie-host.brd, pcie-host.sch]
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2018-08-22 More wire naming fixes to pcie-host
    - No changes to PCB layout
    - Schematic updated
    [pcie-host.brd, pcie-host.sch]
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2018-08-27 Many fixes on headstage-64 before fabriation
    - A bit of scary commit because I found significant errors in the board
    - There were redunant MOSI lines and a missing MISO line for the IMU.
    These were fixed. The extra line allowed GPIO1 from serializer to be
    routed to FPGA.
    [headstage-64.brd, headstage-64.sch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]
2018-08-27 Significant rework of headstage-256 before fabrication
    - No errors found, but improvements made
    - I decided to give wireless IO its own dedicated SPI bus for streaming
    applications. It would be difficult to MUX this bus for streaming and
    stimulation since it is shared between 7 chips at that point.
    - This reduced the amount of expansion IO by two lines (14 available).
    - I removed the ground plane cutouts under RF trace -- the risk of cross
    talk outweights characteristic impedance perfection.
    [headstage-256.brd, headstage-256.sch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]
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2018-09-10 Added ESD protection to host board and headstages
    - Host board has a high-voltage RC circuit between isolaed ground planes
    to prevent common-mode voltage accumulation on isolated side
    - TVS diodes are installed on headstage and host board sides to take
    care of ESD events.
    [headstage-256.brd, headstage-256.sch, headstage-64.brd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]
2018-10-01 Replace headstage-64 estim circuit with Howland design
    - Replace in-amp in feedback loop with an (improved) Howland current
    source.
    - +/-2.5 mA stim range
    - Increased resolution of DAC to 12 or 16 depending on specific part
    number.
    - 2.5V center reference provided by DAC. DAC produces 2*2.5V swing.
    - Howland created using one opamp of quad JFET-based opamp. Other 3 are
    used to make instrumentaiton amplifier to measure stim current.
    - No gerbers or spice added yet. Those are to come.
    [headstage-64.brd, headstage-64.sch]
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2018-10-07 headstage-256 rev 1.1 and headstage-64 rev. 1.2
    - These should be ready for fabrication
    - Extensive DRU and manual checking on both designs
    - Howland current source integrated into both designs
    - MPU9250 replace with ICM-20948 on headstage-64 since MPU is deprecated
    - Gerbers update and gerbv project files as well
    - Schematics of both headstages updated
    [headstage-256.brd, headstage-256.sch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]
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2018-11-17 WIP/concept: Swapped in the Bosch BNO055 - This required some major crimes against the DRC but illustrates what might be a viable layout - Major layout and routing revisions are needed - FPGA pinout 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
    [headstage-64_bno55.brd, headstage-64_bno55.sch]
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2018-12-21 Fixed swapped resistor values on Howland circuit
    - 9k and 10k resistors where swapped on the Howland current source
    porition of the estim circuit on headstage-256 and headstage-64
    - Also, I added an optional 1/10 Vcoax path to one of the analog inputs
    on headstage-256 to allow the host to monitor supply voltage over long
    cables.
    [headstage-256.brd, headstage-256.sch, headstage-256_via-reduce.brd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]
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2019-01-02 headstage-256 schematic renumber
    - Fixed incorrect labels for expansion headers on silkscreen
    - BOM is up to date for this version and component numbering
    - Schematic PDF updated
    [headstage-256.brd, headstage-256.sch, headstage-256_via-reduce.brd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]
2019-01-02 Fix errors in headstage-256 expansion boards
    - Headers were too close to receptacles in debug board
    - Some components did not have values
    - Added BOM to the google sheet based on this design
    [hs-256-expansion.brd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]
2019-01-02 Minor changes to headstage-64 while updating BOM
    - stencil size reduced for dfn diode packages to prevent shorting
    [headstage-64.brd, headstage-64.sch, headstage-64_via-reduce.brd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]
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2019-01-15 Replaced v-cut with tabs on headstage-256 expansion boards
    - Fab was unable to do a v-cut on a board this small
    [hs-256-expansion.GBL, hs-256-expansion.GBO, hs-256-expansion.GBS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]
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2019-01-24 Some fixes to analog breakout before fab
    - Unconnected wires
    - Silk overlaps
    [fmc-host-io-breakout.brd]
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2019-02-25 Fixed BNC footprin to be more permissive (larger holes) Added 2to grounded M6/1/3-20 holes Fixed some label alignment
    [fmc-host-io-breakout.brd, fmc-host-io-breakout.sch]
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2019-03-02 Fixed BNC footprint in analog-io-breakout -also added grounded mounting hole and fixed label spacing
    [analog-io-breakout.brd, analog-io-breakout.sch]
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2019-03-03 Improved fmc IO board layout and generated gerbers
    - Analog sinals on bottom and middle layers, instead of top where they
    interfere with ground plane and mechanical connections
    - Moved some fastener holes slightly so it will screw into 19" rack
    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
    [analog-io-breakout.GBL, analog-io-breakout.GBO, analog-io-breakout.GBS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]
2019-03-04 fmc-host updates after assembly
    - Mostly small layout changes to fix incorrect land patterns, shorts,
    etc.
    - Now we are using external reference for ADC and DAC instead of using
    ADC's
    [fmc-host.GBL, fmc-host.GBO, fmc-host.GBS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]
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2019-03-05 Final updates to fmc-host rev 1.1
    - Changes reflect issues found during assembly
    [fmc-host.GBL, fmc-host.GBO, fmc-host.GBS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]
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2019-05-07 Initial commit of 3d printed case for pcie fmc host Designed to slot into the FMC card and then screw into the numato board Many features and dimensions are still missing
    [WaveTherm-OC-PCB-FMC.SLDASM, WaveTherm-OC-PCB-FMC_OC-PCB-FMC.SLDPRT, WaveTherm-OC-PCB-FMC_SAMTEC_ASP-134488-01.sldprt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]
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2019-05-23 Updated fmc pcie case - Fixed screw hole sizes (hopefully) - Less 90s design - Changed to 12mm FMC stack height
    [fmc_host_pcie_case.SLDPRT, fmc_host_pcie_case.STL]
2019-07-14 lighthouse sync booster rev. 1.0
    - This is a drop in replacement for the standard HTC Vive basestation
    LED syc array board
    - It uses 120 high power IR LEDs
    - It should plug directly into the flat-flex cable within the
    basestation wihout any modification or hacking other than replaceing the
    array, which involves removing the front cover
    [lighthouse-booster.GBL, lighthouse-booster.GBO, lighthouse-booster.GBS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]
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2019-07-28 Lighthouse-booster Rev. 1.1
    - Minor fixes to version 1.0 after testing
    - Replaced 0 ohm jumpers between gate driver and gate with 47 kOhm
    pulldowns to prevent possible DC damage to LEDs when board is not
    driven
    - Decrease current limit resistors to 360 mOhm. This should give us 5
    Amps per LED string after empirical testing
    - Fixed mis-aligned guide hole placement
    [lighthouse-booster.GBL, lighthouse-booster.GBO, lighthouse-booster.GBS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]
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2019-07-29 Address Filipe's issues with eib-64 prior to fabrication
    - Move mouse bites on panel away from connector since it will be hard to
    sand under there.
    - Reduce ground planes around mouse bites to prvent exposued copper
    after sanding.
    - Adde "Open Ephys" to bottom silk.
    [eib-64.brd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]
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2019-08-09 Added LMK61E2
    Should solve the issue of how to make 93.6 MHz, but is pretty huge
    [headstage-neuropix-64.brd, headstage-neuropix-64.sch]
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2019-08-15 Small fixes to silk layer on fmc-host rev 1.1
    - Should be ready for fabrication
    - Added some gerber art to gerber folder
    [fmc-host.brd, fmc-host.sch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]
2019-08-15 Removing and depricating obsolete designs
    - Remove pcie-analog-io folder because its an obsolete design
    - Deprecate analog-io-breakout since its being replaced with general
    purpose breakout board
    [analog-io-breakout.GBL, analog-io-breakout.GBO, analog-io-breakout.GBS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]
2019-08-15 Removing and deprecating obsolete designs
    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
    [analog-io-breakout.GBL, analog-io-breakout.GBO, analog-io-breakout.GBS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]
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

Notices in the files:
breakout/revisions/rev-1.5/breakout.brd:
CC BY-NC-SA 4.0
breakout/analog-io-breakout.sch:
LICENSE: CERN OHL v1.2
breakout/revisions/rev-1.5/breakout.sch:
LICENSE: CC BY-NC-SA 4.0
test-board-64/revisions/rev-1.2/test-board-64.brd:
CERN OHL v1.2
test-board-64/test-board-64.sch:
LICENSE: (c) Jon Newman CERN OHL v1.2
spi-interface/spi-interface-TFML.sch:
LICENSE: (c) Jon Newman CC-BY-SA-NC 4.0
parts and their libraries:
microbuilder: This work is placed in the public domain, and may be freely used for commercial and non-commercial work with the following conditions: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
